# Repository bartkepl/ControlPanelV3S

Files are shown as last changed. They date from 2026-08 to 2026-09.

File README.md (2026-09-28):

# ControlPanelV3S — Hardware

KiCad project for the CAN-bus control panel board built around the Allwinner V3S (LicheePi Zero),
part of the [CANbusSensors](../) family of MPCC/MPSWP sensor-node projects. Two assembly variants
on one PCB: a handheld CAN-bus terminal and a VoIP endpoint. The next hardware iteration (Allwinner
T113-S3/4) will be a separate repo.

## Status: ready for prototype order

- Schematic and PCB layout done (4-layer, 120 × 75 mm), production files generated.
- Design review completed; DRC/ERC clean (remaining items reviewed and excluded as by-design).
- Hand assembly (2 fiducials on F.Cu for stencil alignment); crystal load caps C3/C4 are placeholders to be tuned at bring-up.

Production outputs: [schematic PDF](prod/sch/ControlPanel.pdf) · [PCB PDF](prod/pcb/ControlPanel.pdf) · [interactive BOM](prod/ibom/ControlPanel_ibom.html) · [gerbers](prod/ControlPanelV3S.zip)

## Renders

3D renders straight out of KiCad (`pcb/gen_media.kicad_jobset`), not photos — no boards have been
fabricated yet.

| Top | Bottom | Angle |
|---|---|---|
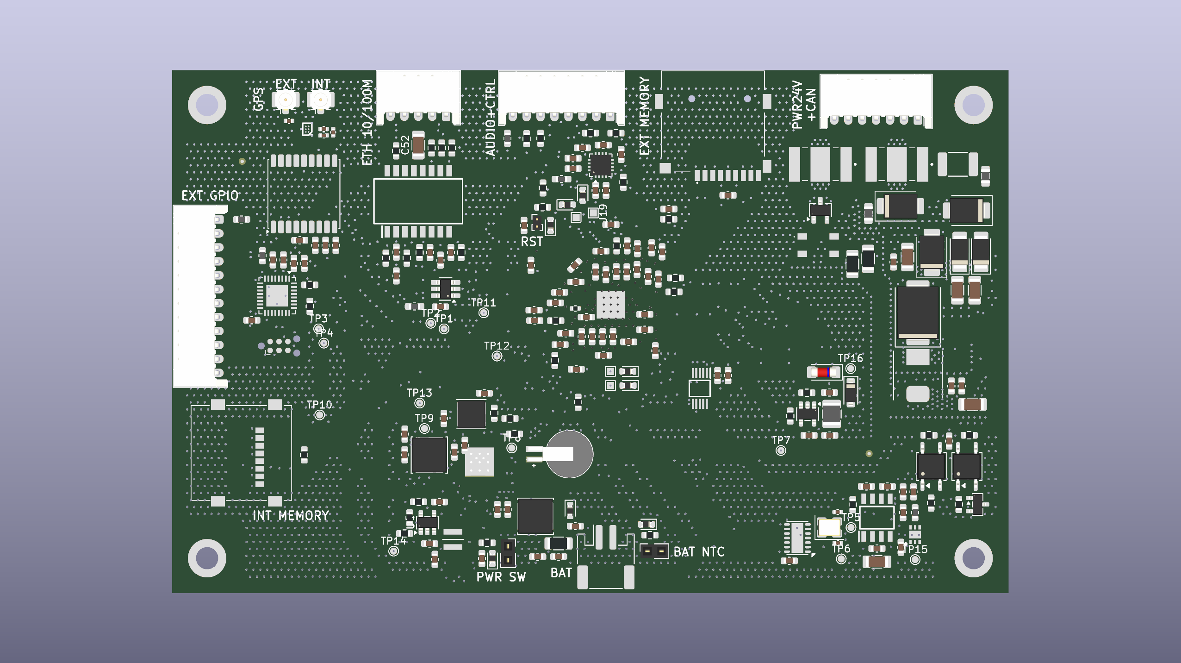
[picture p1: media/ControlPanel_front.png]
Top
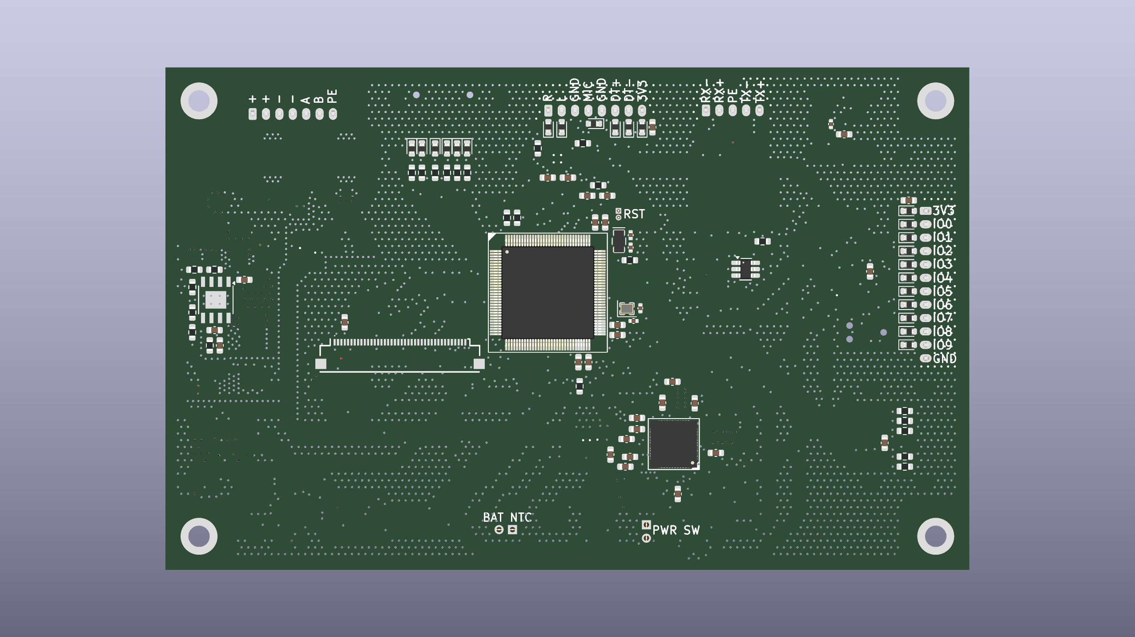
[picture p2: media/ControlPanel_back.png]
Bottom
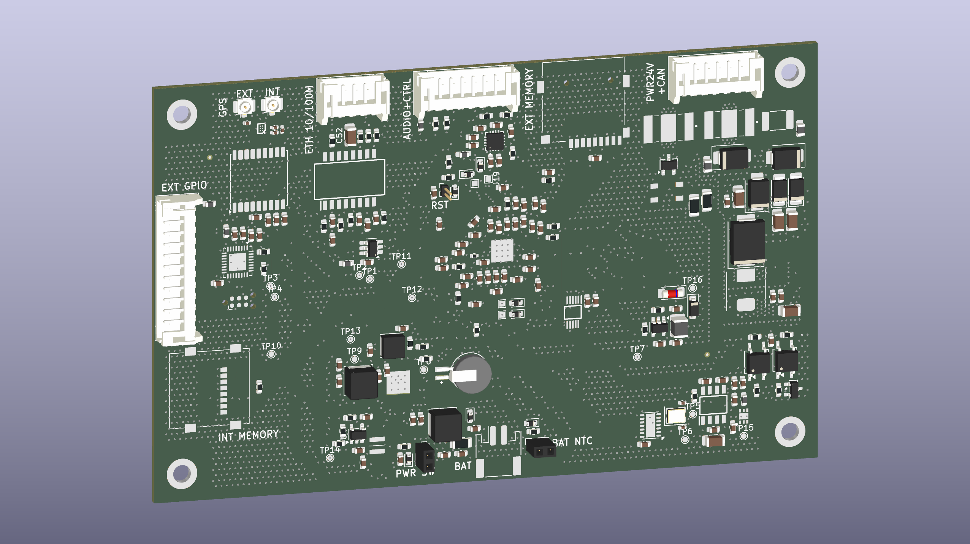
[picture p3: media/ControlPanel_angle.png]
Angle
|  |  |  |

## Layout

- **`pcb/`** - KiCad project: CPU, power, CAN transceiver front-end, display/touch, GPS, Ethernet,
  audio.
- **`doc/`** - hardware design decisions and reference material. Start with
  [doc/README.md](doc/README.md), which says which document is the source of truth for what.
- **`media/`** - 3D renders of the board, generated from the KiCad project.
- **`prod/`** - fabrication outputs (gerber + drill zip, BOM, interactive BOM, schematic/PCB PDFs).

## Firmware

The firmware that runs on this board (V3S-side kiosk app, CAN-bus device monitor, offline
navigation/map stack) lives in a separate, currently private companion repo.

## License

MIT for original work - see [LICENSE](LICENSE). All footprints live under `pcb/local_lib/` and
were either authored locally or sourced from SamacSys (`BAT_MS621FE-FL11E.kicad_mod`); 
FunKey S is referenced in `doc/` as a comparison point for the Allwinner V3S reference design 
(e.g. power-tree, boot ROM behavior).

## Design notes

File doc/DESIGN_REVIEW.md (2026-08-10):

# ControlPanel V3s — przegląd projektowy

**Projekt:** ControlPanel (KiCad 10.0.4, 11 arkuszy hierarchicznych, PCB 4-warstwowe 120 × 75 mm)
**Data:** 2026-08-01 (przebieg 3, 15:38)
**Analizatory:** `analyze_schematic.py`, `analyze_pcb.py --full`, `cross_analysis.py`,
`analyze_emc.py`, `analyze_thermal.py`, `simulate_subcircuits.py` (**ngspice**),
`diff_analysis.py` — oraz natywne **KiCad DRC/ERC** przez `kicad-cli 10.0.4`
**Wyniki surowe:** `analysis/2026-08-01_1538/`

---

## Werdykt

**Płytka jest elektrycznie i topologicznie gotowa.** Trzy niezależne mechanizmy kontroli są czyste:
KiCad ERC 0 naruszeń, KiCad DRC 0 elementów niepołączonych i 0 rozjazdów ze schematem,
ngspice 78/80 przebiegów pass bez ani jednego `fail`. Wszystkie blokery z poprzednich dwóch
przebiegów zostały naprawione i zweryfikowane w plikach.

**Do produkcji brakuje jednej rzeczy obowiązkowej: numerów MPN** (38 / 106 unikalnych części, 35,8 %).
Bez tego nie da się złożyć zamówienia ani zweryfikować pinoutów wobec kart katalogowych.

Poza tym otwarte pozostają wyłącznie pozycje jakościowe: jedna realna kolizja obrysów,
brak fiducialów, brak punktów testowych i brak oznaczeń na płytce.

---

## Przegląd

Terminal sterujący na SoC **Allwinner V3S** (U2, LQFP-128, DDR2 w obudowie) z PMIC **AXP209** (U7)
i koprocesorem **STM32L432KC** (U5). Peryferia: CAN FD (MCP2518FD + ATA6561 z przełączaną
programowo terminacją na przekaźnikach PhotoMOS), Ethernet 100BASE-TX przez wewnętrzny EPHY V3S
i magnetykę H1102NL, GPS MAX-M10S z LNA MAX2674, wzmacniacz słuchawkowy TPA6132A2, kontroler
dotyku NS2009, LCD RGB666 przez FPC 40-pin, dwa sloty microSD, zasilanie 9–60 V przez buck TPS54360.

309 komponentów (219 top / 90 bottom), 100 % SMD, 242 sieci, 5016 mm ścieżek, 3182 przelotki.

---

## Delta wobec poprzednich przeglądów

| Metryka | Przebieg 1 (00:28) | Przebieg 2 (15:03) | **Przebieg 3 (15:38)** |
|---|---|---|---|
| KiCad DRC — naruszenia | 16 | 26 | **12** |
| KiCad DRC — niepołączone | 0 | **2** | **0** |
| KiCad DRC — zwarcia | 0 | **8** | **0** |
| KiCad ERC | 0 | 0 | **0** |
| `cross_analysis` | 21 | 61 | **20** |
| `XV-002` (rozjazd wartości sch↔PCB) | — | 41 | **0** |
| PCB — zgłoszenia | 218 | 133 | **133** |
| SPICE | brak (LTspice = same skip) | 78/80 pass | **78/80 pass** |
| Przecinki dziesiętne w BOM | 23 | 3 | **0** |
| Pokrycie MPN | 35,2 % | 35,2 % | **35,8 %** |

### Naprawione i zweryfikowane w plikach

| Pozycja | Weryfikacja |
|---|---|
| **Y2 → kwarc 24 MHz** | `CX2016FB24000D0FZZ` (Kyocera, 24,000 MHz), footprint zmieniony na `Crystal_SMD_2016-4Pin_2.0x1.6mm`. Pozycja 36 mm od krawędzi — wymóg design guide V3S ≥ 25 mm zachowany. |
| **LDO24IN / LDO3IN AXP209** | Pady 13 i 40 `U7` → `IPSOUT`. Zapas napięcia dla LDO2/3/4 i PSRR dla GPS odzyskane. |
| **8 zwarć GND ↔ `/AUDIO/DATA-/GPIO1`** | `shorting_items` = 0. Przelotki zszywające przestały kolidować ze ścieżką In1.Cu. |
| **GPS `UART2_RX`/`UART2_TX`** | Pady 2 i 3 `U6` mają przypisane sieci, `unconnected_items` = 0, `track_dangling` = 0. |
| **Synchronizacja schemat → PCB** | `XV-002`: 41 → **0**. `C131` ma teraz `2.2u` po obu stronach. |
| **Przecinki dziesiętne** | 23 → 3 → **0**. Analizator poprawnie parsuje `32.768kHz`, ngspice potwierdził CL Y3 = 6,1 pF. Wykrywalność dzielników wzrosła z 4 do 7. |
| **Rozjazdy footprintów** | 7 → **3** (`R57`, `R68`, `R69`, `D43` naprawione; zostały `T1`, `U11`, `D42`). |

### ⚠ Sprostowanie do przeglądu nr 2

W poprzednim raporcie napisałem, że nakładki obrysów zostały naprawione („14 → 0, `PM-001`
zniknęło całkowicie"). **To było błędne.** Wyciągnąłem ten wniosek z porównania, które wypisywało
wyłącznie *zmienione* reguły — brak `PM-001` na liście oznaczał, że nic się nie zmieniło, a nie
że problem zniknął. Zestaw `PM-001` jest **identyczny we wszystkich trzech przebiegach**:
1 error + 13 warning + 3 info, ta sama lista par. Pozycja wraca jako otwarta.

Analogicznie `VP-001` (przelotki w padach): zestaw jest bit w bit taki sam jak w przebiegu 2 —
26 wystąpień, 21 unikalnych, żadne nie ubyło ani nie przybyło. W całym pliku `.kicad_pcb`
występuje jeden token `tenting`. Odnotowuję bez rozstrzygania, czy poprawka miała inny charakter
niż mierzy analizator.

---

## Wyniki krytyczne

| Waga | Problem | Sekcja |
|---|---|---|
| **BLOKER PRODUKCYJNY** | Pokrycie MPN 38 / 106 (35,8 %) — nie da się zamówić ani zweryfikować pinoutów | [Sourcing](#sourcing) |
| **WARNING** | Kolizja obrysów `C16` ↔ `J3` (2,321 mm²) — jedyna nakładka na poziomie error | [Rozmieszczenie](#rozmieszczenie) |
| **WARNING** | Brak fiducialów na obu stronach (219 + 90 elementów SMD, BGA 0,4 mm) | [DFM](#dfm-i-uwagi-produkcyjne) |
| **WARNING** | 0 punktów testowych na 232 sieci | [Testowalność](#testowalność) |
| **SUGESTIA** | Szyny `+3V3` (DCDC3) i `+3.3V` (LDO4) różnią się tylko kropką | [Drzewo zasilania](#drzewo-zasilania) |
| **SUGESTIA** | Brak nazwy płytki i oznaczenia rewizji (`board_text_count: 0`) | [Silkscreen](#silkscreen) |

Brak wyników na poziomie CRITICAL. Wszystkie trzy blokery z przeglądu nr 1 i cztery regresje
z przeglądu nr 2 są zamknięte.

---

## Weryfikacja natywna KiCad

Najmocniejszy dowód w przeglądzie — silnik łączności KiCada, nie heurystyka analizatora.

```
kicad-cli pcb drc --severity-all  →  12 naruszeń, 0 niepołączonych, 0 rozjazdów ze schematem
kicad-cli sch erc --severity-all  →  0 naruszeń
```

Wszystkie 12 naruszeń to kwestie kosmetyczne lub biblioteczne:

| Typ | Liczba | Szczegóły |
|-----|---|---|
| `silk_edge_clearance` | 7 | Opis `J13` przycięty krawędzią płytki |
| `lib_footprint_mismatch` | 3 | `T1`, `U11`, `D42` |
| `text_height` | 2 | `U2` i `U4` — 0,579 mm przy minimum 0,8 mm |

ERC ma wyłączone tylko 3 reguły (`footprint_filter`, `four_way_junction`, `simulation_model_issue`),
więc „0 naruszeń" ma realną wartość dowodową.

### Czego DRC nadal nie sprawdza

W `.kicad_pro` część ograniczeń jest ustawiona na zero — odpowiednie testy nie mają czego łamać:

| Reguła | Ustawienie | Konsekwencja |
|---|---|---|
| `min_copper_edge_clearance` | 0,0 mm | Miedź może dotykać krawędzi (świadoma decyzja — producent cofnie wylewkę) |
| `solder_mask_to_copper_clearance` | 0,0 mm | Brak kontroli maski względem miedzi |
| `min_connection` | 0,0 mm | Brak kontroli szerokości połączenia z polem |

Dodatkowo wyłączone: `silk_overlap`, `silk_over_copper`, `missing_courtyard`,
`footprint_type_mismatch`, `track_not_centered_on_via`, `footprint_filters_mismatch`.

---

## Podsumowanie komponentów

| Typ | Liczba |
|-----|---|
| Kondensatory | 137 |
| Rezystory | 69 |
| Diody (w tym TVS/GDT) | 40 |
| Układy scalone | 17 |
| Złącza | 14 |
| Cewki / koraliki ferrytowe | 7 / 7 |
| Kwarce | 3 |
| Pozostałe (transformator, bateria, bezpiecznik, tranzystor, filtr, TP, otwory montażowe) | 15 |

**309 komponentów, 105 unikalnych, 4 oznaczone DNP.**
Obudowy: 0603 × 222, 0402 × 12, 1206 × 9, SOT-23 × 6, QFN × 4, SOP/SOIC × 5, LQFP × 1,
**BGA × 1**, 1210/1812 × 2. Złożoność montażu **40/100**, 18 elementów trudnych, 62 unikalne footprinty.

---

## Drzewo zasilania

```
J12 (pin 1,2) ── F1 (PTC 2A) ── FB2 ── D8 ∥ D11 (PMEG6030EP, ochrona odwrotnej polaryzacji)
   │                                       │  D7/D10 (SMBJ36A TVS)
   │  GD1 (GDT 3R090-5S) → Earth           ▼
   │  D5 (SMBJ33CA)                     DC_IN  (9–60 V)
   │                                       │
   └── (pin 3,4) ── FB4 ── GND             ▼
                                  U3 TPS54360  buck, fsw ≈ 597 kHz (R34 = 162k)
                                    FB: R36 53.6k / R37 10.2k, Vref 0,8 V
                                    → Vout = 0,8 × (1 + 53,6/10,2) = 5,004 V  ✓
                                    EN: R38 523k / R39 84.5k → Von ≈ 9,3 V / Voff ≈ 7,5 V
                                       │
                                    ACIN 5,0 V
                                       │
                                 U7 AXP209 (PMIC, sterowany po I2C TWI1)
                                       │
                                    IPSOUT ──┬── U4 SY8088 buck → +1V8 (VCC-DRAM ×12)
                                             │      FB: R32 200k / R33 100k, Vref 0,6 V
                                             │      → 0,6 × 3 = 1,800 V  ✓ (ngspice: Vfb 0,600 V)
                                             │      EN: R31 100k pull-up z +3V0
                                             │
                                             ├── DCDC2 → +1V25   (VDD-CPU ×8, VDD-SYS ×6)
                                             ├── DCDC3 → +3V3    (VCC-IO ×4, VCC-PE ×2, VCC-USB,
                                             │                    VCC-MCSI, HPVCCIN, NS2009, U8)
                                             ├── LDO1  → +3V3_AO (VCC-RTC, GPS V_BCKP)
                                             ├── LDO2  → +3V0    (AVCC, VCC-PLL)          ✓ z IPSOUT
                                             ├── LDO3  → +3V3_GPS (MAX-M10S)              ✓ z IPSOUT
                                             └── LDO4  → +3.3V   (STM32, MCP2518FD,
                                                                  ATA6561 VIO, TPS61240)  ✓ z IPSOUT

    +3.3V ── IC2 TPS61240 boost → +5V (ATA6561 VCC, sterowanie PhotoMOS)
    +3V3  ── U8 TPS61041 boost  → VLED+ (podświetlenie LCD), FB przez R42 62 Ω
                                   ILED = 1,233 V / 62 Ω = 19,9 mA, D3 BZV55C24 jako klamra
```

**Wejścia LDO2/LDO3/LDO4 są teraz zasilane z `IPSOUT`** — zgodnie z `doc/AXP209_PINOUT_ROZPISKA.md`
(w. 145 i 169). W przeglądzie nr 1 były podpięte do wyjścia DCDC3, co dawało LDO3 i LDO4 zerowy
zapas napięcia (3,3 V → 3,3 V) i kasowało PSRR na szynie GPS. Naprawione.

### Uwaga do nazewnictwa

`+3V3` (DCDC3, 39 pinów zasilających) i `+3.3V` (LDO4, 14 pinów) to dwie różne szyny o nazwach
różniących się jedną kropką. Dokumentacja projektu sygnalizuje to sama
(`AXP209_PINOUT_ROZPISKA.md` w. 374). Przy każdej przyszłej zmianie to realne ryzyko podłączenia
czegoś do niewłaściwej szyny 3,3 V. Propozycja: `+3V3_IO` / `+3V3_CAN`.

---

## Weryfikacja symulacyjna (ngspice)

`D:\Spice64\bin\ngspice.EXE`, **80 symulacji w 7,7 s: 78 pass, 2 warn, 0 fail, 0 skip.**

| Kategoria | Liczba | Wynik |
|---|---|---|
| Filtry RC | 22 | wszystkie w granicach błędu **0,23–0,35 %** |
| Dzielniki napięcia | 4 | `R27/R28` → 0,900 V · `R32/R33` → 0,600 V · `R6/R7` → 0,0971 V (błąd 0,001 %) |
| Sprzężenie zwrotne regulatora | 1 | `R32/R33` (SY8088) → Vfb 0,600 V, błąd **0,0 %** → **Vout 1,800 V potwierdzone** |
| Kwarc | 1 | `Y3` 32 768 Hz, CL = 6,1 pF |
| Odsprzęganie | 11 szyn | impedancje niżej |
| Prąd rozruchowy | 5 szyn | wszystkie ustalają się na wartości docelowej, szczyty 28–107 mA |
| Tranzystor | 1 | `Q2` (BSS138): Vth 1,542 V, Ion 3,3 mA |
| Urządzenia ochronne | 33 | pass |
| Filtry LC | 2 | **2 × warn — fałszywe, patrz niżej** |

Impedancje odsprzęgania (minimum modułu):

| Szyna | Z_min | Szyna | Z_min |
|---|---|---|---|
| IPSOUT | 4,5 mΩ | +1V8 | 12,6 mΩ |
| ACIN | 5,9 mΩ | +3V0 / +3V3_GPS | 18,5 mΩ |
| +1V25 | 7,7 mΩ | +3.3V | 19,0 mΩ |
| +5V | 8,0 mΩ | +BATT | 31,6 mΩ |
| +3V3 | 9,1 mΩ | **+3V3_AO** | **67,2 mΩ** |

`+3V3_AO` jest najsłabsza, ale to szyna always-on zasilająca wyłącznie VCC-RTC V3S i V_BCKP
modułu GPS — pobór rzędu mikroamperów, impedancja bez znaczenia.

**Oba ostrzeżenia są fałszywe.** `L10/C12` i `L10/C21` wykryte jako filtr LC o Q = 115
i szczycie +40 dB przy 23,2 / 73,4 kHz. `L10` (4,7 µH) to dławik przetwornicy ładowarki AXP209
na węźle LX1, nie filtr — w rzeczywistości tłumią go pętla regulacji AXP209 i impedancja
akumulatora, których model ideal-passive nie uwzględnia.

---

## Analiza sygnałowa

### Ethernet 100BASE-TX

Standardowa topologia dla wewnętrznego EPHY V3S (jak Lichee Zero / FunKey S), prześledzona
sieć po sieci:

```
U2.89–92 (ETH_RX_N/P, ETH_TX_N/P)
   ├─ RX: → U10 (USBLC6) → RD+/RD− → C73/C83 (6.8n, sprzężenie AC) → T1.6/T1.8
   │       bias: T1.7 (RD CT) → R13/R15 (82 Ω) → RD+/RD−, C45 do masy
   └─ TX: → U9 (USBLC6) → TD+/TD− → T1.1/T1.3
           bias: +3V3 → FB1 → węzeł → R17 (10 Ω) → T1.2 (TD CT)
                 R14/R16 (49.9 Ω) → TD−/TD+
                 ten sam węzeł zasila piny VBUS U9 i U10 (odniesienie klamry) ✓

Strona liniowa: T1.9/11 (RX±), T1.14/16 (TX±) → J13
Bob Smith: R20/R26 (150 Ω) z RX± + R18/R19 (75 Ω) z T1.10/T1.15 → węzeł → C52 (1n/2kV) → Earth
```

Dopasowanie par:

| Para | Rozjazd | Ocena |
|---|---|---|
| `ETH_TX_P` / `ETH_TX_N` | asymetria przelotek 0 vs 2, przejść warstw 1 vs 2 | zamknięte decyzją — bez znaczenia dla 10/100M |
| `/ETH/RD+` / `RD−` | 2,1 mm (30 %) | w tolerancji 100BASE-TX |
| `/ETH/TD+` / `TD−` | 2,3 mm (27 %) | w tolerancji 100BASE-TX |

### CAN FD

```
U2 (SPI: PC0–PC3) → U1 MCP2518FD (Y1 20 MHz ✓, VDD +3.3V)
                  → IC3 ATA6561 (VCC +5V, VIO +3.3V — logika odniesiona do VIO ✓)
                  → R44/R45 (10 Ω pulse-proof) → FL1 (dławik wspólny) → GD2 → J12.5/J12.6
                     C40/C41 (4.7p) do masy, D9 CDSOT23-T24CAN przy złączu

Terminacja przełączana programowo:
   CAN_H → R22 (59 Ω) → U701 (PhotoMOS) → węzeł ── C39 (4.7n) → GND
   CAN_L → R21 (59 Ω) → U702 (PhotoMOS) → węzeł
   Razem 118 Ω — terminacja dzielona z bypassem AC
   Sterowanie: +5V → R23 (560 Ω) → LED U701 → LED U702 (szeregowo)
```

### Pozostałe interfejsy

| Interfejs | Realizacja | Stan |
|---|---|---|
| I2C (TWI1) | V3S PE21/PE22 + STM32 PB6/PB7 + NS2009 + AXP209, pull-upy `R10`/`R11` 2,2 kΩ do +3V3 | ✓ zgodne z kartą AXP209; multi-master świadomy (STM32 jako slave z przerwaniem) |
| USB | `U2.110/111` → `J19`/`J20` (pady testowe 1 × 1 mm), TVS `D24`/`D25` 2,2–2,9 mm | tylko do trybu FEL, świadome |
| LCD | RGB666 przez FPC 40-pin `J9`, masy rozłożone równomiernie | ✓ |
| microSD ×2 | `J1` (SDC1) i `J2` (SDC0) | ✓ |
| Audio | TPA6132A2 + `J14` (8-pin, masy na pinach 3 i 5, przeplecione) | ✓ |
| GPS | MAX-M10S + LNA MAX2674, UART2 do V3S | ✓ połączenie przywrócone |
| Debug | `J11` TC2030 (SWD do STM32), `J16`/`J17` (UART0 V3S) | ✓ |

### Kwarce

| Ref | Wartość | Podłączenie | Kondensatory | Ocena |
|-----|---|---|---|---|
| `Y2` | **CX2016FB24000D0FZZ (24 MHz)** | `U2.74` X24MOUT / `U2.75` X24MIN | `C3`, `C4` = 18 pF | ✓ naprawione |
| `Y1` | 3225-20M-SR (20 MHz) | `U1.5`/`U1.6` (MCP2518FD) | `C1`, `C2` = 18 pF | ✓ 20 MHz poprawne dla MCP2518FD |
| `Y3` | 32.768 kHz (WTL1X80739BEL) | `U2.95`/`U2.96` | `C48`, `C49` = 6,2 pF | ✓ ngspice: CL 6,1 pF |

`Y2` leży 36 mm od krawędzi przy wymogu ≥ 25 mm z design guide V3S. Wartości `C3`/`C4` (18 pF)
warto skonfrontować z CL nowego kwarcu przy okazji uzupełniania MPN.

---

## Analiza zasilania

### Odsprzęganie

| Szyna | Kondensatorów | Pinów `power_in` | Wartości |
|---|---|---|---|
| +1V8 (VCC-DRAM) | 8 | 17 | 4 × 100n, 2 × 1u, 2 × 10u |
| +1V25 (VDD-CPU/SYS) | 14 | 27 | 6 × 100n, 4 × 1u, 3 × 10u, 1n |
| +3V3 (VCC-IO) | 19 | 39 | 14 × 100n, 3 × 10u, 1u, 1n |
| +3.3V | 8 | 14 | 5 × 100n, 1u, 2.2u, 4.7u |
| +3V0 | 4 | 8 | 2 × 100n, 4.7u, 10u |
| +3V3_GPS | 4 | 4 | 2 × 100n, 4.7u, 10u |
| +3V3_AO | 3 | 6 | 2 × 100n, 1u |
| +5V | 3 | 3 | 100n, 4.7u, 10u |
| IPSOUT | 9 | 12 | 7 × 10u, 2 × 220n |
| ACIN | 4 | 4 | 100n, 3 × 10u |
| +BATT | 2 | 3 | 10u, 1u |

Szyna `+1V8` ma 4 × 100 nF na 12 pinów VCC-DRAM V3S — poniżej guideline'u Allwinnera
(~1 × 100 nF na pin) i zgodnie ze zgłoszeniem EMC `PD-001`. **Zamknięte decyzją projektanta**
(rozwiązanie zgodne z inną, działającą płytką) — odnotowane, nie otwieram ponownie.

### Odległości kondensatorów odsprzęgających

`C85` @ `U7` 0,21 mm · `C109` @ `U2` 0,21 mm · `C120` @ `U5` 0,24 mm · `C31` @ `U9` 0,28 mm —
bardzo dobrze. Kondensatory TPA6132A2 (`C129`/`C130`/`C131`) w promieniu 2,9–3,6 mm przy
wymaganych przez TI 5 mm ✓.

Nowe zgłoszenie **`DC-003`**: `C37` (100 nF na `+3V3_GPS`) leży daleko od przelotki masy.
Przy odsprzęganiu układu RF warto dołożyć przelotkę bezpośrednio przy padzie masy.

---

## Analiza PCB

### Stackup

| Warstwa | Typ | Grubość | Wykorzystanie |
|---|-----|---|---|
| F.Cu | signal | 0,035 mm | 1273 segmenty |
| prepreg 7628 | εr 4,4 | 0,2104 mm | |
| In1.Cu | signal | 0,0152 mm | 224 segmenty wewnątrz wylewki GND |
| core | εr 4,6 | 1,065 mm | |
| In2.Cu | power | 0,0152 mm | 1 segment — praktycznie lita płaszczyzna |
| prepreg 7628 | εr 4,4 | 0,2104 mm | |
| B.Cu | signal | 0,035 mm | 1067 segmentów |

Suma **1,586 mm** (standard 1,6 mm). Wykończenie **HAL lead-free** — świadoma decyzja
(montaż ręczny, koszt ENIG). Wylewka GND obejmuje wszystkie cztery warstwy; nie ma dedykowanej
płaszczyzny zasilania, wszystkie szyny prowadzone ścieżkami.

`In1.Cu` niesie 224 segmenty w 24 sieciach wewnątrz wylewki GND, co wycina szczeliny
w płaszczyźnie odniesienia dla sygnałów na F.Cu odległej o 0,21 mm. To źródło zgłoszeń
`GP-001` (52 error + 54 warning) i `SU-001`. **Zamknięte decyzją projektanta** — przeniesiono
na B.Cu co się dało, resztę obudowano przelotkami zszywającymi.

### Przelotki

| Rozmiar (średnica / otwór) | Liczba | Pierścień |
|---|---|---|
| 0,6 / 0,3 mm | 3125 | 0,15 mm |
| 0,4 / 0,3 mm | 57 | 0,05 mm |

Obie geometrie mieszczą się w bieżących możliwościach JLCPCB, który formułuje ograniczenie
jako **różnicę** średnicy i otworu, nie jako pierścień:

> Via diameter should be **0.1 mm** (0.15 mm preferred) larger than Via hole size.

0,4 − 0,3 = 0,1 mm → minimum spełnione. Opcja zamówienia `0.3mm/(0.4/0.45mm)` jest domyślna
i bez dopłaty. Nota o wyższej cenie dotyczy tylko otworów 0,15 mm oraz 0,2/0,25 mm ze średnicą
< 0,45 mm — tu otwór to 0,3 mm.

> ⚠ **Ograniczenie 0,1 mm jest specyficzne dla JLCPCB.** PCBWay wymaga pierścienia ≥ 0,1 mm
> (różnicy 0,2 mm) — tam te 57 przelotek nie przeszłoby. Przy zmianie producenta sprawdzić ponownie.

### Rozmieszczenie

219 elementów na F.Cu, 90 na B.Cu, gęstość 2,4 / 1,0 na cm². Na spodzie leżą najważniejsze
układy: `U2` (V3S), `U7` (AXP209), `U3` (TPS54360), `J9` (FPC LCD), `U9`.

**Nakładki obrysów — 17 par, niezmienione we wszystkich trzech przebiegach:**

| Para | Powierzchnia | Waga |
|---|---|---|
| **`C16` ↔ `J3`** | **2,321 mm²** | **error** |
| `U701` ↔ `C32` / `C39`, `U702` ↔ `C39` | 0,71–0,77 mm² | warning |
| `J4` ↔ `J3`, `C131` ↔ `U11`, `U5` ↔ `C117`, `D30` ↔ `J3`, `R40` ↔ `J3` | 0,18–0,41 mm² | warning |
| `FB2`/`GD1` ↔ `F1`, `IC2` ↔ `C47`, `C35` ↔ `IC3`, `R4` ↔ `BT1` | < 0,02 mm² | warning |
| `U6` ↔ `C36`/`C37`/`C38` | 0,007 mm² | info — obrys `U6` zawiera strefę zakazu RF, nie kolizja mechaniczna |

Realnego sprawdzenia wymaga wyłącznie **`C16` ↔ `J3` (2,321 mm²)** — reszta to zbyt hojne
obrysy bibliotek.

**Złącza przy krawędzi** (`PM-002`, 6 sztuk): `J1` −0,9 mm, `J13` −0,34, `J14` −0,3,
`J15` −0,25, `J12` 0,2, `J3` 0,05. Dla JST PH w wersji bocznej i U.FL zamierzone,
zamknięte decyzją („w marginesie błędu").

### Termika

| Układ | Obudowa | Przelotki | Minimum | Ocena |
|---|---|---|---|---|
| `U3` TPS54360 | SO PowerPAD-8 | 9 | 9 | ✓ |
| `U5` STM32L432 | QFN-32 EP | 5 | 5 | ✓ |
| `U11` TPA6132A2 | WQFN-16 EP | 4 | 5 | zamknięte decyzją (25 mW/kanał) |
| `U1` MCP2518FD | DFN-14 EP | 2 | 5 | pobór znikomy |

`analyze_thermal.py`: 0 zgłoszeń, wynik 100/100 — **ale bez danych o mocy strat**
(brak MPN i kart katalogowych). To brak informacji, nie potwierdzenie.

### Testowalność

**0 punktów testowych na 232 sieci** (`TE-001`). Są tylko 4 pady kontrolne:
`J16`/`J17` (UART0_TX/RX) i `J19`/`J20` (USB_D_P/D_N), plus `J11` (TC2030 SWD do STM32).
Brak dostępu do szyn zasilania utrudni bring-up i wyklucza ICT.

### Silkscreen

`board_text_count: 0` — na płytce nie ma żadnego tekstu poza oznaczeniami elementów.
Brak nazwy płytki i oznaczenia rewizji. Świadoma decyzja („płytka będzie bez oznaczeń"),
ale rewizja w rogu obrysu kosztuje zero i rozróżnia serie.

---

## EMC

`analyze_emc.py`: 202 zgłoszenia (59 error, 112 warning, 31 info), 13 kategorii.
Struktura praktycznie niezmieniona od przeglądu nr 1.

### Zgłoszenia potwierdzone geometrią, zamknięte decyzją projektanta

| Reguła | Treść | Decyzja |
|---|---|---|
| `SW-003` | Duża pętla mocy `U3` (`C123` 10,55 mm, `L7` 10,63 mm od układu) i `U8` | „lepiej nie będzie" |
| `ES-001` | `D9` (TVS CAN) 19,2 mm od `J12`, `GD2` 15,5 mm, `FL1` 23,1 mm | „ciężko poprawić w dobry sposób" |
| `BE-001` | Sygnały przy krawędzi: `ETH_RX_P`, `ETH_TX_P`, `SDC0.CLK` (error) + 5 warning | „nic to nie zmienia" |
| `GP-001` / `SU-001` | 224 segmenty na In1.Cu wycinające szczeliny w płaszczyźnie odniesienia | przeniesiono co się dało + przelotki zszywające |
| `PD-001` | Antyrezonans PDN na `+1V8` | odsprzęganie jak na działającej płytce |
| `CK-001` / `CK-003` | Zegary `U1.OSC1` na warstwie zewnętrznej, `J2.CLK` blisko złącza | — |

### `GP-005` — dwie domeny masy

`GND` (261 pinów) i `Earth` (9 pinów: `H1`–`H4`, `GD1`, `GD2`, `C52`, `J12.7`, `J13.3`).
Sprzężenie przez koralik ferrytowy oraz `C52` (1 nF / 2 kV). Poprawna topologia pływającej masy
szasy, potwierdzona przez projektanta.

---

## Fałszywe alarmy i decyzje recenzenta

| Zgłoszenie | Liczba | Uzasadnienie odrzucenia |
|---|---|---|
| **`VM-001`** „3.3V / 1.8V domain crossing" | 13 | Analizator widzi, że `U2` jest zasilany z +3V3, +1V8, +1V25 i +3V0, i zakłada, że GPIO może być 1,8 V. **Wszystkie banki I/O V3S (VCC-IO0–3, VCC-PE0/1) są na +3V3**, a +1V8 zasila wyłącznie VCC-DRAM (DDR2 w obudowie, brak sygnałów zewnętrznych). |
| **`VM-001`** „5.0V / 3.3V domain crossing" | 3 | Nety TXD/RXD/STBY między MCP2518FD a ATA6561. ATA6561 ma osobny pin **VIO na +3.3V**; VCC = +5V zasila tylko stopień liniowy. |
| **`PP-001`** `U11.12` (HPVDD), `U11.8` (HPVSS) | 2 | Potwierdzone kartą katalogową TI: *„Connect the HPVDD pin only to a 2.2 μF, X5R or better, capacitor. **Do not connect HPVDD to an external voltage supply.**"* To wyjścia wewnętrznej pompy ładunkowej. |
| **`PP-001`** `U3.2` (VIN na `DC_IN`) | 1 | `DC_IN` to surowa szyna wejściowa, nie symbol power. ERC KiCada z włączonym testem „power pin not driven" zgłasza 0 naruszeń. |
| **`PS-002`** „plane split" dla +3.3V, +3V3, +3V0, +3V3_GPS, +1V25 | 5 | Union-find analizatora daje fałszywe rozłączenia — udowodnione w przeglądzie nr 1 (ścieżka +3V3 kończy się 0,062 mm od pada `FB1.1`, a analizator twierdzi, że jest odcięta). Szyny są prowadzone ścieżkami, nie płaszczyznami; „12 wysp" oznacza topologię gwiazdy. |
| **`PS-002`/`GP-001`** dla GND | 55+ | Wszystkie 261 padów GND leży na jednej wyspie. |
| **`RP-002`** „crosses +3.3V plane gap" | 6 | `+3.3V` nie jest płaszczyzną odniesienia — jest nią GND na In1/In2. Sygnał nie „widzi" granic wysp szyny, do której się nie odnosi. |
| **`KO-001`** `H1`–`H4` w strefie zakazu | 4 | Cztery strefy 10 × 10 mm w narożnikach mają `copperpour: not_allowed` i są celowo narysowane **wokół** otworów montażowych. |
| **`DFM-001`/`DFM-002`** „annular ring 0,05 mm poniżej minimum" | 2 | Reguła analizatora (`standards-compliance.md`, „verified 2025-01") podaje 0,125 mm. Bieżąca specyfikacja JLCPCB wymaga **różnicy średnica − otwór ≥ 0,1 mm** — spełnione. Stąd też zawyżony poziom DFM `challenging`; realnie **`standard`**. |
| **`CG-AUD`** „J12/J13 has no ground pins" | 2 | Oba mają pin `Earth` (`J12.7`, `J13.3`) — analizator nie rozpoznaje `Earth` jako masy. |
| **`ES-001`** „U9/U10 far from J10/J11" | 2 | USBLC6 chronią pary EPHY po stronie SoC; `J10` to 2-pinowy header RESET, `J11` to Tag-Connect. Zestawienie bez sensu. |
| **`PU-001`** brak pull-upów | 8 | `U3.EN` ma dzielnik UVLO `R38`/`R39`, `U5.NRST` ma `C121`, `U6.SDA/SCL` są na magistrali z `R10`/`R11`. `U6.EXTINT`/`LNA_EN` — piny nieużywane. |
| **`DP-005`** `Y1+`/`Y1−`, `VLED+`/`VLED−` | 2 | To nie są pary różnicowe — kwarc RTC i zasilanie podświetlenia LCD. |
| **`PM-001`** `U6` ↔ `C36`/`C37`/`C38` | 3 | Obrys `U6` zawiera strefę zakazu RF — analizator sam to oznacza jako `info`. |
| **ngspice** `L10/C12`, `L10/C21` | 2 | `L10` to dławik przetwornicy ładowarki AXP209 (LX1), nie filtr LC. Model ideal-passive nie zna pętli regulacji ani impedancji akumulatora. |

---

## Sourcing

| Metryka | Wartość |
|---|---|
| Unikalnych części | 106 |
| Z numerem MPN | **38 (35,8 %)** |
| Z kartą katalogową | 20 (18,9 %) |

Zgłoszenie **`SS-001`** (error): pokrycie MPN poniżej 50 % — **bramka przedprodukcyjna**.
Brakuje m.in. dla `U2`, `U3`, `U4`, `U5`, `U6`, `U8`, `Y1`, `J7`, `J8`, `J10`, `L1`, `L3`
i większości elementów biernych.

Konsekwencje wykraczają poza samo zamówienie: bez MPN nie da się zsynchronizować kart
katalogowych, a wtedy **weryfikacja pinoutów pozostaje kontrolą spójności, nie poprawności**.

---

## DFM i uwagi produkcyjne

| Parametr | Wartość | Uwaga |
|---|---|---|
| Warstwy | 4 (F.Cu / In1.Cu / In2.Cu / B.Cu) | |
| Wymiary | 120 × 75 mm | powyżej progu 100 × 100 mm → dopłata |
| Grubość | 1,586 mm | standard 1,6 mm |
| Miedź | 35 µm zewnętrzne, 15,2 µm wewnętrzne | 1 oz / 0,5 oz |
| Wykończenie | HAL lead-free | świadoma decyzja (montaż ręczny) |
| Min. ścieżka | 0,15 mm | ✓ powyżej 0,127 mm |
| Min. wiert | 0,3 mm | ✓ powyżej 0,2 mm |
| Min. przelotka | 0,4 / 0,3 mm (57 szt.) | ✓ opcja `0.3mm/(0.4/0.45mm)`, bez dopłaty |
| Poziom DFM | **standard** | analizator zwraca `challenging` przez nieaktualną regułę pierścienia |
| Szablon | wymagany | 100 % SMD, 309 elementów; przy BGA 0,4 mm rozważyć ramkowy |
| Montaż | dwustronny (219 / 90) | **brak fiducialów** |

**Fiduciale** (`FD-001`, error na obu stronach): F.Cu 207 elementów SMD, B.Cu 90,
najdrobniejszy pad 0,20 mm, obecny BGA 0,4 mm (`IC4` MAX2674). Przy montażu maszynowym
to blokada precyzyjnego pick-and-place — 3 na stronę, w narożnikach, asymetrycznie.
Przy montażu ręcznym pozycja bez znaczenia.

**26 nietentowanych przelotek w padach** (`VP-001`), zestaw niezmieniony od przeglądu nr 2:
`L8` (7 ×, dławik DCDC2), `IC2:7` (pad termiczny TPS61240), `C12`, `C137`, `C18`, `C20`, `C24`,
`C26`, `C43`, `C44`, `C45`, `C48`, `C74`, `C85`, `D3:2`, `D8:1`, `J7:2`, `J16:1`, `J17:1`, `R2:2`.
Wszystkie mają tę samą sieć co pad. Przy dużych padach `L8`/`IC2` ryzyko zaciągnięcia spoiwa
jest małe.

**3 rozjazdy footprintów z bibliotekami** (`T1`, `U11`, `D42`):
- `U11` — instancja w PCB ma **22 pady**, biblioteka `WQFN-16-1EP_..._ThermalVias` ma **26**.
  Brakujące 4 to wbudowane przelotki termiczne w padzie 17 (`thru_hole`, Ø 0,5 mm, wiert 0,2 mm).
  Aktualizacja z biblioteki je przywróci i podniosłaby licznik przelotek termicznych z 4 do 8.
- `T1`, `D42` — różnica czysto kosmetyczna (nowszy format grafiki w bibliotece).
  Pady identyczne pod względem liczby, typu, kształtu i rozmiaru.

---

## Nie wykonano / ograniczenia przeglądu

- **Karty katalogowe: brak katalogu `datasheets/`**, brak kluczy API dystrybutorów
  (`DIGIKEY_CLIENT_ID` itd. nieustawione) — zgłoszenie `DS-002` zasadne.
  Weryfikacja wobec kart producenta objęła wyłącznie **TPA6132A2** (przez wyszukiwanie webowe).
  Dla **V3S** i **AXP209** podstawą była własna dokumentacja projektu (`doc/*_ROZPISKA.md`) —
  solidna, ale wtórna. **Pozostałe stwierdzenia o pinach to kontrola spójności, nie poprawności.**
- **H1102NL, piny 10 i 15** — nierozstrzygnięte przez brak czytelnej karty (PDF producenta
  jest skanem bez warstwy tekstowej). Zamknięte decyzją projektanta.
- **Analiza termiczna** — 0 zgłoszeń przy zerowych danych o mocy strat. Wynik 100/100
  nie jest potwierdzeniem. Powtórzyć po uzupełnieniu MPN.
- **Audyt cyklu życia komponentów: nie wykonano** — brak kluczy API dystrybutorów.
- **Analiza Gerberów: nie wykonano** — w projekcie nie ma jeszcze plików produkcyjnych.
- **Weryfikacja mechaniczna** złączy wystających poza obrys wymaga modelu obudowy —
  poza zakresem analizy plików KiCad.

---

## Mocne strony projektu

1. **Trzy niezależne mechanizmy kontroli są czyste jednocześnie** — ERC 0, DRC 0 niepołączonych
   i 0 rozjazdów parity, ngspice 0 fail. Przy 309 elementach i 242 sieciach to solidny wynik.
2. **Wszystkie blokery z dwóch poprzednich przeglądów naprawione**, łącznie z czterema regresjami,
   które sam wprowadziłeś przy poprzedniej rundzie poprawek.
3. **Ochrona wejścia z prawdziwego zdarzenia:** PTC 2 A + dwa GDT do Earth + TVS
   SMBJ33CA/SMBJ36A + dwie Schottky PMEG6030EP równolegle na odwrotną polaryzację + koraliki.
4. **Przełączana programowo terminacja CAN** na przekaźnikach PhotoMOS, dzielona 59 + 59 Ω
   z bypassem AC 4,7 nF.
5. **Rozdzielona masa szasy `Earth`** z pierścieniem obwodowym, otworami montażowymi
   i sprzężeniem przez koralik oraz 1 nF / 2 kV.
6. **Odsprzęganie bardzo blisko układów** — 0,21–0,28 mm dla `U7`, `U2`, `U5`, `U9`.
7. **Wszystkie napięcia wyjściowe potwierdzone symulacyjnie**, nie tylko rachunkowo:
   `U4` → Vfb 0,600 V przy błędzie 0,0 %, 22 filtry RC w granicach 0,35 %.
8. **`In2.Cu` praktycznie lita** (1 segment ścieżki) — dobra ciągła płaszczyzna odniesienia.
9. **Kondensatory TPA6132A2 w promieniu wymaganym przez TI**, wartość HPVDD podniesiona
   do 2,2 µF zgodnie z kartą katalogową.
10. **Własna dokumentacja projektowa** (`doc/*_ROZPISKA.md`, 3334 wiersze) była na tyle dokładna,
    że pozwoliła wykryć dwie najpoważniejsze rozbieżności pierwszego przeglądu — kwarc 24 MHz
    i źródło LDO24IN/LDO3IN. To realny atut projektu.

---

## Luki analizatorów

1. **`connectivity_graph` (union-find) daje fałszywe rozłączenia.** Nie ufać `PS-002`
   ani pochodnym `RP-002`/`GP-001`. Autorytatywne: `kicad-cli pcb drc` → `unconnected_items`.
   W przebiegu 2 analizator raportował `routing_complete: true` przy dwóch realnie urwanych
   sieciach GPS — czyli myli się w obie strony.
2. **`validate_voltage_levels` przypisuje układowi wszystkie domeny, z których jest zasilany**,
   zamiast śledzić rail I/O konkretnego pinu — stąd 16 fałszywych alarmów na V3S i ATA6561.
3. **`analyze_thermal.py` zwraca 100/100 przy zerowych danych wejściowych.**
4. **`power_budget` zwraca 10 mA na każdy układ** (wartość domyślna) i błędnie przypisuje
   regulatory. Bezużyteczne bez kart katalogowych.
5. **Tabela możliwości fabów w skillu jest nieaktualna** (`standards-compliance.md`,
   „verified 2025-01") — podaje pierścień 0,125 mm, JLCPCB wymaga różnicy średnica−otwór ≥ 0,1 mm.
   Sprawdzać bieżącą stronę producenta.
6. **Backend LTspice nie emituje `.meas` ani nie parsuje `.raw`** — zwraca same `skip`.
   **Używać ngspice** (`D:\Spice64\bin`): te same 80 symulacji w 7,7 s, zero skipów.
7. **`XV-002` z `cross_analysis.py` to jedyny mechanizm łapiący rozjazd wartości schemat ↔ PCB.**
   KiCad DRC („schematic parity") sprawdza wyłącznie łączność, więc poprawka wartości wprowadzona
   tylko w schemacie przechodzi bez śladu i trafia do BOM-u ze starą wartością.
   W przebiegu 2 wykryło 41 takich rozjazdów, w tym `C131` (2,2 µF vs 1 µF).
   **Uruchamiać po każdej sesji edycji schematu.**
8. **`diff_analysis.py` wypisuje wyłącznie zmienione reguły** — brak reguły na liście oznacza
   „bez zmian", nie „naprawione". Ta pułapka spowodowała błędne sprostowanie w przeglądzie nr 2.
9. **Skrypty wymagają `PYTHONUTF8=1`** — bez tego wywalają się na polskich znakach
   i symbolach `→`/`²` przy domyślnym kodowaniu cp1250.

---

## Pozostałe działania

Lista do odhaczania była w `TODO.md` w katalogu głównym — plik został usunięty przy porządkach
poprzedzających podział repozytorium (2026-08-09), więc odnośnik prowadził w pustkę. Punkty z tej
sekcji są kompletne same w sobie i wystarczają jako lista kontrolna.

---

*Raport wygenerowany przez skill `kicad-happy:kicad` v1.3.1.
Surowe wyniki: `analysis/2026-08-01_1538/{schematic,pcb,cross_analysis,emc,thermal,spice}.json`.*

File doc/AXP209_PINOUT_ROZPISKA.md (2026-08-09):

# AXP209 — pełna rozpiska pinów, drzewo zasilania i połączenia z V3S

Dokument uzupełniający do [`TERMINAL_RECZNY_DECYZJE_PROJEKTOWE.md`](TERMINAL_RECZNY_DECYZJE_PROJEKTOWE.md) i
[`V3S_PINOUT_ROZPISKA.md`](V3S_PINOUT_ROZPISKA.md) — pełna rozpiska AXP209 (49 pinów: 48 + pad),
przydział DC/DC1-3 i LDO1-4, realne, prześledzone po przewodach wartości dławików/kondensatorów
trzech zewnętrznych przetwornic (TPS54360, TPS61240, SY8088), oraz połączenia AXP209↔V3S
(I2C, IRQ, PWRON, Reset, ADC pomiaru napięcia wejściowego).

Od 2026-07-25 trzecie urządzenie na tej samej magistrali TWI1 to STM32 (kontroler audio/
przycisków headsetu) — zob. sekcja 11 dok. nadrzędnego i
[`STM32_AUDIO_BUTTONS_ROZPISKA.md`](STM32_AUDIO_BUTTONS_ROZPISKA.md). Nie zmienia niczego w
drzewie zasilania AXP209 poniżej (STM32 zasilany z VCC-IO/DCDC3, nie z LDO AXP209).

Stan na 2026-07-24 (bez zmian od dodania STM32 2026-07-25, patrz akapit wyżej).

## Źródła i metoda

- **Numery pinów AXP209, nazwy, typ** — wyciągnięte z dwóch niezależnych symboli KiCad w tym
  repo: `pcb/local_lib/V3S_AXP209.kicad_sym` (symbol `AXP20`) i symbol biblioteczny
  `SamacSys_Parts:AXP209` osadzony w `pcb/cpu_pwr.kicad_sch`. **Obie transkrypcje pinów zgadzają
  się co do jednego** (49/49 pinów, te same numery/nazwy) — potraktowane jako mocne
  potwierdzenie poprawności numeracji. **Zgodnie z instrukcją, nie użyto realnego stanu
  narysowanego schematu ani z `cpu_pwr.kicad_sch`, ani z `cpu_pwr_wip.kicad_sch`** — oba są
  pracą w toku przy tym samym symbolu i nie zawierają jeszcze żadnych realnych połączeń (sam
  plik `cpu_pwr.kicad_sch` to w tej chwili tylko postawiony symbol IC1 + kilka wiszących flag
  zasilania, bez jednego wire'a) — użyto z niego wyłącznie definicji pinów symbolu, nie topologii.
- **Napięcia/prądy DC/DC1-3, LDO1-4, aplikacyjne wartości L/C, PWRON, IRQ, GPIO ADC, PWROK** —
  z oficjalnego **AXP209 Datasheet v1.0 (X-Powers)**, w tym bezpośredni odczyt schematu
  aplikacyjnego (§3, str. 5) i tabeli opisu pinów (§7, str. 12-13), skrzyżowany z jądrem Linux
  (`drivers/input/misc/axp20x-pek.c`) i realnym produktem **FunKey S** (AXP209 + V3s, ten sam
  chip, ten sam SoC), którego schemat i dyskusja projektowa („PMIC default voltages”) potwierdzają
  docelowe napięcia z tego dokumentu.
- **Realne wartości dławików/kondensatorów/dzielników trzech zewnętrznych przetwornic** — z
  **`pcb/dcdc.kicad_sch`** (jedyny plik z realnym schematem tych przetwornic, zgodnie z
  instrukcją), **prześledzone po współrzędnych pinów i realnych segmentach `(wire ...)`**, nie na
  oko po samej bliskości elementów na arkuszu — tam gdzie topologia była nieoczywista (dużo
  podobnie ułożonych rezystorów), zweryfikowano dokładnym dopasowaniem współrzędnych pinów IC do
  końców przewodów.
- Jak w poprzednich dokumentach: pozycje niepewne oznaczone **(do potwierdzenia)**.

---

## 1. Obudowa

**AXP209 — QFN-48, 6×6 mm, rozstaw 0.4 mm, z eksponowanym paddem (EP)**. Footprint w tym repo:
`QFN40P600X600X80-49N-D` (0.4mm pitch / 6.00×6.00mm / 0.8mm wysokości / 49 pól lutowniczych = 48
wyprowadzeń + 1 EP). EP (pin 49) — masa, lutować do płaszczyzny GND.

---

## 2. Drzewo zasilania AXP209 (zdecydowane w tej rozmowie)

| Regulator | Napięcie/prąd | Zasila | Sposób ustawienia napięcia |
|---|---|---|---|
| **DC/DC1** | — (nie jest to regulator wyjściowy) | **Wewnętrzna ładowarka PWM Li-ion** (fixed function) | brak — to nie jest konfigurowalna szyna, tylko dedykowany stopień ładowania baterii. Potwierdzone wprost w datasheet: *"DC-DC1: The PWM charger"*, w odróżnieniu od DC-DC2/DC-DC3 opisanych tam jako "adjustable". To dokładnie odpowiada założeniu z brifu: "DC/DC1 bateria to jest by design" |
| **DC/DC2** | **1.25 V / 1.6 A** | V3S **VDD-CPU + VDD-SYS** (rdzeń + logika systemowa — w każdym sprawdzonym projekcie referencyjnym to jedna fizyczna szyna, zob. `V3S_PINOUT_ROZPISKA.md`) | I2C, **REG23H[5:0]**, `Vout = 0.7 + kod×0.025V`, krok 25mV, brak zewnętrznego dzielnika FB |
| **DC/DC3** | **3.3 V / 1.2 A** | V3S **VCC-IO** (Port B/C/F/G); prawdopodobnie też VCC-USB, VCC-MCSI, VCC-PE (te same 3.3V co VCC-IO w tym projekcie, bez kamery CSI) — wzorem FunKey S, gdzie DC3 opisane jako `Vcc_io/Vcc_ephy/Vcc_mcsi/Vusb` | I2C, **REG27H[6:0]**, `Vout = 0.7 + kod×0.025V`, krok 25mV, brak zewnętrznego dzielnika FB |
| **LDO1** | **3.3 V, Always-On** | V3S **VCC-RTC** + **GPS MAX-M10C V_BCKP** (backup, sekcja 1.2/7 dok. nadrzędnego — jedna bateria/LDO obsługuje RTC hosta i GPS jednocześnie) | strap **LDO1SET → VINT** (patrz tabela pinów, pin 27) |
| **LDO2** | **3.0 V / 200 mA** | V3S **AVCC + VCC-PLL** (wg `V3S_PINOUT_ROZPISKA.md`); dodatkowo, jak ustalono przy śledzeniu `dcdc.kicad_sch`, sieć **`+3V0`** zasila też pull-up EN przetwornicy SY8088 (R31=100k) — czyli LDO2 pośrednio bramkuje włączenie regulatora DRAM | rejestr I2C (REG28H, do potwierdzenia dokładnego adresu) |
| **LDO3** | 3.3 V (typowo) | **propozycja: GPS (MAX-M10C)** — osobna, "cicha" domena liniowa z dala od przełączanych zakłóceń CAN/Ethernet, korzystne dla czułego frontendu RF GPS | — |
| **LDO4** | 3.3 V (typowo) | **propozycja: logika CAN** (MCP2518FD VDD + ATA6561 VIO, obie 3.3V, niski pobór) | — |

LDO3/LDO4 to **propozycja, nie ostateczna decyzja** — zgodnie z brifem ("do użycia według
uznania, nie mam planu"). Podział wynika z chęci elektrycznego odseparowania czułego GPS od
przełączanego cyfrowego CAN, każde na osobnej LDO. Do przemyślenia przy layoucie.

**Rezerwa prądowa LDO2 (200mA)**: obsługuje AVCC+VCC-PLL (pobór rzędu pojedynczych/kilkunastu mA)
oraz pull-up SY8088 EN (R31=100kΩ z `+3V0` — prąd rzędu ~30µA przy pełnym naładowaniu, pomijalny)
— zapas prądowy komfortowy.

---

## 3. Zewnętrzne przetwornice DC/DC (poza AXP209, schemat: `pcb/dcdc.kicad_sch`)

### 3.1 TPS54360DDA — 8.5-60V EXTERNAL → 5V/3.5A ACIN

Zasila **bezpośrednio pin ACIN AXP209** (potwierdzone: szyna VOUT tej przetwornicy łączy się wprost,
bez żadnych elementów pośrednich, z symbolem zasilania nazwanym „ACIN").

| Element | Wartość/ref | Rola |
|---|---|---|
| Wejście `DC_IN` | — | 8.5-60V zewnętrzne (M12, sekcja 2 dok. nadrzędnego) |
| C5, C6 | 2×2.2µF/100V | kondensatory wejściowe (równolegle, ~4.4µF, rating 100V pod transienty) |
| D1 | STPS5L60S (Schottky 5A/60V) | dioda catch/freewheel na węźle SW — **TPS54360 to układ asynchroniczny** (bez wewnętrznego synchronicznego FET-a dolnego), wymaga zewnętrznej diody |
| L7 | 8.2 µH | dławik wyjściowy (SW→VOUT) |
| C58 | 100n | kondensator bootstrap (BOOT) |
| C62, C66, C61 | 10µF + 10µF + 100n | kondensatory wyjściowe na szynie VOUT/ACIN |
| **R36 (top, 53.6k) / R37 (bottom, 10.2k)** | dzielnik FB | `Vout = 0.8V × (1 + 53.6k/10.2k) = 5.00 V` — **zgodne z etykietą "5V/3.5A"** |
| R35 (13k) + C71 (6.8nF), równolegle C68 (39pF) | sieć COMP | standardowa 3-elementowa kompensacja typu II na pinie COMP |
| R38 (523k, VIN→EN) / R39 (84.5k, EN→GND) | dzielnik EN/UVLO | próg załączenia ≈ 1.2V × (523+84.5)/84.5 ≈ **8.63 V** — **zgodne z etykietą "8.5-60V EXTERNAL"**; przetwornica załącza się sama napięciem wejściowym, bez sterowania software'owego |
| R34 (162k, RT/CLK→GND) | rezystor częstotliwości | pojedynczy rezystor ustawiający częstotliwość przełączania (nie dzielnik) |

Napięcie i próg UVLO **potwierdzone obliczeniowo i zgodne z opisami na schemacie** — brak
znalezionych niezgodności w tej gałęzi.

### 3.2 TPS61240DRVT — 3.3V → 5V/350mA CAN

Zasila VCC transceivera CAN (ATA6561, sekcja 5.4 dok. nadrzędnego).

| Element | Wartość/ref | Rola |
|---|---|---|
| Wejście | `+3.3V` | z DCDC3 AXP209 (pośrednio) |
| C46 | 2.2µF | kondensator wejściowy |
| L1 | 1 µH | dławik boost |
| C47 | 4.7µF | kondensator wyjściowy na `+5V`/CAN |
| **EN** | zwarte wprost do VIN (`+3.3V`) | **brak sterowania software'owego** — boost włącza się zawsze, gdy jest 3.3V |
| **FB** | zwarte wprost do VOUT | **stały wariant 5.0V** (nie regulowany zewnętrznym dzielnikiem) — potwierdzone, że to nie wersja adjustable |

Brak rezystorów w tej gałęzi w ogóle — żaden z R31-R39 do niej nie należy (sprawdzone
wprost po przewodach).

### 3.3 SY8088AAC — IPSOUT → 1.8V/1.0A Vdram

| Element | Wartość/ref | Rola |
|---|---|---|
| Wejście | `IPSOUT` | z AXP209 (bateria/ACIN, wybrane przez IPS) |
| C51 | 10µF | kondensator wejściowy |
| L2 | LQH3NPN2R2MMEL, 2.2µH (Murata, 1212/3030) | dławik wyjściowy |
| C54, C57 | 100n + 10µF | kondensatory wyjściowe na szynie `+1V8` |
| R31 (100k) | pull-up EN z `+3V0` (LDO2 AXP209) | włącza SY8088, gdy LDO2 jest aktywne — brak dzielnika, sam pull-up |
| **R32 (top, 200k) / R33 (bottom, 100k)** | dzielnik FB | `Vout = 0.6V × (1 + 200k/100k) = 1.80 V` — **zgodne z etykietą "1.8V/1.0A Vdram"** |

Przy pierwszym śledzeniu (2026-07-24) R32 miało wartość 100k (dawałoby policzone 1.20V zamiast
wymaganych 1.8V dla VCC-DRAM V3S) — poprawione tego samego dnia na 200k, zweryfikowane wprost w
`pcb/dcdc.kicad_sch`. Obecny stan liczy się poprawnie na 1.8V.

---

## 4. Pełna tabela pinów AXP209 (49 = 48 + EP)

| Pin | Nazwa | Gałąź / funkcja | Przydział w tym projekcie |
|---|---|---|---|
| 1 | SDA | I2C dane | → **TWI1** V3S (PE22), pull-up **2.2kΩ do 3.3V** (potwierdzone wprost w datasheet) |
| 2 | SCK | I2C zegar | → **TWI1** V3S (PE21), pull-up **2.2kΩ do 3.3V** |
| 3 | GPIO3 | GPIO ogólne (open-drain) | wolne — rezerwa |
| 4 | N_OE | Power on/off switch: GND=on, IPSOUT=off | **zewrzeć do GND** (zawsze zezwolone na włączenie; PWRON/PEK obsługuje miękki przycisk) |
| 5 | GPIO2 | GPIO ogólne | wolne — rezerwa |
| 6 | N_VBUSEN | VBUS→IPSOUT select: GND=wybierz VBUS, High=nie wybieraj | **podciągnąć do stanu wysokiego** (VINT/3.3V) — VBUS całkowicie nieużywane (sekcja 1.3 dok. nadrzędnego) |
| 7 | VIN2 | wejście DC/DC2 | z IPSOUT |
| 8 | LX2 | węzeł przełączający DC/DC2 | dławik **4.7µH** (cel <2.5V → większa indukcyjność wg zalecenia datasheet) |
| 9 | PGND2 | masa mocy DC/DC2 | GND |
| 10 | DCDC2 | wyjście/FB DC/DC2, ustawiane **I2C REG23H** | **1.25V/1.6A → V3S VDD-CPU+VDD-SYS**; kondensator ≥10µF X7R |
| 11 | LDO4 | wyjście LDO4 | propozycja: **CAN logika 3.3V**; kondensator 4.7µF |
| 12 | LDO2 | wyjście LDO2 | **3.0V/200mA → V3S AVCC+VCC-PLL** + pull-up EN SY8088; kondensator 4.7µF |
| 13 | LDO24IN | wspólne wejście LDO2+LDO4 | z IPSOUT |
| 14 | VIN3 | wejście DC/DC3 | z IPSOUT |
| 15 | LX3 | węzeł przełączający DC/DC3 | dławik **2.2µH** (cel >2.5V) |
| 16 | PGND3 | masa mocy DC/DC3 | GND |
| 17 | DCDC3 | wyjście/FB DC/DC3, ustawiane **I2C REG27H** | **3.3V/1.2A → V3S VCC-IO** (+VCC-USB/VCC-MCSI/VCC-PE); kondensator ≥10µF X7R |
| 18 | GPIO1 | GPIO/ADC (zakres rozszerzony 0.7-2.7475V w trybie ADC) | wolne — zakres rozszerzony słabo pasuje do szerokiego dzielnika 8.5-60V (zob. sekcja 6), zostawić jako zwykłe GPIO |
| 19 | GPIO0 | GPIO/ADC (zakres domyślny 0-2.0475V) | **ADC pomiaru napięcia wejściowego 8.5-60V** — zob. sekcja 6 |
| 20 | EXTEN | wyjście, zał. zewn. zasilania pomocniczego (REG12H bit0) | **NC** (nieużywane) |
| 21 | APS | węzeł sensu zasilania systemowego | **zewrzeć z IPSOUT** (0Ω) |
| 22 | AGND | masa analogowa | masa analogowa/cicha |
| 23 | BIAS | referencja prądowa | **rezystor precyzyjny 200kΩ 1% do AGND** (wprost z datasheet) |
| 24 | VREF | wewnętrzna referencja napięcia | **kondensator 1µF do AGND** |
| 25 | PWROK | wyjście power-good | zob. sekcja 7 (reset V3S) |
| 26 | VINT | wewnętrzne zasilanie logiki 2.5V (wyjście) | **kondensator bypass 1µF do AGND** |
| 27 | LDO1SET | strap wyboru domyślnego LDO1 | **→ VINT** (daje LDO1=3.3V; GND dałoby 1.3V) |
| 28 | LDO1 | wyjście LDO1 | **3.3V Always-On → V3S VCC-RTC + GPS V_BCKP**; kondensator 1µF |
| 29 | DC3SET | strap wyboru domyślnego DC/DC3 | **→ APS** (docelowo 3.3V wg tabeli stanów, ale **niepewne** — sekcja "Default configuration instructions" brakuje w datasheet; i tak nadpisać wcześnie w SPL/U-Boot przez I2C REG27H) |
| 30 | BACKUP | bateria podtrzymania RTC | **LIR2032** (już zdecydowane, sekcja 1.2 dok. nadrzędnego) |
| 31 | VBUS | USB VBUS do PMIC | **NC** (nieużywane, sekcja 1.3) |
| 32/33 | ACIN_1/ACIN_2 | wejście ACIN (2 fizyczne piny) | z wyjścia **TPS54360 (5V)** — zob. sekcja 3.1 |
| 34/35 | IPSOUT_1/IPSOUT_2 | główna szyna systemowa (2 fizyczne piny) | zasila: SY8088 VIN, VIN2, VIN3, LDO24IN, LDO3IN, VIN1 (ładowarka), APS |
| 36 | CHGLED | LED statusu ładowania (open-drain) | opcjonalny wskaźnik LED + rezystor do 3.3V |
| 37 | TS | sens temperatury baterii (NTC) | **zewrzeć do GND** — pakiet LiPo z wbudowanym PCM, brak NTC; AXP209 **automatycznie wyłącza** monitorowanie temperatury przy TS=GND (potwierdzone wprost w datasheet); dodatkowo można wyłączyć czujnik programowo REG84H[1:0]=00 |
| 38/39 | BAT_1/BAT_2 | ogniwo LiPo (2 fizyczne piny) | złącze **SM02B-SRSS-TB** (sekcja 1.1) |
| 40 | LDO3IN | wejście LDO3 | z IPSOUT |
| 41 | LDO3 | wyjście LDO3 | propozycja: **GPS 3.3V**; kondensator 4.7µF |
| 42 | BATSENSE | Kelvin-sense prądu ładowania (strona BAT) | przy złączu BAT, przez rezystor sense **0.03Ω**; kondensator 10µF do GND |
| 43 | CHSENSE | Kelvin-sense prądu ładowania (strona ładowarki/LX1) | druga strona rezystora 0.03Ω; kondensator 10µF do GND |
| 44 | VIN1 | wejście ładowarki (DC/DC1) | z **IPSOUT** (nie z BAT); kondensator 10µF |
| 45 | LX1 | węzeł przełączający ładowarki (DC/DC1) | dławik **4.7µH** do węzła CHSENSE→BAT |
| 46 | PGND1 | masa mocy ładowarki | GND |
| 47 | PWRON | przycisk zasilania (PEK) | **wewnętrzny pull-up 100kΩ do APS — nie trzeba zewnętrznego pull-upa**; zalecany zewn. obwód: przycisk chwilowy do GND + rezystor szeregowy **1kΩ** + kondensator filtrujący **100pF** do GND; domyślne czasy: start 3s, long-press 1.5s, shutdown 6s, opóźnienie PWROK 64ms (REG36H=5DH) |
| 48 | IRQ_/WAKEUP | przerwanie (open-drain) | pull-up **51kΩ do 3.3V** (wprost z datasheet — nie 10k, jak wstępnie szacowano); → **V3S EINT: PB5** (zgodnie z `V3S_PINOUT_ROZPISKA.md`) |
| 49 | EP | pad eksponowany | masa (GND) |

---

## 5. Połączenia AXP209 ↔ V3S — podsumowanie

| Sygnał | AXP209 | V3S | Uwaga |
|---|---|---|---|
| I2C SDA | pin 1 | PE22 (TWI1_SDA) | wspólna magistrala z TSC2007, pull-up 2.2kΩ |
| I2C SCK | pin 2 | PE21 (TWI1_SCK) | jw. |
| IRQ (PEK/zdarzenia) | pin 48 | PB5 (PB_EINT5) | pull-up 51kΩ; multipleksuje PEK short/long press, insert/remove ACIN itd. |
| Przycisk zasilania | pin 47 (PWRON) | — (obsłużone sprzętowo w AXP209) | `axp20x-pek` w mainline, generuje `KEY_POWER` |
| Reset | pin 25 (PWROK) | pin 99 (RESET) | **rozważane, nie zdecydowane — zob. sekcja 7** |
| ADC napięcia wejściowego | pin 19 (GPIO0) | — (odczyt przez I2C, nie bezpośrednie podłączenie do V3S) | dzielnik 8.5-60V→ADC, zob. sekcja 6 |

---

## 6. Pomiar napięcia wejściowego 8.5-60V przez GPIO0 ADC

Z datasheetu (potwierdzone): GPIO ADC to **12-bit, 0.5mV/LSB**; zakres wybierany rejestrem
**REG85H** — bit=0 (domyślnie): **0-2.0475V**; bit=1: **0.7-2.7475V**. Włączenie ADC: **REG83H**
(bity GPIO0/GPIO1 ADC enable — **nie REG82H**, jak wstępnie zakładano w dok. nadrzędnym), oraz
funkcja pinu musi być ustawiona na ADC osobno (**REG90H[2:0]=100** dla GPIO0).

**Rekomendacja (propozycja, do weryfikacji przy layoucie)**: użyć **GPIO0 w zakresie domyślnym
(0-2.0475V)** — zakres rozszerzony (0.7-2.7475V) źle pasuje do tak szerokiego zakresu wejściowego,
bo przy niskim końcu (8.5V) po przeskalowaniu spadalibyśmy poniżej progu 0.7V tego trybu.

Proponowany dzielnik: **R_top = 330kΩ** (od węzła pomiarowego 8.5-60V), **R_bottom = 10kΩ** (do
GND, równolegle z wejściem GPIO0) → współczynnik ≈ 1:34 (10/340):

| V_in | V_ADC (obliczone) | Margines do 2.0475V |
|---|---|---|
| 8.5 V (min) | 0.25 V | — (496 kodów z 4096, dobra rozdzielczość) |
| 24 V (nominalne, sekcja 2 dok. nadrzędnego) | 0.71 V | — |
| 60 V (max wg specyfikacji) | 1.77 V | ~13% zapasu |

To **propozycja projektowa**, nie wartość z datasheetu — do potwierdzenia: (a) rzeczywisty
absolutny limit napięcia na pinie GPIO (nie tylko "zakres ADC") przy transientach powyżej 60V, (b)
czy warto dodać TVS/ogranicznik na węźle dzielnika pod kątem tych samych transientów, o których
mowa w sekcji 2 dok. nadrzędnego (load-dump, do 40V+ marginesu).

---

## 7. Reset V3S z sygnału PWROK AXP209 — do rozważenia

Z datasheetu (potwierdzone, §9.1): *"PWROK w AXP209 może być użyty jako sygnał resetu systemu.
Podczas startu AXP209, PWROK wyprowadza stan niski, który następnie jest podciągany wysoko i
resetuje system po osiągnięciu regulacji przez wszystkie napięcia wyjściowe. W normalnej pracy
AXP209 stale monitoruje napięcie i obciążenie — przy przeciążeniu lub podnapięciu PWROK natychmiast
wraca do stanu niskiego, resetując system i zapobiegając utracie danych."* Opóźnienie po
ustabilizowaniu napięć: **64ms domyślnie** (REG36H bit2, potwierdzone).

**Realny precedens**: Pine64 Clusterboard (AXP803 + Allwinner A64, ta sama rodzina PMIC i ten sam
producent SoC) dokumentuje dokładnie tę technikę: *"PWROK jest podpięty do AP-RESET# na SoC A64."*
To potwierdza, że pomysł jest sensowny i praktykowany — **ale ten sam dokument opisuje też realny
problem**: sprzężenie zwrotne (back-EMF) z sieci resetu zakłócało własne sekwencjonowanie PMIC,
wymagając diody Schottky do izolacji.

**Kluczowe zastrzeżenie specyficzne dla tego projektu**: PWROK monitoruje wyłącznie **własne**
wyjścia AXP209 (DC/DC2, DC/DC3, LDO1-4) — **nie** monitoruje szyny DRAM (1.8V), która w tym
projekcie pochodzi z **zewnętrznej** przetwornicy SY8088 (sekcja 3.3), całkowicie poza kontrolą
AXP209. Podpięcie PWROK wprost do RESET V3S **nie gwarantuje**, że pamięć DDR2 jest już stabilna,
gdy reset się zwalnia.

Łagodząca okoliczność znaleziona przy śledzeniu `dcdc.kicad_sch`: SY8088 EN jest podciągnięty
(R31=100k) z sieci `+3V0`, czyli **z LDO2 AXP209** — więc regulator DRAM zaczyna się załączać
mniej więcej w tym samym oknie czasowym co własne szyny AXP209, nie zupełnie niezależnie. To
zmniejsza, ale nie eliminuje ryzyko (DDR2 ma swój własny czas narastania po załączeniu EN, a
64ms to niewiele czasu na pewność stabilizacji dodatkowego, zewnętrznego stopnia).

**Dwie opcje do rozważenia:**

1. **(Rekomendacja, bezpieczniejsza)** PWROK → wolny pin EINT/GPIO V3S (np. jedno z pinów
   `PB6/PB7`, rezerwa EINT z `V3S_PINOUT_ROZPISKA.md`) jako **przerwanie "power fault"**, nie
   twardy reset. Firmware reaguje programowo (bezpieczne wyłączenie/zapis stanu) zamiast
   nieskontrolowanego resetu sprzętowego w trakcie np. zapisu do eMMC. RESET V3S zostaje na
   niezależnym obwodzie RC (10nF + pull-up, już ustalone w `V3S_PINOUT_ROZPISKA.md`, pkt. 99).
2. **(Alternatywa, jeśli zależy na sprzętowym auto-reset przy zaniku zasilania)** PWROK → RESET
   V3S bezpośrednio (przez prosty bufor/diodę), *pod warunkiem* zweryfikowania empirycznie na
   prototypie, że 64ms + czas narastania SY8088 wystarcza, zanim V3S zacznie inicjalizować DDR2;
   rozważyć diodę izolującą (wzorem Pine64 Clusterboard) między siecią resetu a PWROK, jeśli
   sprzężenie zwrotne okaże się problemem w bring-up.

Nie podjęto tu ostatecznej decyzji — zgodnie z prośbą, to "rozważenie", z rekomendacją opcji 1
jako bezpieczniejszej domyślnej.

---

## 8. Otwarte pytania / do potwierdzenia

- **Dokładna wartość rezystora DC3SET** dającego pewne 3.3V na starcie (przed przejęciem kontroli
  przez I2C) — sekcja datasheet "Default configuration instructions" jest przywoływana, ale
  nieobecna w dostępnym PDF. Nie blokuje projektu (firmware i tak ustawi REG27H wcześnie w
  SPL/U-Boot), ale warto zweryfikować bezpośrednio z X-Powers/FAE przy BOM.
- **Adres rejestru LDO2 (REG28H?)** — użyty tu z pamięci wzorem sąsiednich rejestrów DCDC2/DCDC3,
  do potwierdzenia bezpośrednio w datasheet przy pisaniu kodu inicjalizacji.
- **Absolutny limit napięcia na pinie GPIO0** przy transientach powyżej 60V (nie tylko zakres ADC)
  — do sprawdzenia przed finalizacją dzielnika z sekcji 6.
- **PWROK: push-pull czy open-drain** — datasheet nie precyzuje wprost (wywnioskowane jako
  push-pull z braku adnotacji "open drain", jaką ma np. CHGLED/GPIO3) — istotne przy projektowaniu
  ewentualnego łączenia z siecią RESET (opcja 2 z sekcji 7).

---

## 9. Przegląd szkicu PMIC z 2026-07-25 — lista do domknięcia

Przegląd zrzutu ekranu roboczego szkicu arkusza "PMIC" (U2/AXP209) — **ten szkic w chwili
przeglądu nie odpowiada jeszcze zawartości `pcb/cpu_pwr_wip.kicad_sch`** (plik nie zawiera tego
okablowania), więc poniższe traktować jako listę do przeniesienia/domknięcia przy realnym
rysowaniu w KiCad, nie jako opis stanu repo.

**Kompletność**: wszystkie 48 pinów sygnałowych + EP (pad, 9× narysowane) obecne — nic nie
brakuje.

**Zgodne z resztą tego dokumentu** (potwierdzone na szkicu):
- Kondensatory LDO1-4: 1µF/4.7µF/4.7µF/4.7µF — dokładnie jak w sekcji 2/4.
- VREF: 1µF — zgodne z sekcją 4 (pin 24).
- BIAS: rezystor 200kΩ 1% (R2) — dokładnie zgodne z sekcją 4 (pin 23).
- BATSENSE/CHSENSE: rezystor sense 0.03Ω (R13) między węzłem BAT a LX1/ładowarką — poprawna
  topologia Kelvin-sense z sekcji 4 (piny 42/43).
- PWROK poprowadzone w stronę sygnału "reset" (przez R12=47k) — realizacja w duchu opcji 2 z
  sekcji 7 (PWROK→RESET bezpośrednio); pamiętać o zastrzeżeniu stamtąd (PWROK nie monitoruje
  szyny DRAM z SY8088).

**Do poprawy / potwierdzenia przed przeniesieniem do KiCad (wg ważności):**

1. **GPIO0/GPIO1 oznaczone jako NC** — funkcja ADC pomiaru napięcia wejściowego 8.5-60V (sekcja 6)
   jeszcze niepodpięta; zdjąć NC z GPIO0 i dociągnąć proponowany dzielnik 330k/10k.
2. **N_VBUSEN wygląda na współdzielenie sieci z AGND/PGND/EP** (czyli GND) — sprzeczne z
   zaleceniem z sekcji 4 (pin 6): musi być **HIGH** (do VINT/3.3V), bo GND = "wybierz VBUS", a
   VBUS ma być całkowicie nieużywane (sekcja 1.3 dok. nadrzędnego). Priorytet: sprawdzić najpierw.
3. **DC3SET (pin 29) wygląda na niepodłączony** — podciągnąć do APS (dla domyślnego 3.3V) albo
   GND, nie zostawiać w powietrzu nawet jeśli firmware nadpisze przez I2C.
4. **Brak widocznych pull-upów I2C (2.2kΩ SDA/SCK) i pull-upu IRQ (51kΩ)** na tym arkuszu —
   potwierdzić, że istnieją gdzieś w projekcie (np. przy V3S/TSC2007), albo dodać.
5. **VBUS (pin 31) ma etykietę sieci + kondensator 4.7µF zamiast NC** — potwierdzić, czy celowe
   (np. złącze testowe), czy zostawić całkiem odłączone zgodnie z sekcją 1.3 dok. nadrzędnego.
6. **BACKUP (pin 30): widoczny tylko C6=100µF** — potwierdzić, że złącze LIR2032 (sekcja 1.2 dok.
   nadrzędnego) jest podłączone do tej samej sieci gdzieś na arkuszu.
7. **LDO1SET wygląda na zwarte z VINT** (zgodnie z zaleceniem z sekcji 4, pin 27) — potwierdzić
   elektrycznie, nie tylko z układu graficznego.
8. **Wartości L1/L2/L3** (DCDC3/DCDC2/ładowarka) nieczytelne na zrzucie — potwierdzić
   odpowiednio 2.2µH / 4.7µH / 4.7µH (sekcja 4, piny 15/8/45).

Żadna z powyższych pozycji nie wymaga zmiany architektury — to lista konkretnych połączeń do
domknięcia, nie przeprojektowania.

---

## 10. Realny stan `pcb/cpu_pwr.kicad_sch` (2026-07-25) — po dokładnym śledzeniu przewodów

W odróżnieniu od sekcji 9 (przegląd zrzutu ekranu), to jest wynik **dokładnego prześledzenia
realnych `(wire ...)`/`(junction ...)` w faktycznym pliku** `pcb/cpu_pwr.kicad_sch` (symbol
`Allwinner:AXP209`), nie odczytu wizualnego. Zastępuje ustalenia sekcji 9 tam, gdzie się różnią.

**Potwierdzone jako poprawne (wire-trace):**
- DC3SET(29) → APS(21) — zgodnie z zaleceniem.
- LDO1SET(27) → VINT(26), wspólny węzeł z kondensatorem bypass C82=1µF — zgodnie z zaleceniem.
- VBUS(31) → jawne NC — zgodnie z decyzją (sekcja 1.3 dok. nadrzędnego).
- PWROK(25) → węzeł również eksportowany jako `global_label "reset"`, przez R12=47k → sieć "VDD"
  — realizacja opcji 2 z sekcji 7 (PWROK jako źródło resetu); pamiętać o zastrzeżeniu stamtąd.
- Masa: AGND(22)/PGND1-3(46,9,16)/EP(GND$1-9) wszystkie w jednej wspólnej sieci GND (51 członków
  razem z kondensatorami) — nie gwiazda, jedna płaszczyzna.
- Dławiki: L8 (DCDC2/LX2) = 4.7µH ✓, L10 (ładowarka/LX1) = 4.7µH ✓.
- N_VBUSEN(6) → sieć **IPSOUT** (nie GND) — technicznie spełnia wymóg "nie GND/nie wybieraj VBUS",
  choć inaczej niż sugerowane w sekcji 4 (VINT/3.3V); to częsty, akceptowalny wzorzec w
  referencyjnych projektach AXP209 — do świadomego zaakceptowania, nie do zmiany na siłę.

**⚠️ Realne braki — piny fizycznie niepodłączone (część nawet bez flagi no-connect):**

1. **SDA(1) i SCK(2) — zero przewodów.** Magistrala I2C w ogóle nie wychodzi z tego arkusza: brak
   pull-upów 2.2kΩ i brak jakiegokolwiek połączenia dalej (np. do TWI1 V3S). To odcina cały PMIC od
   hosta programowo.
2. **IRQ/WAKEUP(48) — zero przewodów.** Brak pull-upu 51kΩ.
3. **GPIO0(19) — zero przewodów, nawet bez NC** (gorzej niż zwykłe "nieużywane"). Dzielnik ADC do
   pomiaru napięcia wejściowego 8.5-60V (sekcja 6) nie istnieje w tym pliku.
4. **BACKUP(30) — zero przewodów.** Brak złącza LIR2032 i brak kondensatora — obwód podtrzymania
   RTC (sekcja 1.2 dok. nadrzędnego) nieobecny.
5. **PWRON(47) i N_OE(4) — zero przewodów, bez NC.** PWRON jest krytyczne: bez podłączenia do
   przycisku (choćby przez wewnętrzny pull-up 100k do APS + zewnętrzny przycisk do GND) nie da się
   włączyć układu. CHGLED(36) też pływające, ale to tylko opcjonalny wskaźnik LED, niższy priorytet.

**Do potwierdzenia (nie błąd, wymaga decyzji):**

- **L9 (DCDC3/LX3) = 4.7µH**, a sekcja 4 zalecała ~2.2µH (próg >2.5V wg datasheet) — do
  zweryfikowania, czy 4.7µH tu też działa poprawnie, czy warto zmienić na 2.2µH.
- **R41=10kΩ między TS(37) a GND** zamiast bezpośredniego zwarcia — sekcja 4/8 zalecały **dosłowne
  zwarcie TS do GND** (0Ω) dla wyłączenia detekcji NTC (pack ma wbudowane PCM). Rezystor 10k może
  zostawić niezerowe napięcie z wewnętrznego źródła prądowego TS i nie wyłączyć wykrywania tak, jak
  zakładano — sprawdzić w datasheet, czy próg tolerancji na to pozwala, albo zamienić na zwarcie.
- **D6 (1N5819WS)** w układzie bocznikującym do masy (K→BATT, A→GND), nie szeregowym — potwierdzić,
  że to celowa ochrona przeciwprzepięciowa/odwrotnej polaryzacji na złączu baterii, nie pomyłka.
- **ACIN@1/ACIN@2 mają tylko C17=10µF**, bez widocznego dalszego połączenia — upewnić się, że
  łączy się to międzyarkuszowo z wyjściem TPS54360 (sekcja 3.1), a nie że ścieżka ACIN jest
  faktycznie martwa.
- **Nazewnictwo sieci "+3V3" vs "+3.3V"** — dwa różne symbole/nazwy dla DCDC3 (+3V3) i LDO4
  (+3.3V); prawdopodobnie zamierzone jako dwie osobne szyny 3.3V, ale warto ujednolicić nazwy dla
  czytelności i uniknięcia pomyłki przy podłączaniu czegoś do "złej" szyny 3.3V w przyszłości.
- Kondensatory 1nF (C9 na "+3V3", C10 na "+1V25") obok kondensatorów 10µF na tych samych szynach —
  prawdopodobnie kondensatory HF, ale warto sprawdzić, czy to nie miały być 1µF (literówka).

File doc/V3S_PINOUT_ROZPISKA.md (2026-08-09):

# V3S — pełna rozpiska 128 pinów (LQFP128) i gałęzie zasilania

Dokument uzupełniający do [`TERMINAL_RECZNY_DECYZJE_PROJEKTOWE.md`](TERMINAL_RECZNY_DECYZJE_PROJEKTOWE.md) —
tam są decyzje koncepcyjne per-blok (AXP209, CAN, LCD, itd.), tu jest **pełna, płaska rozpiska
wszystkich 128 ponumerowanych pinów** chipu Allwinner V3S w obudowie LQFP128, pin po pinie, z
gałęzią zasilania i przydziałem funkcji w tym konkretnym projekcie.

Zob. też [`AXP209_PINOUT_ROZPISKA.md`](AXP209_PINOUT_ROZPISKA.md) — analogiczna rozpiska PMIC
AXP209 (drzewo DC/DC1-3 + LDO1-4, realne wartości L/C trzech zewnętrznych przetwornic z
`pcb/dcdc.kicad_sch`, połączenia AXP209↔V3S). Sekcja 2 poniżej (gałęzie zasilania) jest od
2026-07-24 zaktualizowana o **potwierdzone** tam mapowanie AXP209→V3S (wcześniej "do
potwierdzenia"). Od 2026-07-25 zob. też
[`STM32_AUDIO_BUTTONS_ROZPISKA.md`](STM32_AUDIO_BUTTONS_ROZPISKA.md) — kontroler audio/
przycisków headsetu dodany na TWI1 + PB6 (sekcja 11 dok. nadrzędnego), zmienił przydział pinów
45/46 (Port B) oraz status pinów audio (113-125) niżej.

Stan na 2026-07-25 (piny 45/46/113-125 zaktualizowane o dodanie audio+STM32; reszta z
2026-07-24).

## Źródła i metoda

- **Numery pinów, pełne nazwy (z wszystkimi funkcjami alternatywnymi) i typ elektryczny** —
  wyciągnięte programowo z `pcb/local_lib/V3S_AXP209.kicad_sym` (symbol `V3S_1_0`). To ta sama
  transkrypcja pinów krzemu, którą `TERMINAL_RECZNY_DECYZJE_PROJEKTOWE.md` już traktuje jako
  źródło referencyjne. Zweryfikowano: dokładnie **128 ponumerowanych pinów (1-128)**, bez dziur,
  plus 9 dodatkowych punktów `EGND` (pad termiczny/masowy pod spodem obudowy — zob. niżej).
  Etykieta na samym symbolu: **`V3S-eLQFP128`**.
- **Napięcia gałęzi zasilania, mapowanie port→domena I/O, liczba kanałów LRADC, pakiet, kwarce** —
  research w oparciu o oficjalny **Allwinner V3s Datasheet V1.0** (rozdz. 3 Pin Characteristics /
  GPIO Multiplex Functions, rozdz. 9 Electrical Characteristics — Tabele 9-1 do 9-5), skrzyżowany
  z trzema niezależnymi, publicznie dostępnymi projektami referencyjnymi wykorzystującymi ten sam
  chip: oficjalny **Allwinner V3S_STD_CDR** (ten sam plik co
  `doc/V3S_CDR_STD_V1_0_20150514.pdf` w tym repo), **LicheePi Zero** (obecna płyta deweloperska
  tego projektu) i **FunKey S** (już przywoływany w `TERMINAL_RECZNY_DECYZJE_PROJEKTOWE.md` jako
  punkt odniesienia dla SY8088). Numery pinów z tego researchu **zgadzają się co do jednego** z
  numeracją wyciągniętą lokalnie z `V3S_AXP209.kicad_sym` (sprawdzone krzyżowo dla VCC-IO0-3,
  VCC-PE0/1, RESET, LRADC0) — traktuję to jako silne potwierdzenie spójności obu źródeł.
- **Przydział funkcji w tym projekcie** — z decyzji już podjętych w
  `TERMINAL_RECZNY_DECYZJE_PROJEKTOWE.md` (sekcje 1-10 + tabela alokacji zasobów + sekcja
  EINT/I2C).
- Jak w dokumencie nadrzędnym: pozycje niepewne oznaczone **(do potwierdzenia)** — nie zgaduję
  liczb, których nie mogłem zweryfikować z pierwotnego źródła.

---

## 1. Obudowa

**V3S-eLQFP128** — LQFP 128-pin, 14×14 mm, rozstaw 0.4 mm, z **eksponowanym paddem
termicznym/masowym** pod spodem (stąd przedrostek "e" w eLQFP). W datasheecie pad ten nazywa się
**EPAD**; w lokalnym symbolu KiCad rozbity jest na 9 osobnych punktów `GND$1`…`GND$9`, wszystkie
nazwane `EGND`, prawdopodobnie żeby ułatwić rysowanie siatki przelotek (via stitching) pod
paddem — dokładnie ta sama konwencja co w symbolu AXP209 w tym samym pliku (`EP`, też 9 punktów,
tam faktyczny exposed pad QFN-48). **Pad nie ma osobnego numeru w numeracji 1-128** — to dodatkowy,
129. punkt lutowniczy, elektrycznie = GND. Brak w datasheecie/design guide sztywno zalecanej
liczby przelotek pod paddem — standardowa praktyka dla exposed-pad QFP (siatka drobnych via,
np. 0.2-0.3 mm, połączona z wewnętrzną płaszczyzną masy).

---

## 2. Gałęzie zasilania — tabela zbiorcza

| Gałąź | Napięcie (typ.) | Zakres wg datasheet | Co zasila | AXP209 / źródło w tym projekcie | Pewność |
|---|---|---|---|---|---|
| **VDD-CPU** (VDD-CPU0-7, 8 pinów) | 1.2 V (realne płyty: 1.2-1.25 V) | Typ 1.2V, min/max niepodane wprost w datasheet (Min/Max = "TBD") | rdzeń CPU (Cortex-A7) | **AXP209 DCDC2, 1.25V/1.6A — potwierdzone**, zob. [`AXP209_PINOUT_ROZPISKA.md`](AXP209_PINOUT_ROZPISKA.md) §2 | Potwierdzone (3 niezależne referencje: Allwinner CDR, LicheePi Zero, FunKey S) |
| **VDD-SYS** (VDD-SYS0-5, 6 pinów) | 1.2 V | jw. | logika systemowa/peryferia | **ta sama fizyczna szyna co VDD-CPU** — **AXP209 DCDC2** wspólnie z VDD-CPU — **potwierdzone** | Potwierdzone |
| **VCC-IO** (VCC-IO0-3, 4 piny) | 3.3 V | 1.7 V min, 1.8-3.3 V typ (zakres aplikacyjny), 3.6 V max | Port B, C, F, G (**jedna wspólna domena**, nie 4 niezależne) | **AXP209 DCDC3, 3.3V/1.2A — potwierdzone**; wymagane 3.3V dla bootowania z SD/eMMC na etapie BROM | Potwierdzone |
| **VCC-DRAM** (VCC-DRAM0-11, 12 pinów) | **1.8 V** | 1.7/1.8/1.9 V, abs. max 1.98V | zintegrowana pamięć DDR2 512Mbit (SiP wewnątrz V3S) | **już zdecydowane**: SY8088AAC, sekcja 3 dok. nadrzędnego | Potwierdzone — DDR2 1.8V to jedyny wspierany typ pamięci (zintegrowana w pakiecie, nie do wyboru) |
| **VCC-PLL** | 3.0 V | 2.7/3.0/3.3 V | analogowe zasilanie PLL | dzielone z AVCC (jedna LDO) — **AXP209 LDO2, 3.0V/200mA — potwierdzone** | Potwierdzone |
| **VCC-PE0/VCC-PE1** (2 piny) | 3.3 V (aplikacyjnie) | 1.7-3.6V abs., 1.8-3.3V typ — **identyczny zakres jak VCC-IO, ale osobna domena krzemowa** | Port E (LCD RGB / CSI kamera, multipleksowane) | w tym projekcie **bez kamery CSI** → można spiąć z VCC-IO na wspólne 3.3V (tak jak LicheePi Zero) — **(do potwierdzenia przy layoucie)** | VCC-PE jako osobna, niezależnie zasilalna domena: potwierdzone; konkretna wartość 3.3V dla tego projektu: rekomendacja, nie z datasheetu |
| **VCC-MCSI** | 3.3 V | 3.0/3.3/3.6 V | zasilanie różnicowych pinów MIPI-CSI (kamera) | **nieużywane w tym projekcie** (brak kamery, sekcja 4 dok. nadrzędnego) — pin można zostawić NC lub podłączyć do 3.3V wg dobrej praktyki referencyjnej | Potwierdzone (wartość); nieużywane (zastosowanie) |
| **VCC-USB** | 3.3 V | 3.0/3.3/3.45 V | zasilanie PHY USB OTG | wymagane nawet przy USB "device-only" (sekcja 9) — PHY potrzebuje zasilania niezależnie od tego, czy port dostarcza VBUS na zewnątrz | Potwierdzone |
| **VCC-RTC** | 3.3 V | 3.0/3.3/3.6 V | zewnętrzny pin zasilania domeny RTC | **AXP209 LDO1, 3.3V Always-On — potwierdzone** (backup z LIR2032, sekcja 1.2 dok. nadrzędnego; LDO1SET strap → VINT daje LDO1=3.3V) | Potwierdzone |
| **AVCC / AGND** | 3.0 V / 0V (masa analog.) | 2.8/3.0/3.3 V | zasilanie analogowe ADC/kodeka audio | kodek audio **używany od 2026-07-25** (sekcja 11 dok. nadrzędnego — audio na innym urządzeniu z tej samej płyty), AVCC zasilane wspólnie z VCC-PLL z **AXP209 LDO2 — potwierdzone** | Potwierdzone (wartość) |
| **HPVCCIN / HPVCCBP** | ~3.3 V | brak wprost w Tabeli 9-2 | zasilanie wzmacniacza słuchawkowego / jego bypass | **używane** — słuchawki przez gniazdo TRRS 3.5mm (sekcja 11 dok. nadrzędnego) | Niepewne/"likely" — tylko jedna płyta referencyjna (LicheePi Zero) daje konkretną wartość |
| **VRA1 / VRA2** | **nieznane** | brak w dostępnych źródłach | wewnętrzne referencje LDO kodeka audio (piny wyjściowe, tylko bypass-cap na zewnątrz) | **używane** — zostawić z samym kondensatorem bypass wg referencyjnego layoutu, nie doprowadzać zasilania z zewnątrz | **Nieznane** — świadomie nie zgaduję liczby, żadne sprawdzone źródło jej nie podaje |
| **SVREF0 / SVREF1** | **niepotwierdzone** (przypuszczalnie ~VCC-DRAM/2 ≈ 0.9V, konwencja DDR2) | brak w Tabeli 9-2 | referencja napięcia dla kontrolera/PHY DDR | tylko kondensatory dekupling w projektach referencyjnych, brak widocznego dzielnika z VCC-DRAM — sugeruje, że może być generowane wewnętrznie | **Niepewne** — nie traktować ~0.9V jako potwierdzonej wartości |
| **SZQ** | n/d (to nie szyna zasilania) | — | pin kalibracji ZQ dla DDR — rezystor precyzyjny do masy | **240 Ω 1%** do GND (potwierdzone w oficjalnym reference design Allwinner) | Potwierdzone |
| **EPAD / EGND** (pad termiczny, 9 punktów w symbolu) | 0 V (masa) | — | pad termiczny/masowy pod spodem obudowy | lutować do płaszczyzny GND, siatka przelotek wg dobrej praktyki QFP e-pad | Potwierdzone (obecność padu); liczba przelotek — do ustalenia przy layoucie |

**Uwaga o VDD-CPU/VDD-SYS**: we wszystkich trzech sprawdzonych projektach referencyjnych
(Allwinner CDR, LicheePi Zero, FunKey S) te dwie domeny są **fizycznie tą samą szyną** (jedno
wyjście DCDC ~1.2-1.25V). To ważne dla sekwencjonowania zasilania w Fazie 4 (bring-up) — nie ma
tu dwóch niezależnych rail-i do sekwencjonowania osobno.

**Mapowanie AXP209→V3S — potwierdzone (2026-07-24)**: DCDC2 (1.25V/1.6A) → VDD-CPU/VDD-SYS,
DCDC3 (3.3V/1.2A) → VCC-IO (+VCC-USB/VCC-MCSI/VCC-PE), LDO2 (3.0V/200mA) → AVCC/VCC-PLL, LDO1
(3.3V Always-On) → VCC-RTC. Pełne uzasadnienie, realne wartości dławików/kondensatorów i
połączenia AXP209↔V3S (I2C, IRQ, PWRON, ADC pomiaru napięcia wejściowego) — zob.
[`AXP209_PINOUT_ROZPISKA.md`](AXP209_PINOUT_ROZPISKA.md). DCDC2/DCDC3 max prądy (1.6A/1.2A)
potwierdzone jako wystarczające dla rdzenia V3S przy 1GHz i domeny IO.

---

## 3. Mapowanie portów GPIO → domena zasilania I/O

| Port | Piny | Zasilany z | Uwaga |
|---|---|---|---|
| **Port B** (PB0-PB9) | 39,40,41,42,43,44,45,46,48,49 | VCC-IO (wspólna domena z C/F/G) | UART2 (GPS), EINT×3, PWM0, TWI0 (rezerwa), UART0 |
| **Port C** (PC0-PC3) | 52-55 | VCC-IO (jw.) | SPI0 (alt. SDC2) → MCP2518FD (CAN) |
| **Port E** (PE0-PE24) | 6-11,13-18,22-24,27-28,30-37 | **VCC-PE0/VCC-PE1** (domena osobna od VCC-IO!) | LCD RGB (panel 5"), PE21/PE22 wyjątkowo na TWI1 (patrz niżej) |
| **Port F** (PF0-PF6) | 100-103,105-107 (+100 bez alt-funkcji) | VCC-IO (jw.) | SDC0 (eMMC), JTAG nieużywany, alt. lokalizacja UART0 nieużywana |
| **Port G** (PG0-PG5) | 1-5,128 | VCC-IO (jw.) | SDC1 (microSD) |

Port E ma **własną, elektrycznie osobną domenę zasilania** (VCC-PE0/1, piny 12 i 29) — nie jest to
ta sama szyna co VCC-IO, mimo identycznego dozwolonego zakresu napięć (1.8-3.3V). To zamierzone
przez Allwinner: pozwala zasilić Port E inaczej niż Porty B/C/F/G (np. 1.8V dla kamery CSI przy
3.3V na reszcie do bootowania z SD). **W tym projekcie, bez kamery CSI**, nie ma powodu
różnicować napięć — VCC-PE0/1 można spiąć z tą samą 3.3V co VCC-IO (tak robi LicheePi Zero).

**Uwaga o Ethernet (EPHY)**: badanie zewnętrzne miało wątpliwość, czy V3S (z małym "s") w ogóle ma
zintegrowany PHY Ethernet, bo to zwykle cecha odróżniająca od zwykłego "V3" — **ale to nie dotyczy
tego projektu**: `TERMINAL_RECZNY_DECYZJE_PROJEKTOWE.md` (sekcja 8) opisuje to jako **już
zweryfikowane na rzeczywistym sprzęcie** (DHCP + ping, `firmware/CanSensorHub-v3s/README.md`), a
lokalny symbol `V3S_AXP209.kicad_sym` ma 9 dedykowanych pinów `EPHY-*` (patrz tabela pełna niżej).
Rozstrzygnięte jednoznacznie na korzyść "V3S w tym projekcie ma zintegrowany EPHY" — nie trzeba tego
dalej weryfikować.

---

## 4. Pełna tabela — wszystkie 128 pinów

Legenda typu elektrycznego: **we/wy** = bidirectional, **zas.we** = power_in, **zas.wy** =
power_out, **pas.** = passive/analogowy, **we** = input, **wy** = output, **we↓** = input
inverted (aktywne nisko).

| Pin | Nazwa (funkcje alternatywne) | Typ | Grupa | Gałąź zasilania / domena | Przydział w tym projekcie |
|---|---|---|---|---|---|
| 1 | PG4/SDC1_D2/PG_EINT4 | we/wy | Port G | VCC-IO | SD/microSD — SDC1_D2 (sekcja 6) |
| 2 | PG3/SDC1_D1/PG_EINT3 | we/wy | Port G | VCC-IO | SD/microSD — SDC1_D1 |
| 3 | PG2/SDC1_D0/PG_EINT2 | we/wy | Port G | VCC-IO | SD/microSD — SDC1_D0 |
| 4 | PG1/SDC1_CMD/PG_EINT1 | we/wy | Port G | VCC-IO | SD/microSD — SDC1_CMD |
| 5 | PG0/SDC1_CLK/PG_EINT0 | we/wy | Port G | VCC-IO | SD/microSD — SDC1_CLK |
| 6 | PE24/LCD_D23 | we/wy | Port E / LCD | VCC-PE | LCD RGB — bit D23 (mapowanie na R/G/B do potwierdzenia z datasheetem panelu BL050S061-17) |
| 7 | PE23/LCD_D22 | we/wy | Port E / LCD | VCC-PE | LCD RGB — bit D22 |
| 8 | PE22/CSI_SDA/TWI1_SDA/UART1_RX | we/wy | Port E / I2C | VCC-PE | **TWI1_SDA** → magistrala I2C AXP209+TSC2007+STM32 (decyzja EINT/I2C w dok. nadrzędnym, STM32 dodane sekcja 11); brak alt-funkcji LCD na tym pinie, więc nie koliduje z 24-bit LCD |
| 9 | PE21/CSI_SCK/TWI1_SCK/UART1_TX | we/wy | Port E / I2C | VCC-PE | **TWI1_SCK** → jw. |
| 10 | PE20/CSI_FIELD/CSI_MIPI_MCLK | we/wy | Port E / CSI | VCC-PE | nieużywane (brak kamery CSI) |
| 11 | PE19/CSI_D15/LCD_D21 | we/wy | Port E / LCD | VCC-PE | LCD RGB — bit D21 |
| 12 | VCC-PE0 | zas.we | Zasilanie Port E | **VCC-PE** (3.3V zalecane, patrz sekcja 3) | zasilanie Portu E — spiąć z VCC-IO (brak kamery) |
| 13 | PE18/CSI_D14/LCD_D20 | we/wy | Port E / LCD | VCC-PE | LCD RGB — bit D20 |
| 14 | PE17/CSI_D13/LCD_D19 | we/wy | Port E / LCD | VCC-PE | LCD RGB — bit D19 |
| 15 | PE16/CSI_D12/LCD_D18 | we/wy | Port E / LCD | VCC-PE | LCD RGB — bit D18 |
| 16 | PE15/CSI_D11/LCD_D15 | we/wy | Port E / LCD | VCC-PE | LCD RGB — bit D15 |
| 17 | PE14/CSI_D10/LCD_D14 | we/wy | Port E / LCD | VCC-PE | LCD RGB — bit D14 |
| 18 | PE13/CSI_D9/LCD_D13 | we/wy | Port E / LCD | VCC-PE | LCD RGB — bit D13 |
| 19 | VDD-SYS3 | zas.we | Zasilanie rdzenia | **VDD-SYS** (~1.2V) | logika systemowa |
| 20 | VDD-CPU3 | zas.we | Zasilanie rdzenia | **VDD-CPU** (~1.2V) | rdzeń CPU |
| 21 | VDD-CPU2 | zas.we | Zasilanie rdzenia | **VDD-CPU** | rdzeń CPU |
| 22 | PE12/CSI_D8/LCD_D12 | we/wy | Port E / LCD | VCC-PE | LCD RGB — bit D12 |
| 23 | PE11/CSI_D7/LCD_D11 | we/wy | Port E / LCD | VCC-PE | LCD RGB — bit D11 |
| 24 | PE10/CSI_D6/LCD_D10 | we/wy | Port E / LCD | VCC-PE | LCD RGB — bit D10 |
| 25 | VDD-CPU1 | zas.we | Zasilanie rdzenia | **VDD-CPU** | rdzeń CPU |
| 26 | VDD-CPU0 | zas.we | Zasilanie rdzenia | **VDD-CPU** | rdzeń CPU |
| 27 | PE9/CSI_D5/LCD_D7 | we/wy | Port E / LCD | VCC-PE | LCD RGB — bit D7 |
| 28 | PE8/CSI_D4/LCD_D6 | we/wy | Port E / LCD | VCC-PE | LCD RGB — bit D6 |
| 29 | VCC-PE1 | zas.we | Zasilanie Port E | **VCC-PE** | zasilanie Portu E — jw. (pin 12) |
| 30 | PE7/CSI_D3/LCD_D5 | we/wy | Port E / LCD | VCC-PE | LCD RGB — bit D5 |
| 31 | PE6/CSI_D2/LCD_D4 | we/wy | Port E / LCD | VCC-PE | LCD RGB — bit D4 |
| 32 | PE5/CSI_D1/LCD_D3 | we/wy | Port E / LCD | VCC-PE | LCD RGB — bit D3 |
| 33 | PE4/CSI_D0/LCD_D2 | pas. | Port E / LCD | VCC-PE | LCD RGB — bit D2 (najmłodszy wyprowadzony bit; D0/D1 nie istnieją w tym pakiecie) |
| 34 | PE3/CSI_VSYNC/LCD_VSYNC | we/wy | Port E / LCD | VCC-PE | LCD — VSYNC |
| 35 | PE2/CSI_HSYNC/LCD_HSYNC | we/wy | Port E / LCD | VCC-PE | LCD — HSYNC |
| 36 | PE1/CSI_MCLK/LCD_DE | we/wy | Port E / LCD | VCC-PE | LCD — DE (data enable) |
| 37 | PE0/CSI_PCLK-/LCD_CLK | we/wy | Port E / LCD | VCC-PE | LCD — CLK (pixel clock) |
| 38 | VDD-CPU4 | zas.we | Zasilanie rdzenia | **VDD-CPU** | rdzeń CPU |
| 39 | PB0/UART2_TX/PB_EINT0 | we/wy | Port B / UART2 | VCC-IO | GPS — **UART2_TX** (sekcja 7) |
| 40 | PB1/UART2_RX/PB_EINT1 | we/wy | Port B / UART2 | VCC-IO | GPS — **UART2_RX** |
| 41 | PB2/UART2_RTS/PB_EINT2 | we/wy | Port B / EINT | VCC-IO | **EINT: MCP2518FD INT** (CAN, RTS niepotrzebny dla GPS) |
| 42 | PB3/UART2_CTS/PB_EINT3 | we/wy | Port B / EINT | VCC-IO | **EINT: TSC2007 nPENIRQ** (dotyk, CTS niepotrzebny) |
| 43 | PB4/PWM0/PB_EINT4 | we/wy | Port B / PWM | VCC-IO | **PWM0 → PT4101 EN** (podświetlenie LCD) |
| 44 | PB5/PWM1/PB_EINT5 | we/wy | Port B / EINT | VCC-IO | **EINT: AXP209 IRQ/WAKEUP** (PWM1 nieużywany) |
| 45 | PB6/TWI0_SCK/PB_EINT6 | we/wy | Port B / EINT | VCC-IO | **EINT: STM32 IRQ** (kontroler audio/przycisków headsetu, sekcja 11 dok. nadrzędnego — dodane 2026-07-25); TWI0 nadal nieużywany jako magistrala, pin tylko jako EINT |
| 46 | PB7/TWI0_SDA/PB_EINT7 | we/wy | Port B / rezerwa | VCC-IO | wolny — **ostatnia rezerwa EINT** |
| 47 | VDD-CPU5 | zas.we | Zasilanie rdzenia | **VDD-CPU** | rdzeń CPU |
| 48 | PB8/TWI1_SCK/UART0_TX/PB_EINT8 | we/wy | Port B / UART0 | VCC-IO | **UART0_TX** (debug console, sekcja 10) — mimo nazwy "TWI1_SCK" tutaj, TWI1 fizycznie na PE21/22, nie tu |
| 49 | PB9/TWI1_SDA/UART0_RX/PB_EINT9 | we/wy | Port B / UART0 | VCC-IO | **UART0_RX** — jw. |
| 50 | VCC-IO3 | zas.we | Zasilanie I/O | **VCC-IO** (3.3V) | zasilanie Port B/C/F/G |
| 51 | VDD-CPU6 | zas.we | Zasilanie rdzenia | **VDD-CPU** | rdzeń CPU |
| 52 | PC0/SDC2_CLK/SPI_MISO | we/wy | Port C / SPI | VCC-IO | **SPI_MISO → MCP2518FD** (CAN, sekcja 5) |
| 53 | PC1/SDC2_CMD/SPI_CLK | we/wy | Port C / SPI | VCC-IO | **SPI_CLK → MCP2518FD** |
| 54 | PC2/SDC2_RST/SPI_CS | we/wy | Port C / SPI | VCC-IO | **SPI_CS → MCP2518FD** |
| 55 | PC3/SDC2_D0/SPI_MOSI | we/wy | Port C / SPI | VCC-IO | **SPI_MOSI → MCP2518FD** |
| 56 | VDD-CPU7 | zas.we | Zasilanie rdzenia | **VDD-CPU** | rdzeń CPU |
| 57 | VCC-IO2 | zas.we | Zasilanie I/O | **VCC-IO** | zasilanie Port B/C/F/G |
| 58 | VDD-SYS4 | zas.we | Zasilanie rdzenia | **VDD-SYS** | logika systemowa |
| 59 | VCC-DRAM8 | zas.we | Zasilanie DDR2 | **VCC-DRAM** (1.8V) | pamięć DDR2 zintegrowana (SiP) |
| 60 | VCC-DRAM9 | zas.we | Zasilanie DDR2 | **VCC-DRAM** | jw. |
| 61 | VCC-DRAM10 | zas.we | Zasilanie DDR2 | **VCC-DRAM** | jw. |
| 62 | VCC-DRAM11 | zas.we | Zasilanie DDR2 | **VCC-DRAM** | jw. |
| 63 | SVREF1 | pas. | Referencja DDR | **SVREF** (niepotwierdzone, ~VCC-DRAM/2?) | referencja napięcia DDR |
| 64 | VDD-SYS5 | zas.we | Zasilanie rdzenia | **VDD-SYS** | logika systemowa |
| 65 | VCC-DRAM0 | zas.we | Zasilanie DDR2 | **VCC-DRAM** | pamięć DDR2 |
| 66 | VCC-DRAM1 | zas.we | Zasilanie DDR2 | **VCC-DRAM** | jw. |
| 67 | VCC-DRAM2 | zas.we | Zasilanie DDR2 | **VCC-DRAM** | jw. |
| 68 | VCC-DRAM3 | zas.we | Zasilanie DDR2 | **VCC-DRAM** | jw. |
| 69 | VCC-DRAM4 | zas.we | Zasilanie DDR2 | **VCC-DRAM** | jw. |
| 70 | VCC-DRAM5 | zas.we | Zasilanie DDR2 | **VCC-DRAM** | jw. |
| 71 | SVREF0 | pas. | Referencja DDR | **SVREF** | referencja napięcia DDR |
| 72 | VCC-DRAM6 | zas.we | Zasilanie DDR2 | **VCC-DRAM** | pamięć DDR2 |
| 73 | SZQ | pas. | Kalibracja DDR | n/d (rezystor 240Ω 1% do GND) | kalibracja ZQ DDR — rezystor precyzyjny |
| 74 | X24MOUT | pas. | Oscylator główny | — | kwarc 24.000 MHz (wyjście) |
| 75 | X24MIN | pas. | Oscylator główny | — | kwarc 24.000 MHz (wejście); ±40/50ppm; trzymać ≥25mm od krawędzi płytki wg design guide |
| 76 | VCC-PLL | zas.we | Zasilanie PLL | **VCC-PLL** (3.0V) | zasilanie analogowe PLL |
| 77 | EPHY-LINK-LED | pas. | Ethernet | VCC-EPHY | LED linku Ethernet (sekcja 8) |
| 78 | EPHY-SPD-LED | pas. | Ethernet | VCC-EPHY | LED prędkości Ethernet |
| 79 | VCC-DRAM7 | zas.we | Zasilanie DDR2 | **VCC-DRAM** | pamięć DDR2 |
| 80 | VDD-SYS0 | zas.we | Zasilanie rdzenia | **VDD-SYS** | logika systemowa |
| 81 | MCSI-D0P | we | MIPI CSI | VCC-MCSI | nieużywane (brak kamery) |
| 82 | MCSI-D0N | we | MIPI CSI | VCC-MCSI | nieużywane |
| 83 | MCSI-D1P | we | MIPI CSI | VCC-MCSI | nieużywane |
| 84 | MCSI-D1N | we | MIPI CSI | VCC-MCSI | nieużywane |
| 85 | VCC-MCSI | we *(sic, wg symbolu)* | Zasilanie MIPI | **VCC-MCSI** (3.3V) | nieużywane funkcjonalnie — można NC lub podpiąć do 3.3V wg dobrej praktyki |
| 86 | MCSI-CKP | wy | MIPI CSI | VCC-MCSI | nieużywane |
| 87 | MCSI-CKN | wy | MIPI CSI | VCC-MCSI | nieużywane |
| 88 | EPHY-VDD | pas. | Ethernet | VCC-EPHY (cyfrowe) | zasilanie rdzenia PHY Ethernet |
| 89 | EPHY-RXN | pas. | Ethernet | — | para różnicowa RX− |
| 90 | EPHY-RXP | pas. | Ethernet | — | para różnicowa RX+ |
| 91 | EPHY-TXN | pas. | Ethernet | — | para różnicowa TX− |
| 92 | EPHY-TXP | pas. | Ethernet | — | para różnicowa TX+ |
| 93 | EPHY-VCC | pas. | Ethernet | VCC-EPHY (analogowe) | zasilanie analogowe PHY Ethernet |
| 94 | EPHY-RTX | pas. | Ethernet | — | rezystor bias precyzyjny (kalibracja linii) |
| 95 | X32KOUT | pas. | Oscylator RTC | — | kwarc 32.768 kHz (wyjście) — domena RTC/wake-up |
| 96 | X32KIN | pas. | Oscylator RTC | — | kwarc 32.768 kHz (wejście) |
| 97 | RTC-VIO | pas. | RTC | wewn. bypass RTC_VIO (reg. 0.7-1.4V, domyślnie 1.1V) | pin bypass/filtr wewnętrznej domeny RTC, nie zewnętrzne zasilanie |
| 98 | VCC-RTC | zas.we | Zasilanie RTC | **VCC-RTC** (3.3V) | zasilanie zewn. domeny RTC — **AXP209 LDO1, potwierdzone** (backup, sekcja 1.2) |
| 99 | RESET | we↓ | Reset | VCC-IO (poziom logiczny) | wejście resetu, **aktywne nisko** (potwierdzone typem pinu w symbolu); brak wewn. pull — wymaga zewn. kondensatora 10nF do GND blisko chipu + obwodu resetu/przycisku. **Rozważane (nie zdecydowane) źródło: AXP209 PWROK** — zob. [`AXP209_PINOUT_ROZPISKA.md`](AXP209_PINOUT_ROZPISKA.md) §7 dla analizy za/przeciw (zastrzeżenie: PWROK nie monitoruje zewnętrznej przetwornicy DRAM SY8088) |
| 100 | PF6 | we/wy | Port F | VCC-IO | brak alt-funkcji w tym symbolu (GPIO ogólnego przeznaczenia?) — **(do potwierdzenia w pełnym datasheet)**; nieużywane w tym projekcie |
| 101 | PF5/SDC0_D2/JTAG_CK1 | we/wy | Port F / eMMC | VCC-IO | eMMC — **SDC0_D2** (JTAG nieużywany, sekcja 6) |
| 102 | PF4/SDC0_D3/UART0_RX | we/wy | Port F / eMMC | VCC-IO | eMMC — **SDC0_D3** (alt. lokalizacja UART0 nieużywana — UART0 jest na PB8/9) |
| 103 | PF3/SDC0_CMD/JTAG_DO1 | we/wy | Port F / eMMC | VCC-IO | eMMC — **SDC0_CMD** |
| 104 | VCC-IO0 | zas.we | Zasilanie I/O | **VCC-IO** | zasilanie Port B/C/F/G |
| 105 | PF2/SDC0_CLK/UART0_TX | we/wy | Port F / eMMC | VCC-IO | eMMC — **SDC0_CLK** (alt. UART0 nieużywana) |
| 106 | PF1/SDC0_D0/JTAG_DI1 | we/wy | Port F / eMMC | VCC-IO | eMMC — **SDC0_D0** |
| 107 | PF0/SDC0_D1/JTAG_MS1 | we/wy | Port F / eMMC | VCC-IO | eMMC — **SDC0_D1** |
| 108 | VDD-SYS1 | zas.we | Zasilanie rdzenia | **VDD-SYS** | logika systemowa |
| 109 | VCC-USB | zas.we | Zasilanie USB | **VCC-USB** (3.3V) | zasilanie PHY USB — wymagane nawet w trybie device-only (sekcja 9) |
| 110 | USB-DM | pas. | USB | — | USB OTG D− (FEL/debug gadget) |
| 111 | USB-DP | pas. | USB | — | USB OTG D+ |
| 112 | LRADC0 | pas. | LRADC | — | **klawisze funkcyjne** (sekcja 4.3) — **jedyny kanał LRADC w tym pakiecie (potwierdzone: brak LRADC1 na V3S)**, rozstrzyga otwartą kwestię z dok. nadrzędnego |
| 113 | MICIN1P | pas. | Audio | — | **mikrofon (wejście różnicowe +)** — aktywowane 2026-07-25 (sekcja 11 dok. nadrzędnego: audio na innym urządzeniu z tej samej płyty), przez złącze TRRS 3.5mm |
| 114 | MICIN1N | pas. | Audio | — | **mikrofon (wejście różnicowe −)** |
| 115 | AVCC | zas.we | Zasilanie analog. | **AVCC** (3.0V) | analogowe ADC/kodeka audio — **używane** (LDO2 AXP209, wspólnie z VCC-PLL) |
| 116 | AGND | zas.we *(sic)* | Masa analog. | AGND (0V) | masa analogowa |
| 117 | VRA1 | zas.wy | Audio | wewn. LDO audio (nieznane V) | **używane** — zostawić z kondensatorem bypass wg referencyjnego layoutu, nie doprowadzać zasilania z zewnątrz (pin wewnętrznej referencji, nie zewnętrznego zasilania) |
| 118 | VRA2 | zas.wy | Audio | wewn. LDO audio (nieznane V) | **używane** — jw. |
| 119 | HBIAS | pas. | Audio | — | bias wzmacniacza słuchawkowego — **używane** |
| 120 | HPOUTR | pas. | Audio | — | **wyjście słuchawkowe R** — do gniazda TRRS 3.5mm |
| 121 | HPOUTL | pas. | Audio | — | **wyjście słuchawkowe L** (lub mono) — do gniazda TRRS 3.5mm |
| 122 | HPVCCIN | zas.we | Zasilanie audio | **HPVCCIN** (~3.3V, niepewne) | **używane** — zasilanie wzmacniacza słuchawkowego |
| 123 | HPVCCBP | zas.wy | Audio (bypass) | — | **używane** — pin bypass wzmacniacza słuchawkowego |
| 124 | HPCOMFB | pas. | Audio | — | common-mode feedback wzmacniacza słuchawkowego — **używane** |
| 125 | HPCOM | pas. | Audio | — | common-mode wzmacniacza słuchawkowego — **używane** |
| 126 | VDD-SYS2 | zas.we | Zasilanie rdzenia | **VDD-SYS** | logika systemowa |
| 127 | VCC-IO1 | zas.we | Zasilanie I/O | **VCC-IO** | zasilanie Port B/C/F/G |
| 128 | PG5/SDC1_D3/PG_EINT5 | we/wy | Port G | VCC-IO | SD/microSD — SDC1_D3 |
| GND$1…GND$9 | EGND ×9 (= EPAD w datasheet) | zas.we | Pad termiczny | GND (masa) | pad termiczny/masowy pod obudową — lutować do płaszczyzny GND (siatka przelotek, poza numeracją 1-128) |

---

## 5. Rzeczy jednoznacznie rozstrzygnięte tym researchem (wcześniej otwarte w dok. nadrzędnym)

- **Liczba kanałów LRADC** (otwarte pytanie w sekcji 4.3 dok. nadrzędnego: "ile kanałów LRADC V3S
  faktycznie wyprowadza w tym pakiecie") → **rozstrzygnięte: tylko jeden, LRADC0 (pin 112)**. V3S
  nie ma LRADC1 (w przeciwieństwie do części innych chipów sunxi, np. A10/A20/A31). Budżet
  klawiszy funkcyjnych z sekcji 4.3 nie podwaja się — jedna drabinka rezystorowa, jeden kanał.
- **Polaryzacja pinu RESET** — potwierdzona jako aktywna nisko wprost z typu elektrycznego pinu
  w lokalnym symbolu KiCad (`input inverted`), co jest spójne z ogólną konwencją rodziny sunxi.
- **Obecność zintegrowanego PHY Ethernet na V3S** — potwierdzona (patrz sekcja 3 wyżej) mimo
  ogólnej wątpliwości, że "V3s" (małe "s") czasem bywa mylone z wariantem bez PHY — w tym
  projekcie jest to i tak już zweryfikowane na sprzęcie.

## 6. Rzeczy nadal otwarte (przenieść do Fazy 1/2 dok. nadrzędnego)

- ~~Dokładne mapowanie AXP209 DCDC2/DCDC3/LDO1-4 → gałęzie V3S~~ — **rozstrzygnięte 2026-07-24**,
  zob. sekcja 2 wyżej i [`AXP209_PINOUT_ROZPISKA.md`](AXP209_PINOUT_ROZPISKA.md).
- Napięcie VRA1/VRA2 i SVREF0/1 — nieznalezione w żadnym sprawdzonym źródle; nie blokuje
  schematu (to piny wewnętrznego bypass/referencji, nie zewnętrznego zasilania), ale warto
  zweryfikować bezpośrednio w `doc/V3S_CDR_STD_V1_0_20150514.pdf`, jeśli będzie potrzebna
  dokładna wartość kondensatorów dekuplingowych. **Teraz istotniejsze niż wcześniej** — piny
  audio (113-125, w tym VRA1/VRA2) są od 2026-07-25 rzeczywiście używane (sekcja 11 dok.
  nadrzędnego), nie tylko teoretyczne.
- **Dokładne wartości komponentów aplikacyjnych kodeka audio V3S** (sprzęganie DC na MICIN1P/N,
  dopasowanie HPVCCIN/HPVCCBP) — otwarte, zob. `STM32_AUDIO_BUTTONS_ROZPISKA.md` i sekcja 11.1
  dok. nadrzędnego.
- Funkcja pinu 100 (`PF6`, brak alt-funkcji w lokalnym symbolu) — do sprawdzenia w pełnym
  datasheet, czy ma dodatkowe przeznaczenie w tym pakiecie.
- Dokładna liczba/rozmiar przelotek pod paddem EPAD/EGND — do ustalenia przy layoucie (brak
  twardego wymogu z datasheet).
- Dokładne mapowanie LCD_D2-D23 na kanały R/G/B dla panelu BL050S061-17/T050SWV012T — do
  potwierdzenia z datasheetem konkretnego panelu (czy to RGB666 z pominiętymi D8/D9/D16/D17, czy
  pełne RGB888).
- **Decyzja o RESET z PWROK (pkt. 99)** — rozważone, nie rozstrzygnięte; zob.
  `AXP209_PINOUT_ROZPISKA.md` §7 (rekomendacja: PWROK→EINT rezerwowy zamiast wprost na RESET, ze
  względu na brak monitorowania szyny DRAM SY8088 przez PWROK).

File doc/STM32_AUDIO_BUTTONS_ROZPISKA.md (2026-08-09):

# STM32L432KCU6 — kontroler audio/przycisków headsetu, pełna rozpiska pinów

Dokument uzupełniający do [`TERMINAL_RECZNY_DECYZJE_PROJEKTOWE.md`](TERMINAL_RECZNY_DECYZJE_PROJEKTOWE.md)
(sekcja 11) i [`V3S_PINOUT_ROZPISKA.md`](V3S_PINOUT_ROZPISKA.md) (piny 45/113-125) — pełna
rozpiska 32 pinów **STM32L432KCU6** (UFQFPN32/QFN-32), dodanego 2026-07-25 jako koprocesor I2C
obsługujący interfejs headsetu (przyciski/audio) i dodatkowe GPIO poza zakresem LRADC, w związku
z tym, że ta sama płyta ma posłużyć też do budowy innego urządzenia wymagającego obsługi dźwięku
(słuchawki + mikrofon).

Stan na 2026-07-25, **zaktualizowano 2026-07-29 wg faktycznego schematu** (`stm.kicad_sch` +
`audio.kicad_sch` + `ext_conn.kicad_sch`, zweryfikowane `kicad-happy:kicad`). Koncepcja
przesunęła się od czasu pierwszej wersji tego dokumentu — sekcje 3-4 poniżej opisują teraz **to,
co jest faktycznie narysowane**, nie pierwotny plan. Kluczowe różnice względem wersji z
2026-07-25:

- **Nie ma osobnych linii `BTN_PTT`/`BTN_VOL_UP`/`BTN_VOL_DOWN`.** Zamiast trzech dyskretnych
  przycisków, headset dostaje **dwie linie `DATA+`/`DATA-` w trybie dwufunkcyjnym**: albo GPIO
  (kodowanie 2-bitowe: spoczynek `00`, przyciski `01`/`10`/`11`, część zwiera do masy, część do
  plusa), albo pełny UART, jeśli podłączony akcesorium jest "mądrzejsze" (ma własny mikrokontroler
  po drugiej stronie). Wybór trybu jest w całości po stronie firmware STM32 (konfiguracja
  kierunku/pull na GPIO vs peryferium USART2) — płytka nie narzuca żadnego z góry.
- **Nie ma `JACK_DETECT`.** Ta koncepcja (mechaniczny styk wykrycia wtyku) została porzucona.
  Zamiast tego złącze `J14` ma dodatkowy pin zasilający (`+3.3V` filtrowane przez ferryt+TVS) —
  do zasilenia własnej elektroniki "mądrego" headsetu (spójne z opcją UART wyżej).
- **10 pinów (`PA0`, `PA4-PA9`, `PB0/PB1/PB4`) to teraz ogólny breakout GPIO** wyprowadzony na
  złącze `J15` (JST 12-pin) — do obsługi np. zewnętrznej klawiatury panelowej, ale też
  wykorzystywalny jako UART lub SPI, w zależności od potrzeb finalnego urządzenia. To nie jest
  już "rezerwa" w sensie niewykorzystanych pinów — są aktywnie wyprowadzone na złącze, tylko ich
  funkcja nie jest zdefiniowana na poziomie schematu.
- **Magistrala I2C1 wylądowała na `PB6`/`PB7`** (współdzielona z AXP209+TSC2007), nie na
  `PA9`/`PA10` jak pierwotnie zdecydowano — `PA9`/`PA10` są teraz częścią breakoutu GPIO /
  sterowania wzmacniaczem.
- **Dodano wzmacniacz słuchawkowy `U11` (TI TPA6132A2RTE)** między V3S `HPOUTR`/`HPOUTL` a
  złączem `J14` — sterowany z STM32 (`PA10`=`EN`, `PA11`=`G0`, `PA12`=`G1`, wybór wzmocnienia w
  runtime). To nie było przewidziane w pierwotnej wersji tego dokumentu.
- **`STM32_IRQ` jest na `PB5`, nie `PA8`**, i idzie do V3S **`PB7`**, nie `PB6` (`PB6` jest już
  zajęte przez `PWROK`, patrz `TODO.md`) — `PA8` należy teraz do breakoutu GPIO (`STM.IO8`).

## Źródła i metoda

- **Pełny pinout, typ pinów, funkcje alternatywne, kanały ADC, wymagania zasilania/decoupling,
  zachowanie NRST/BOOT0** — z oficjalnego datasheetu ST **DS11451 Rev 4** ("STM32L432KB/KC —
  Ultra-low-power Arm Cortex-M4 32-bit MCU+FPU"), Figura 5 (pinout UFQFPN32), Tabela 14 (pin
  definitions), Tabela 15 (alternate functions), Figura 9 (power supply scheme), §6.3.15
  (NRST), §3.7 (boot modes) — zweryfikowane bezpośrednio w PDF, nie z pamięci.
- **Przydział konkretnych pinów w tym projekcie** (który GPIO robi co) — decyzja podjęta tu, na
  bazie wolnych/zalecanych pinów z datasheetu (np. I2C1 na PA9/PA10 jako "primary", nie PB6/PB7
  jako "alt.").
- Jak w poprzednich dokumentach: pozycje niepewne oznaczone **(do potwierdzenia)**.

---

## 1. Obudowa i zasilanie

**UFQFPN32** (QFN-32-podobny, 5×5mm, rozstaw 0.5mm). **Tylko 1 domena I/O** (VDDIO1=VDD, brak
VDDIO2 — ten pakiet jest za mały na drugą domenę) — upraszcza zasilanie, wszystkie GPIO na tym
samym poziomie logicznym 3.3V co reszta płyty.

**Zasilanie**: VDD 1.71-3.6V — zasilić z **VCC-IO** (domena 3.3V V3S/AXP209 DCDC3, sekcja 11.2
dok. nadrzędnego), bez dodatkowej LDO. VDDA/VREF+ (pin 5, połączone w jeden pin w tym pakiecie)
— zewrzeć z VDD przez mały ferryt/RC, bo jedyna funkcja analogowa użyta tu to ADC1 (żadnego
DAC/OPAMP), co zgodnie z datasheet kwalifikuje się do prostego zasilenia z VDD.

**Dekupling (wprost z Figury 9 datasheetu)**:
- VDD/VSS (piny 1,17 / 16,32): **2× 100nF** (po jednym przy każdym pinie VDD) + **1× 4.7µF**
  bulk (jeden na cały chip).
- VDDA/VREF+ (pin 5): **10nF + 100nF + 1µF** (role VDDA-decoupling i VREF-filtering łączą się
  na tym samym fizycznym pinie w tym pakiecie).
- Razem: **~6 kondensatorów**, umieszczone jak najbliżej odpowiednich pinów (zalecenie
  datasheetu: najlepiej od spodu płytki, bezpośrednio pod pinem).

**Zegar: brak zewnętrznego kwarca** — ten pakiet **nie ma w ogóle dedykowanych pinów HSE
OSC_IN/OSC_OUT** (HSE możliwe tylko przez zewnętrzny sygnał na PA0/CK_IN, bypass, nie kwarc).
Wewnętrzny **HSI16** (16MHz RC) w pełni wystarcza dla I2C slave + ADC + debounce (żadna z tych
funkcji nie wymaga precyzji krystalicznej) — **zero-crystal design**, mniejszy BOM. PC14/PC15
(OSC32_IN/OUT, do opcjonalnego kwarca RTC 32.768kHz) **nie są potrzebne** — V3S ma już własny
RTC (`TERMINAL_RECZNY_DECYZJE_PROJEKTOWE.md`, pkt. 1.2) — zostają jako zwykłe GPIO w rezerwie
(z zastrzeżeniem: zasilane przez ograniczony prądowo przełącznik wewnętrzny, max 3mA, zalecana
prędkość wyjścia ≤2MHz/30pF — nie używać do sterowania czymś prądożernym).

---

## 2. NRST i BOOT0

- **NRST (pin 4)**: STM32 ma **wewnętrzny stały pull-up** (typ. 40kΩ) — w odróżnieniu od pinu
  RESET V3S (brak pull-up, wymaga zewnętrznego, patrz `V3S_PINOUT_ROZPISKA.md` pkt. 99),
  **STM32 nie wymaga zewnętrznego rezystora**. Zalecany (opcjonalny, dla odporności na zakłócenia)
  kondensator **100nF do GND** blisko pinu — warto dodać, biorąc pod uwagę sąsiedztwo z
  przełączanymi obwodami (CAN, DC/DC) na tej samej płycie.
- **BOOT0 (pin 31, współdzielony z PH3)**: zalecenie — **pull-down 10kΩ do GND** (gwarantuje
  boot z Flash przy domyślnych option bytes, `nSWBOOT0=1` fabrycznie) + **opcjonalna zworka/
  punkt testowy do VDD** równolegle, żeby serwisant mógł wymusić wejście w bootloader systemowy
  (UART/I2C/SPI/USB DFU) do odzyskiwania firmware w polu, bez utraty tej ścieżki na stałe.

---

## 3. Pełna tabela pinów (32) — wg faktycznego schematu (2026-07-29)

Legenda: **I2C1** = magistrala do V3S (TWI1, współdzielona z AXP209+TSC2007+STM32), **STM.IOn**
= ogólny GPIO wyprowadzony na złącze `J15` (JST 12-pin, `ext_conn.kicad_sch`), **audio** = pin
związany z interfejsem headsetu na `J14` (JST 8-pin, `audio.kicad_sch`) lub sterowaniem
wzmacniacza `U11` (TPA6132A2).

| Pin | Nazwa | Funkcje alt. (wybrane) | Sieć w schemacie | Przydział w tym projekcie |
|---|---|---|---|---|
| 1 | VDD | — | `+3.3V` | zasilanie 3.3V |
| 2 | PC14-OSC32_IN | EVENTOUT | *(no-connect)* | jawnie oznaczone no-connect — wolne (brak kwarca LSE — V3S ma własny RTC) |
| 3 | PC15-OSC32_OUT | EVENTOUT | *(no-connect)* | jawnie oznaczone no-connect — wolne |
| 4 | NRST | reset | `nRESET` | reset (wewn. pull-up; `C121` 100nF do GND obecny; też wyprowadzony na `J11` TC2030 SWD) |
| 5 | VDDA/VREF+ | analog supply | dedykowana sieć | zasilanie analogowe z `+3.3V` przez ferryt `FB3` (100R@100MHz) + `C119`(100n)/`C120`(1µF) |
| 6 | PA0/CK_IN | TIM2_CH1, USART2_CTS | `STM.IO3` | **breakout GPIO → J15** (klawiatura zewn. / UART / SPI, do ustalenia w firmware) |
| 7 | PA1 | TIM2_CH2, I2C1_SMBA | `AUDIO_ADC` | analogowy odczyt węzła mic-bias/drabinki na `J14.pin4` (przez `R48` 47k) |
| 8 | PA2 | TIM2_CH3, USART2_TX | `DATA+` | **headset, tryb dwufunkcyjny** — GPIO (bit kodowania przycisków) lub USART2_TX; przez `R49` (100Ω) do `J14.pin6` |
| 9 | PA3 | TIM2_CH4, USART2_RX | `DATA-/GPIO1` | **headset, tryb dwufunkcyjny** — GPIO (bit kodowania przycisków) lub USART2_RX; przez `R50` (100Ω) do `J14.pin7` |
| 10 | PA4 | SPI1_NSS, USART2_CK | `STM.IO4` | **breakout GPIO → J15** |
| 11 | PA5 | TIM2_CH1/ETR, SPI1_SCK | `STM.IO5` | **breakout GPIO → J15** |
| 12 | PA6 | TIM1_BKIN, SPI1_MISO | `STM.IO6` | **breakout GPIO → J15** (JACK_DETECT porzucone — patrz uwaga wyżej) |
| 13 | PA7 | I2C3_SCL, SPI1_MOSI | `STM.IO7` | **breakout GPIO → J15** |
| 14 | PB0 | SPI1_NSS, QUADSPI_BK1_IO1 | `STM.IO0` | **breakout GPIO → J15** |
| 15 | PB1 | USART3_RTS_DE | `STM.IO1` | **breakout GPIO → J15** |
| 16 | VSS | — | `GND` | masa |
| 17 | VDD | — | `+3.3V` | zasilanie 3.3V |
| 18 | PA8 | MCO, TIM1_CH1 | `STM.IO8` | **breakout GPIO → J15** (IRQ do V3S przeniesiony na PB5, patrz niżej) |
| 19 | PA9 | TIM1_CH2, I2C1_SCL (alt.) | `STM.IO9` | **breakout GPIO → J15** (I2C1 wylądowało na PB6/PB7, nie tutaj) |
| 20 | PA10 | TIM1_CH3, I2C1_SDA (alt.) | `EN` | **wzmacniacz `U11` TPA6132A2, pin 13 (EN)** — włącz/wyłącz |
| 21 | PA11 | CAN1_RX, USB_DM | `GPIO_CTRL1` | **wzmacniacz `U11`, pin 6 (G0)** — wybór wzmocnienia, bit 0 |
| 22 | PA12 | CAN1_TX, USB_DP | `G1` | **wzmacniacz `U11`, pin 7 (G1)** — wybór wzmocnienia, bit 1 |
| 23 | PA13 (SWDIO) | SWDIO | `SWDIO` | header programowania/debug (`J11` TC2030) |
| 24 | PA14 (SWCLK) | SWCLK | `SWCLK` | header programowania/debug (`J11` TC2030) |
| 25 | PA15 (JTDI) | JTDI, TIM2_CH1/ETR | *(single-pin, wolny)* | rezerwa GPIO — jedyny pin faktycznie jeszcze niewykorzystany |
| 26 | PB3 (JTDO) | JTDO-TRACESWO, TIM2_CH2 | `SWO` | **trace/SWO** — wyprowadzone na `J11`, nie jest już rezerwą |
| 27 | PB4 (NJTRST) | NJTRST, I2C3_SDA | `STM.IO2` | **breakout GPIO → J15** |
| 28 | PB5 | LPTIM1_IN1, I2C1_SMBA | `IRQ_V3S` | **STM32→V3S IRQ**, idzie do V3S **`U2.pin46` / PB7** (nie PA8/PB6 jak w pierwotnym planie — PB6 zajęte przez `PWROK`) |
| 29 | PB6 | LPTIM1_ETR, I2C1_SCL (alt.) | `APX_SCL` | **I2C1_SCL** → magistrala TWI1 współdzielona z AXP209+TSC2007 (pull-up `R11` 2.2kΩ do `+3V3`, już istniejący) |
| 30 | PB7 | LPTIM1_IN2, I2C1_SDA (alt.) | `APX_SDA` | **I2C1_SDA** → jw. (pull-up `R10` 2.2kΩ) |
| 31 | PH3/BOOT0 | BOOT0 | dedykowana sieć | **pull-down `R43` 10kΩ do GND obecny** — zgodnie z zaleceniem; brak opcjonalnej zworki/testpointu do VDD (nice-to-have, nieobecne) |
| 32 | VSS | — | `GND` | masa |
| 33 | EP/VSS | — | `GND` | pad termiczny/masa (numerowany jako osobny pin w symbolu KiCad) |

**Budżet rezerwy faktyczny**: tylko **`PA15`** jest naprawdę wolny. `PC14`/`PC15` są jawnie
no-connect (celowo, nie "do wykorzystania" bez przeróbki). Wszystkie pozostałe piny opisane
wcześniej jako "rezerwa" (`PA0`, `PA4-PA9`, `PB0/PB1/PB4`) są teraz aktywnie wyprowadzone jako
`STM.IO0`-`STM.IO9` na złącze `J15` — nie są to już piny "na przyszłość" w schemacie, tylko
realny, uzbrojony breakout czekający na decyzję firmware/akcesorium.

---

## 4. Obsługa headsetu — stan wg schematu (2026-07-29)

Fizyczny interfejs headsetu na `J14` (JST PH 8-pin) ma dziś **6 linii sygnałowych + 2×GND**:
`OUTR`/`OUTL` (wyjście wzmacniacza `U11`), mic/ADC (pin 4, przez `R48` 47k do `PA1`), `DATA+`/
`DATA-` (piny 6/7, przez `R49`/`R50` 100Ω do `PA2`/`PA3`), i pin zasilający (pin 8, `+3.3V`
filtrowane `FB6`+TVS `D18` — zasila ewentualną własną elektronikę "mądrego" headsetu, nie jest
to wejście detekcji). Wszystkie 6 linii + zasilanie mają TVS (`STN061050BL40`) na złączu.

### 4.1 Kanał analogowy — `PA1`/`AUDIO_ADC`

Czyta napięcie DC na węźle mic-bias (`J14.pin4`), zasilanym z V3S `HBIAS` (pin119) przez `R53`
(2k) — klasyczny obwód bias dla wkładki elektretowej, z `C136` (470n) jako bypass i `R48` (47k)
jako rezystor szeregowy/antyaliasingowy do wejścia ADC STM32. Może posłużyć do drabinki
rezystorowej (rozróżnianie poziomów napięcia) albo po prostu do monitorowania obecności/poziomu
sygnału na linii MIC — dokładna rola zależy od konkretnego akcesorium i jest do ustalenia w
firmware (progi nieznane z góry, brak jednego standardu CTIA/OMTP).

### 4.2 Kanał cyfrowy dwufunkcyjny — `PA2`/`PA3` (`DATA+`/`DATA-`)

Te dwie linie (przez `R49`/`R50` 100Ω + TVS do `J14.pin6`/`pin7`) obsługują **dwa niezależne
tryby pracy, wybierane w firmware**, nie na sztywno w sprzęcie:

- **Tryb GPIO (headset z przyciskami)**: `PA2`/`PA3` jako cyfrowe wejścia z **wewnętrznym
  pull-STM32** (kierunek pull do ustalenia w firmware — patrz uwaga o pull-up/down niżej).
  Kodowanie 2-bitowe: stan spoczynkowy `00`, przyciski dają `01`/`10`/`11` — część przycisków w
  headsecie zwiera linię do masy, część do plusa (`+3.3V`), w zależności od konkretnego
  akcesorium/konwencji producenta.
- **Tryb UART (headset "mądry")**: `PA2`=`USART2_TX`, `PA3`=`USART2_RX` — dla akcesorium z
  własnym mikrokontrolerem po drugiej stronie kabla. Pin zasilający na `J14.pin8` (patrz wyżej)
  istnieje właśnie po to, żeby zasilić taką elektronikę.
- Płytka **nie rozstrzyga, który tryb jest aktywny** — `R49`/`R50` (100Ω) to tylko
  zabezpieczenie prądowe/ESD-koordynacja z TVS, kompatybilne z obydwoma trybami. Wybór trybu i
  ewentualna autodetekcja to w całości zadanie firmware STM32.

**Uwaga o pull-up/pull-down (do zamknięcia w firmware, nie w sprzęcie):** na płytce **nie ma
rezystorów podciągających** na `DATA+`/`DATA-` — świadomie, bo stały pull-up/pull-down
przeszkadzałby w trybie UART. To oznacza, że **firmware musi jawnie skonfigurować wewnętrzny
pull STM32** (GPIO pull-up lub pull-down, zależnie od konwencji wybranego headsetu) zanim
zacznie odczytywać stan przycisków w trybie GPIO — inaczej piny są elektrycznie pływające
(floating) między resetem a inicjalizacją firmware, co przy dłuższym, nieekranowanym kablu do
headsetu może dawać losowe odczyty/fałszywe zdarzenia w tym krótkim oknie. Do rozważenia:
krótkie opóźnienie/maskowanie zdarzeń przycisków tuż po starcie, dopóki pull nie zostanie
skonfigurowany.

### 4.3 Sterowanie wzmacniaczem — `PA10`/`PA11`/`PA12`

`U11` (TPA6132A2) ma trzy cyfrowe wejścia sterujące z STM32: `EN` (`PA10`, pin13 — włącz/wyłącz
wzmacniacz), `G0`/`G1` (`PA11`/`PA12`, piny 6/7 — wybór wzmocnienia). Są to zwykłe wyjścia
push-pull STM32 — nie ma na nich rezystora podciągającego na płytce, co jest poprawne dla
aktywnie sterowanego wyjścia w normalnej pracy. **Jedyne ryzyko**: domyślny stan GPIO STM32 po
resecie to wejście bez pull (floating) — do czasu inicjalizacji firmware `EN` może być w stanie
nieokreślonym, co teoretycznie mogłoby dać krótki trzask/pop na starcie. Nieobowiązkowe, ale
tanie zabezpieczenie: zewnętrzny pull-down ~100kΩ na `EN` gwarantujący wzmacniacz wyłączony
(wyciszony) do czasu, aż firmware go świadomie włączy — do rozważenia przy kolejnej rewizji
płytki, nie blokuje obecnego etapu.

### 4.4 Breakout GPIO — `J15` / `STM.IO0`-`STM.IO9`

10 pinów (`PA0`, `PA4-PA9`, `PB0/PB1/PB4`) jest wyprowadzonych na złącze `J15` (JST 12-pin, w
`ext_conn.kicad_sch`, razem z filtrowanym zasilaniem `+3.3V` na pinie 1 i wspólną masą na pinie
12). Przeznaczenie: **ogólny interfejs do zewnętrznego modułu** — może to być klawiatura
panelowa (matryca), ale piny nadają się też pod UART lub SPI, w zależności od finalnej
architektury urządzenia. Żadna konkretna funkcja nie jest tu jeszcze przypisana na poziomie
schematu — to świadomie otwarty punkt, nie brak. Ewentualne rezystory podciągające (np. do
skanowania matrycy klawiszy) są sprawą modułu zewnętrznego, nie tej płytki.
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

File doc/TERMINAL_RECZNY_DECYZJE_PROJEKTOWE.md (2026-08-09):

# Terminal ręczny V3S — decyzje projektowe (hardware + firmware)

Dokument referencyjny dla oddzielnej płyty "terminala polowego" (battery-powered field
terminal) opartej o Allwinner V3S + AXP209, odróżnionej od obecnej płyty deweloperskiej
LicheePi Zero (bez PMIC), na której działa `firmware/CanSensorHub-v3s`. Kod aplikacji już
odwołuje się do tego pliku (`core/include/csh/config.h`, `core/include/csh/power_info.h`) —
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

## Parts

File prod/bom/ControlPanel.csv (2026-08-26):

Oznaczenie | Wartość | Footprint | Opis | Liczba
BT1 | MS621FE-FL11E | local_lib:BAT_MS621FE-FL11E | MS621FE-FL11E | 1
C1,C2,C3,C4 | 18p | Capacitor_SMD:C_0402_1005Metric | Unpolarized capacitor | 4
C5,C6 | 2.2u/100V | Capacitor_SMD:C_1206_3216Metric | KGM31HR72A225KU | 2
C7,C12,C16,C17,C20,C25,C26,C27,C34,C36,C51,C57,C62,C64,C65,C66,C81,C84,C85,C86,C88,C95,C96,C108,C109,C112 | 10u | Capacitor_SMD:C_0603_1608Metric,Capacitor_SMD:C_1206_3216Metric | Unpolarized capacitor | 26
C8,C47,C79,C80 | 4.7u | Capacitor_SMD:C_0603_1608Metric | 0603X475K100CT | 4
C9,C10,C50 | 1n | Capacitor_SMD:C_0603_1608Metric | Unpolarized capacitor | 3
C11,C14,C15,C122 | 100p | Capacitor_SMD:C_0402_1005Metric | 0402N101J500CG | 4
C13 | 10p | Capacitor_SMD:C_0402_1005Metric | GRM1555C1H100GA01D | 1
C18,C24,C30,C31,C32,C33,C35,C37,C38,C42,C43,C53,C54,C55,C58,C60,C61,C63,C70,C72,C74,C75,C76,C77,C78,C91,C92,C93,C94,C98,C99,C100,C101,C102,C103,C104,C105,C106,C107,C110,C113,C114,C117,C118,C119,C121,C134,C135 | 100n | Capacitor_SMD:C_0603_1608Metric | Unpolarized capacitor | 48
C19,C21,C22,C23,C29,C56,C59,C67,C69,C82,C89,C90,C97,C111,C115,C116,C120,C125,C126,C127,C128,C129,C130,C132,C133,C137 | 1u | Capacitor_SMD:C_0603_1608Metric | Unpolarized capacitor | 26
C28,C87 | 220n | Capacitor_SMD:C_0603_1608Metric |  | 2
C39 | 4.7n | Capacitor_SMD:C_0603_1608Metric | Unpolarized capacitor | 1
C40,C41 | 4.7p | Capacitor_SMD:C_0603_1608Metric | Unpolarized capacitor | 2
C44,C45 | 10n | Capacitor_SMD:C_0603_1608Metric | Unpolarized capacitor | 2
C46,C131 | 2.2u | Capacitor_SMD:C_0603_1608Metric | GRM188R60J225KE19D,Unpolarized capacitor | 2
C48,C49 | 6.2p | Capacitor_SMD:C_0402_1005Metric | Unpolarized capacitor | 2
C52 | 1nF/2kV | Capacitor_SMD:C_1206_3216Metric | 1206B102K202 | 1
C68 | 39p | Capacitor_SMD:C_0603_1608Metric | Unpolarized capacitor | 1
C71,C73,C83 | 6.8n | Capacitor_SMD:C_0603_1608Metric | Unpolarized capacitor | 3
C123 | 10u / 50V | Capacitor_SMD:C_1206_3216Metric | Unpolarized capacitor | 1
C124 | 1n / 50V | Capacitor_SMD:C_0603_1608Metric | Unpolarized capacitor | 1
C136 | 470n | Capacitor_SMD:C_0603_1608Metric | Unpolarized capacitor | 1
D1 | STPS5L60S | Diode_SMD:D_SMC | STPS5L60S | 1
D2 | MBR0530 | Diode_SMD:D_SOD-123 | 30V 0.5A Schottky Power Rectifier Diode, SOD-123 | 1
D3 | BZV55C24-DC | Diode_SMD:D_MiniMELF | BZV55C24-DC | 1
D5 | SMBJ33CA | Diode_SMD:D_SMB | SMBJ33CA | 1
D7,D10 | SMBJ36A-13-F | Diode_SMD:D_SMB | SMBJ36A-13-F | 2
D8,D11 | PMEG6030EP | Diode_SMD:D_SOD-128 | 60V, 3A low Vf MEGA Schottky barrier rectifier, SOD-128 | 2
D9 | CDSOT23-T24CAN | Package_TO_SOT_SMD:TSOT-23 | CDSOT23-T24CAN | 1
D12,D13,D14,D15,D16,D17,D18,D19,D20,D21,D22,D23,D24,D25,D26,D27,D28,D29,D30,D32,D33,D34,D35,D36,D37,D38,D39,D40,D41,D42,D43 | STN061050BL40 | Diode_SMD:D_0603_1608Metric | STN061050BL40 | 31
F1 | PTC 2A | Fuse:Fuse_1812_4532Metric_Pad1.30x3.40mm_HandSolder | SD200-08 | 1
FB1,FB7 | 100 @ 100MHz | Inductor_SMD:L_0603_1608Metric_Pad1.05x0.95mm_HandSolder | WLBD1608HCU101TL | 2
FB2,FB4 | MFBM1V2012-601-R | Inductor_SMD:L_0805_2012Metric | MFBM1V2012-601-R | 2
FB3,FB5,FB6 | 100R @ 100MHz | Inductor_SMD:L_0603_1608Metric | WLBD1608HCU101TL | 3
FL1 | ACT45B-510-2P-TL003 | SamacSys_Parts:ACT45B1012PTL003 | Common Mode Filters / Chokes, |Z|=2800 at 10MHz, L x W x T : | 1
GD1,GD2 | 3R090-5S | SamacSys_Parts:3R090A5S | Leiditech 3R090-5S | 2
IC1 | NS2009 | SamacSys_Parts:SOP50P490X112-10N | 4-Wire Touch Screen Controller | 1
IC2 | TPS61240DRVT | SamacSys_Parts:SON65P200X200X80-7N | Switching Voltage Regulators 5V 400mA 4MHz Step- Up DC/DC Cnvrtr | 1
IC3 | ATA6561-GAQW-N | SamacSys_Parts:SOIC127P600X175-8N | MICROCHIP - ATA6561-GAQW-N - CAN TRANSCEIVER, 5MBPS, -40 TO 150DEG C | 1
IC4 | MAX2674EWT+T | SamacSys_Parts:BGA6C40P2X3_83X123X69 | RF Amplifier GPS/GNSS LNAs with Antenna Switch and Bias | 1
J1 | MCSP-Q-08-A-SG-T_R | SamacSys_Parts:MCSPQ08ASGTR | Connector: for cards | SD Micro | push-push | SMT | gold flash | 1
J2 | MEM2067-02-180-00-A | SamacSys_Parts:MEM20670218000A | GCT (GLOBAL CONNECTOR TECHNOLOGY) - MEM2067-02-180-00-A - Memory Socket, MEM2067 Series, Memory Card, 8 Contacts, Copper Alloy, Gold Plated Contacts | 1
J3 | BATT | Connector_JST:JST_PH_S2B-PH-SM4-TB_1x02-1MP_P2.00mm_Horizontal |  | 1
J4,J5,J10 | Conn_01x02 | Connector_PinHeader_1.00mm:PinHeader_1x02_P1.00mm_Vertical,Connector_PinSocket_2.00mm:PinSocket_1x02_P2.00mm_Vertical | Generic connector, single row, 01x02, script generated (kicad-library-utils/schlib/autogen/connector/),PWR_ON,TS | 3
J7,J8 | Conn_Coaxial_Small | Connector_Coaxial:U.FL_Hirose_U.FL-R-SMT-1_Vertical | small coaxial connector (BNC, SMA, SMB, SMC, Cinch/RCA, LEMO, ...) | 2
J9 | TF07V-40S-0.5SH_800_ | SamacSys_Parts:TF07V40S05SH800 | FFC & FPC Connectors Receptacle, 0.5mm pitch, 40pos | 1
J12 | Conn_01x07_Socket | Connector_JST:JST_PH_S7B-PH-K_1x07_P2.00mm_Horizontal | Generic connector, single row, 01x07, script generated | 1
J13 | Conn_01x05_Socket | Connector_JST:JST_PH_S5B-PH-K_1x05_P2.00mm_Horizontal | Generic connector, single row, 01x05, script generated | 1
J14 | Conn_01x08_Socket | Connector_JST:JST_PH_S8B-PH-K_1x08_P2.00mm_Horizontal | Generic connector, single row, 01x08, script generated | 1
J15 | Conn_01x12_Socket | Connector_JST:JST_PH_S12B-PH-K_1x12_P2.00mm_Horizontal | Generic connector, single row, 01x12, script generated | 1
L1 | 1uH | Inductor_SMD:L_0603_1608Metric | LQM18PN1R0MFHD | 1
L2 | LQH3NPN2R2MMEL | SamacSys_Parts:LQH3NPN100MMEL | LQH3NPN_ME Series Inductor 2.2uH +/-20% 1212 (3030) | 1
L3 | 10uH | Inductor_SMD:L_1210_3225Metric | LQH32PN100MN0L | 1
L7 | 8.2uH | Local_L:HCM0703 | HCM0703-8R2-R | 1
L8,L10 | 4.7uH | Inductor_SMD:L_APV_ANR5040 | NRS5040T4R7NMGK | 2
L9 | 2.2uH | Inductor_SMD:L_APV_ANR4018 | NRS4018T2R2MDGJ | 1
Q2 | BSS138 | Package_TO_SOT_SMD:SOT-23 | 50V Vds, 0.22A Id, N-Channel MOSFET, SOT-23 | 1
R1 | 240R 1% | Resistor_SMD:R_0402_1005Metric | SMD0402-240R-1% | 1
R2 | 6k 1% | Resistor_SMD:R_0603_1608Metric |  | 1
R3,R4,R29,R32 | 200k | Resistor_SMD:R_0603_1608Metric | Resistor | 4
R5 | 10k NTC | Resistor_SMD:R_0603_1608Metric | Thermistor NTC for battery | 1
R6 | 330k | Resistor_SMD:R_0603_1608Metric |  | 1
R7,R41,R43,R54 | 10k | Resistor_SMD:R_0603_1608Metric | Resistor | 4
R8,R9 | 1k | Resistor_SMD:R_0603_1608Metric |  | 2
R10,R11 | 2.2k | Resistor_SMD:R_0603_1608Metric |  | 2
R12,R30,R48,R58,R59,R60,R61,R62,R63,R64,R65,R66,R67 | 47k | Resistor_SMD:R_0603_1608Metric | Resistor | 13
R13,R15 | 82 | Resistor_SMD:R_0603_1608Metric | Resistor | 2
R14,R16 | 49.9 | Resistor_SMD:R_0603_1608Metric | Resistor | 2
R17 | 10 | Resistor_SMD:R_0603_1608Metric | Resistor | 1
R18,R19 | 75 | Resistor_SMD:R_0603_1608Metric | Resistor | 2
R20,R26 | 150 | Resistor_SMD:R_0603_1608Metric | Resistor | 2
R21,R22 | 59 | Resistor_SMD:R_0603_1608Metric | Resistor | 2
R23 | 560 | Resistor_SMD:R_0603_1608Metric | Resistor | 1
R24,R25,R31,R33,R57,R68,R69 | 100k | Resistor_SMD:R_0603_1608Metric | Resistor | 7
R27,R28 | 2k 1% | Resistor_SMD:R_0603_1608Metric |  | 2
R34 | 162k | Resistor_SMD:R_0603_1608Metric | ERJ3EKF1623V | 1
R35 | 13k | Resistor_SMD:R_0603_1608Metric |  | 1
R36 | 53.6k | Resistor_SMD:R_0603_1608Metric |  | 1
R37 | 10.2k | Resistor_SMD:R_0603_1608Metric |  | 1
R38 | 523k | Resistor_SMD:R_0603_1608Metric |  | 1
R39 | 84.5k | Resistor_SMD:R_0603_1608Metric |  | 1
R40 | 0.03 | Resistor_SMD:R_1206_3216Metric |  | 1
R42 | 62 | Resistor_SMD:R_0603_1608Metric |  | 1
R44,R45 | 10R Pulse-proof | Resistor_SMD:R_1206_3216Metric | Resistor | 2
R46,R47,R52,R55,R56 | 33 | Resistor_SMD:R_0603_1608Metric | ERJ3EKF1623V,Resistor | 5
R49,R50 | 100 | Resistor_SMD:R_0603_1608Metric | Resistor | 2
R51 | 0 | Resistor_SMD:R_0603_1608Metric | Resistor | 1
R53 | 2k | Resistor_SMD:R_0603_1608Metric | Resistor | 1
T1 | H1102NL | SamacSys_Parts:SOIC127P940X597-16N | PULSE ELECTRONICS - H1102NL - TRANSFORMER, 1:1, 1PORT, 100BASE-TX, SMT | 1
TP1,TP2,TP3,TP4,TP5,TP6,TP7,TP8,TP9,TP10,TP11,TP12,TP13,TP14,TP15,TP16 | TestPoint | TestPoint:TestPoint_Pad_D1.0mm | test point | 16
U1 | MCP2518FD-xQBB | Package_DFN_QFN:DFN-14-1EP_3x4.5mm_P0.65mm_EP1.65x4.25mm | CAN FD Controller with SPI Interface, up to 8 Mbps, Vdd 2.7..5.5V, functional safety ready, VDFN-14 | 1
U2 | V3S | Local_L:ELQFP-128 |  | 1
U3 | TPS54360DDA | Package_SO:TI_SO-PowerPAD-8_ThermalVias | 3.5A, Step Down DC-DC Converter with Eco-mode, 4.5-60V Input Voltage, PowerSO-8 | 1
U4 | SY8088AAC | Package_TO_SOT_SMD:SOT-23-5 |  | 1
U5 | STM32L432KCUx | Package_DFN_QFN:QFN-32-1EP_5x5mm_P0.5mm_EP3.1x3.1mm | STMicroelectronics Arm Cortex-M4 MCU, 256KB flash, 64KB RAM, 80 MHz, 1.71-3.6V, 26 GPIO, UFQFPN32 | 1
U6 | MAX-M10S | RF_GPS:ublox_MAX | GNSS Module MAX M10, VCC 1.65V to 3.6V | 1
U7 | AXP209 | Local_L:AXP209-QFN48 |  | 1
U8 | TPS61041DBV | Package_TO_SOT_SMD:SOT-23-5 | Synchronous Boost Regulator, Adjustable Output up to 28V, 250 mA Switch Current Limit, SOT-23-5 | 1
U9,U10 | USBLC6-2SC6 | Package_TO_SOT_SMD:SOT-23-6_Handsoldering | Very low capacitance ESD protection diode, 2 data-line, SOT-23-6 | 2
U11 | TPA6132A2RTE | Package_DFN_QFN:WQFN-16-1EP_3x3mm_P0.5mm_EP1.6x1.6mm_ThermalVias | 25mW, Stereo, DirectPath Audio Amplifier, WQFN-16 | 1
U701,U702 | GAQY212GS | Package_SO:SOP-4_3.8x4.1mm_P2.54mm | Form A, Solid State Relay (Photo MOSFET) 60V, 0.075A, 10Ohm, AC/DC, SO-4 | 2
Y1 | 3225-20M-SR | Crystal:Crystal_SMD_3225-4Pin_3.2x2.5mm | Four pin crystal, GND on pins 2 and 4 | 1
Y2 | CX2016FB24000D0FZZ | Crystal:Crystal_SMD_2016-4Pin_2.0x1.6mm | Four pin crystal, GND on pins 2 and 4 | 1
Y3 | 32.768kHz | Crystal:Crystal_SMD_MicroCrystal_CC7V-T1A-2Pin_3.2x1.5mm | WTL1X80739BEL | 1

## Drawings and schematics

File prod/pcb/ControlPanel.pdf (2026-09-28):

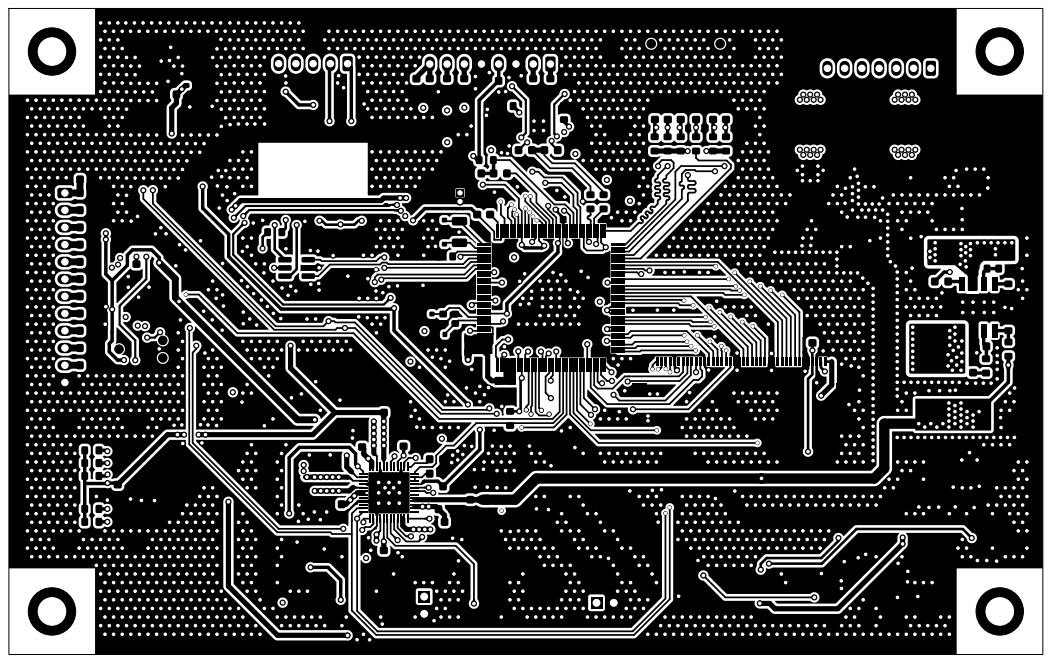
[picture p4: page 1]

Size: A4 | Rev:
KiCad E.D.A. 10.0.4 | Id: 1/6

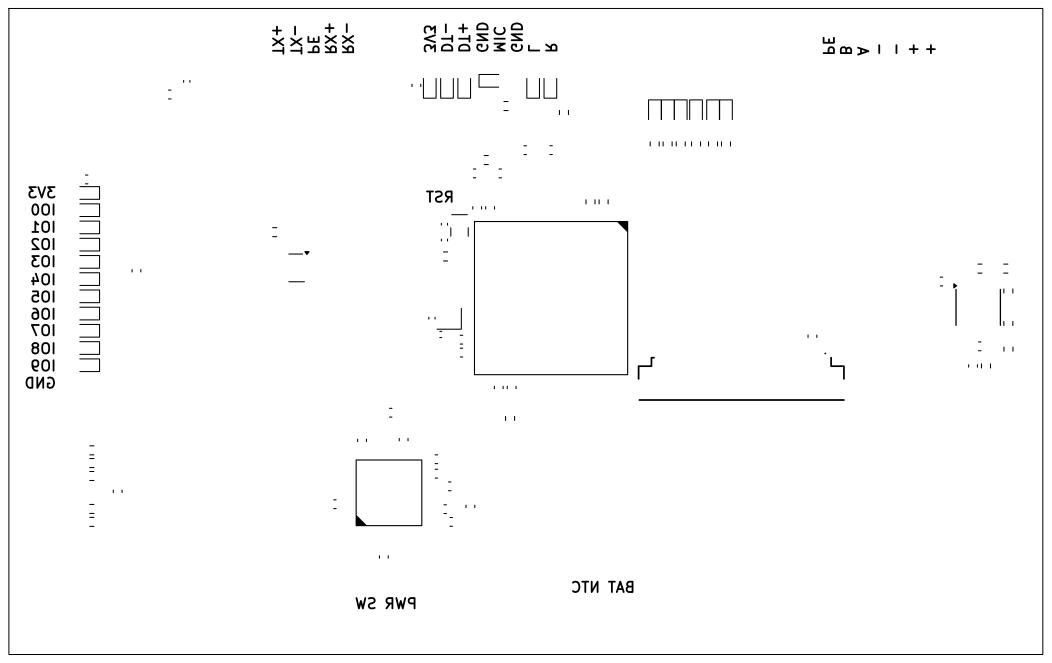
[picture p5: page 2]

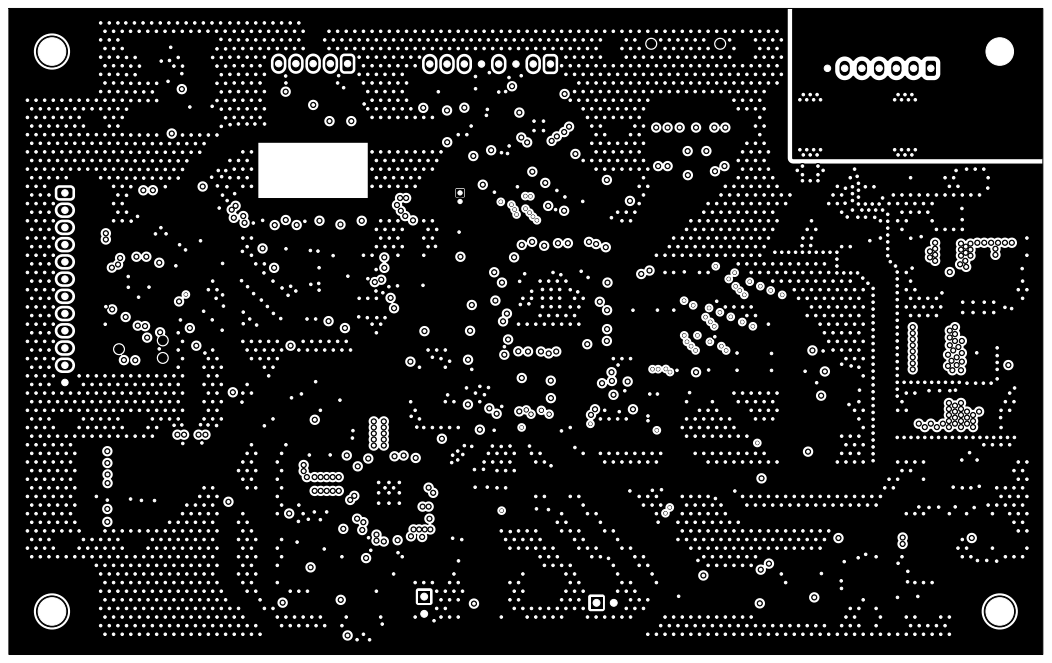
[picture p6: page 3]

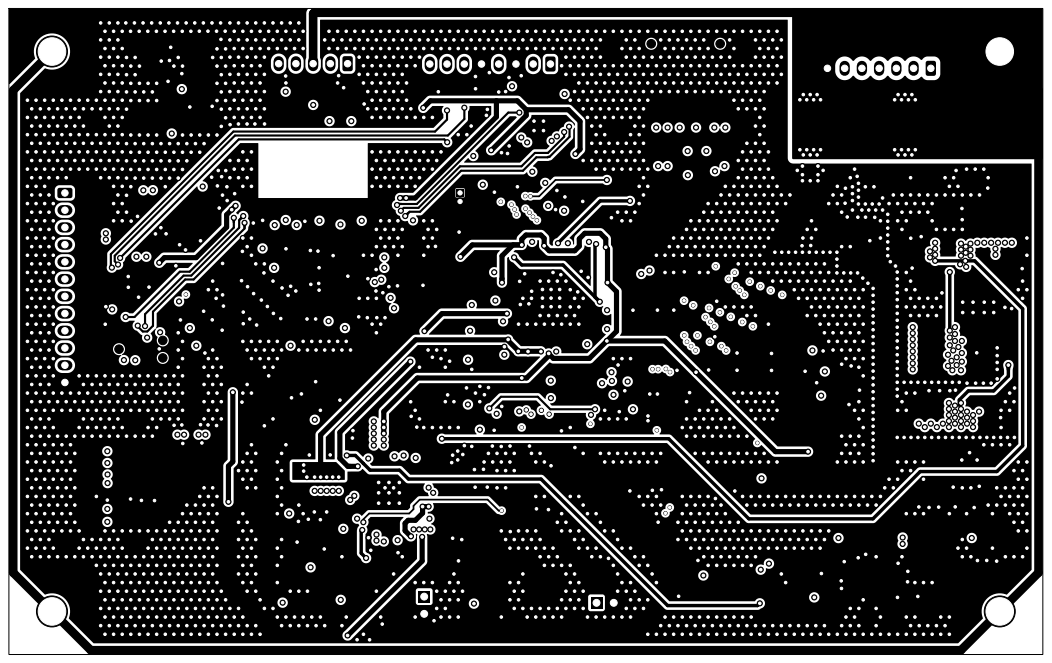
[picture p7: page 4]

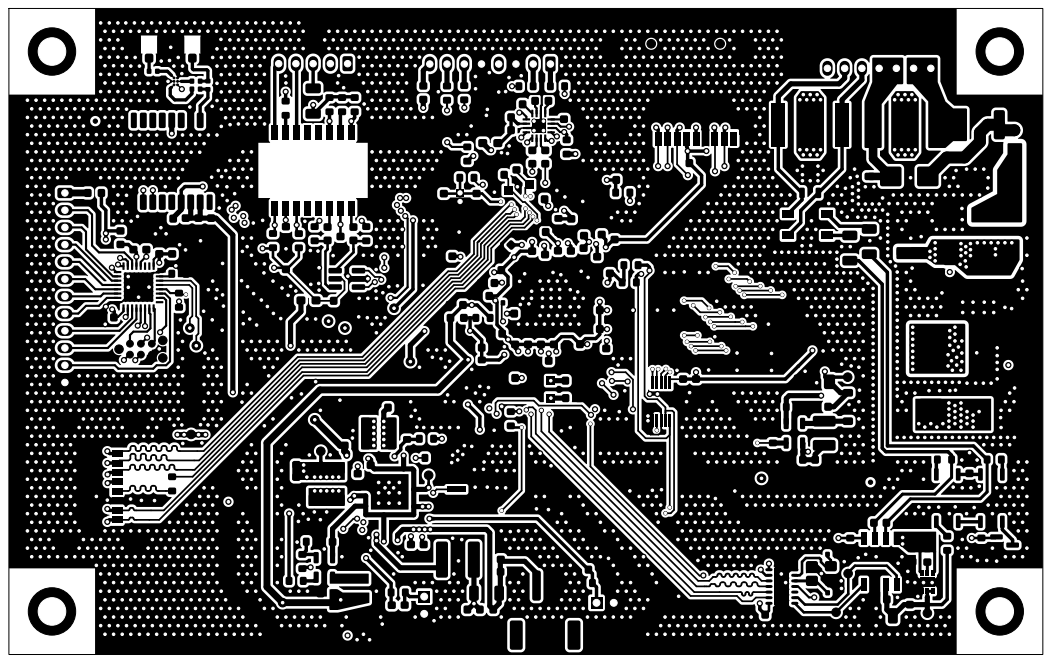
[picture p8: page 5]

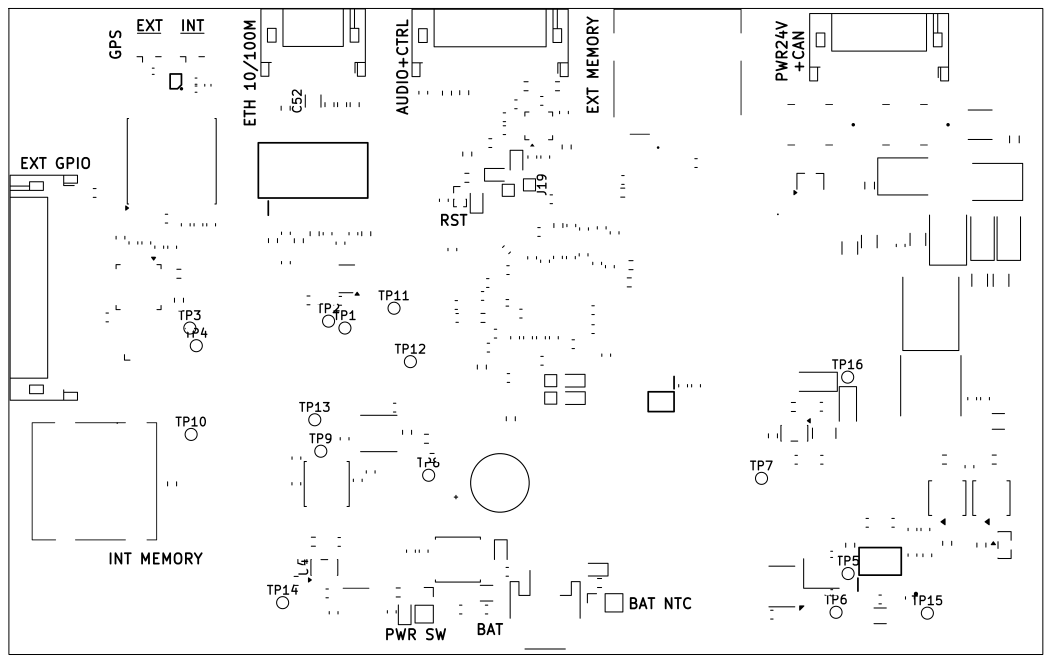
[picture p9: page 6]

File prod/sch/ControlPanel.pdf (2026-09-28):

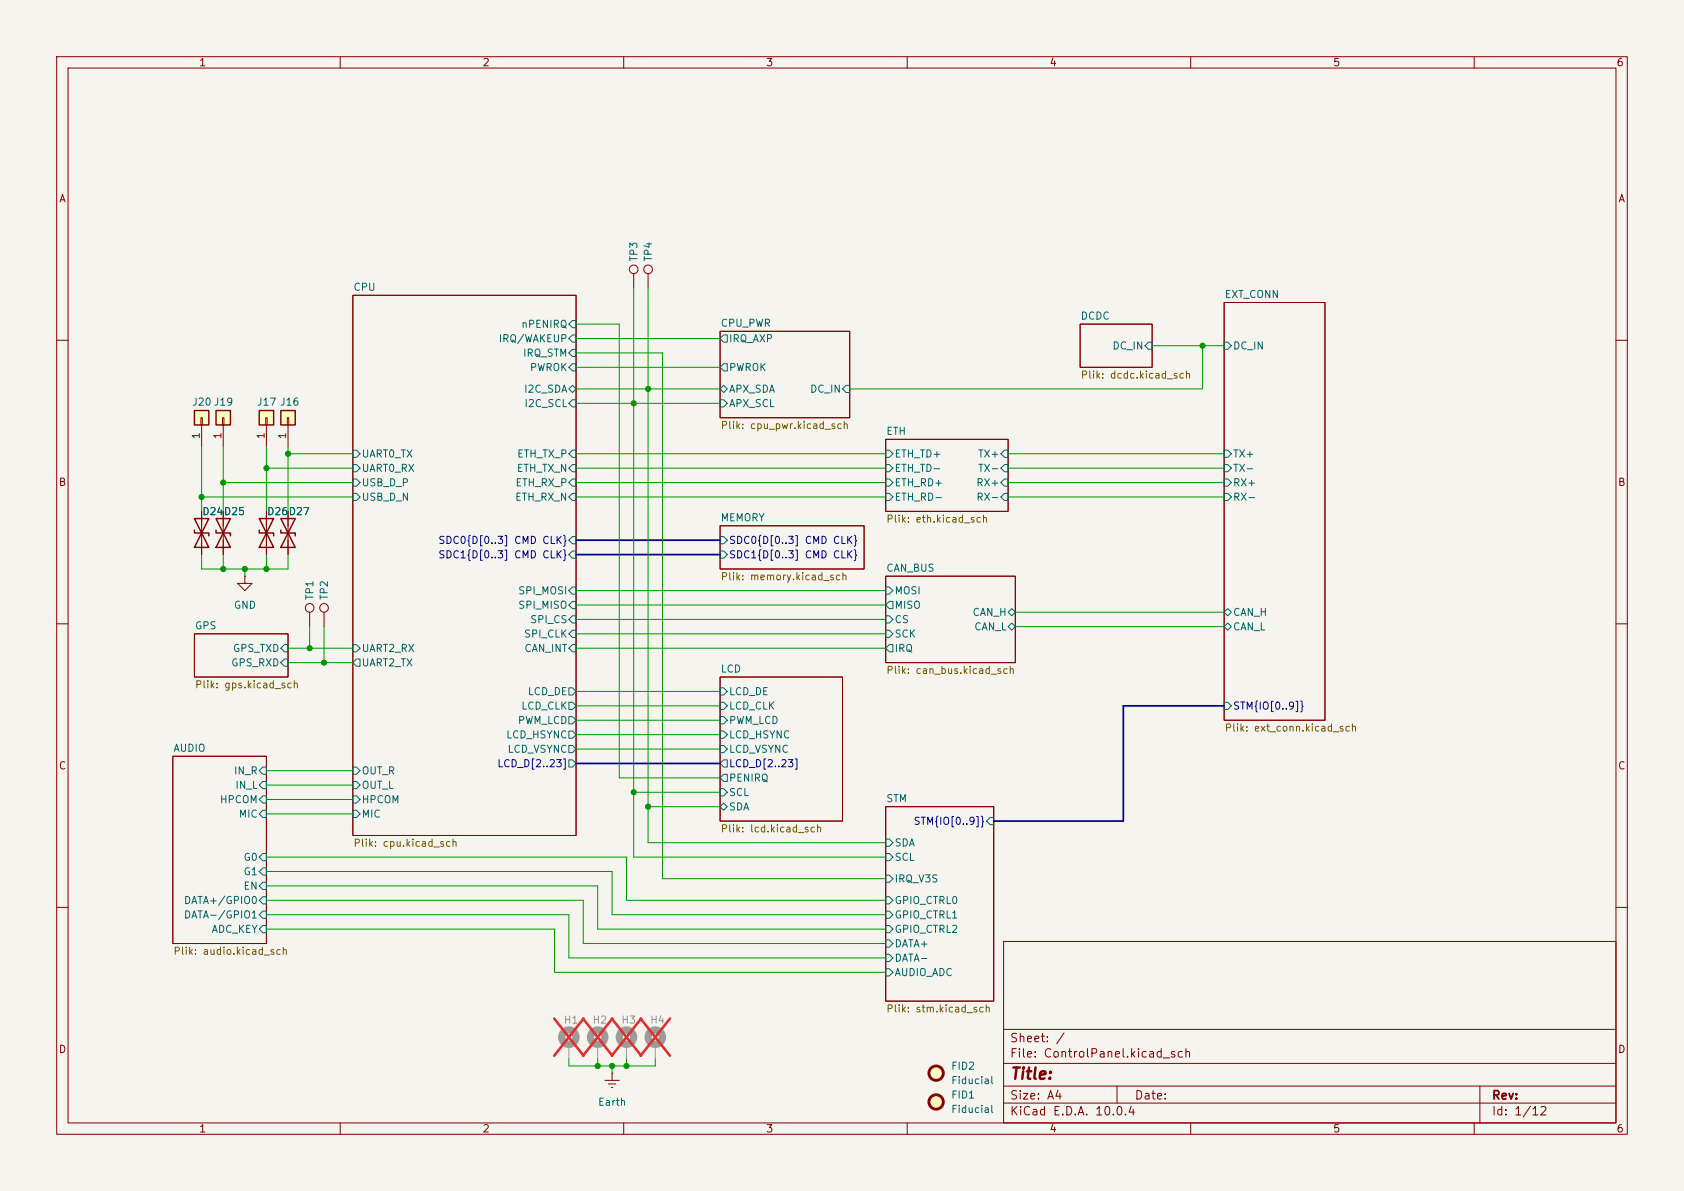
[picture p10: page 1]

SDC1{D[0..3] CMD CLK} MEMORY Plik: memory.kicad_sch 1

IRQ MISO MOSI CS

Size: A4 | Rev:
KiCad E.D.A. 10.0.4 | Id: 1/12

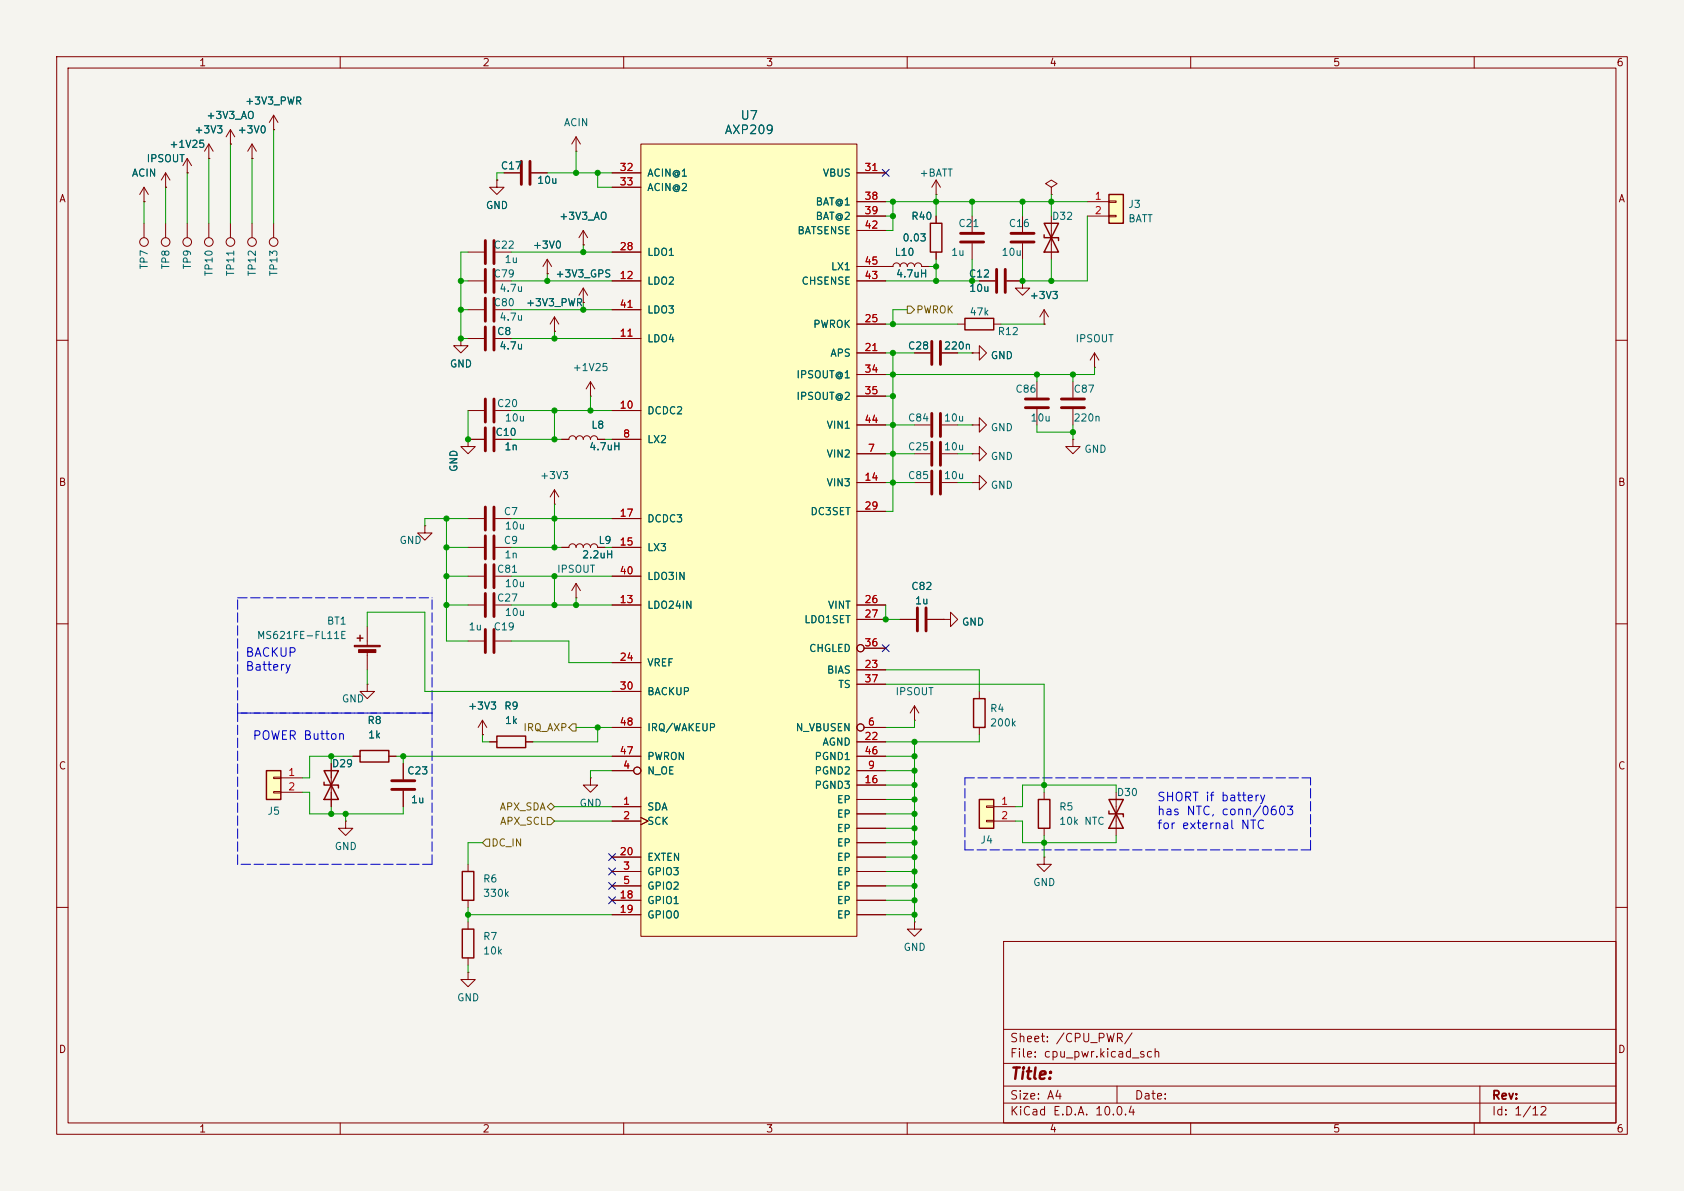
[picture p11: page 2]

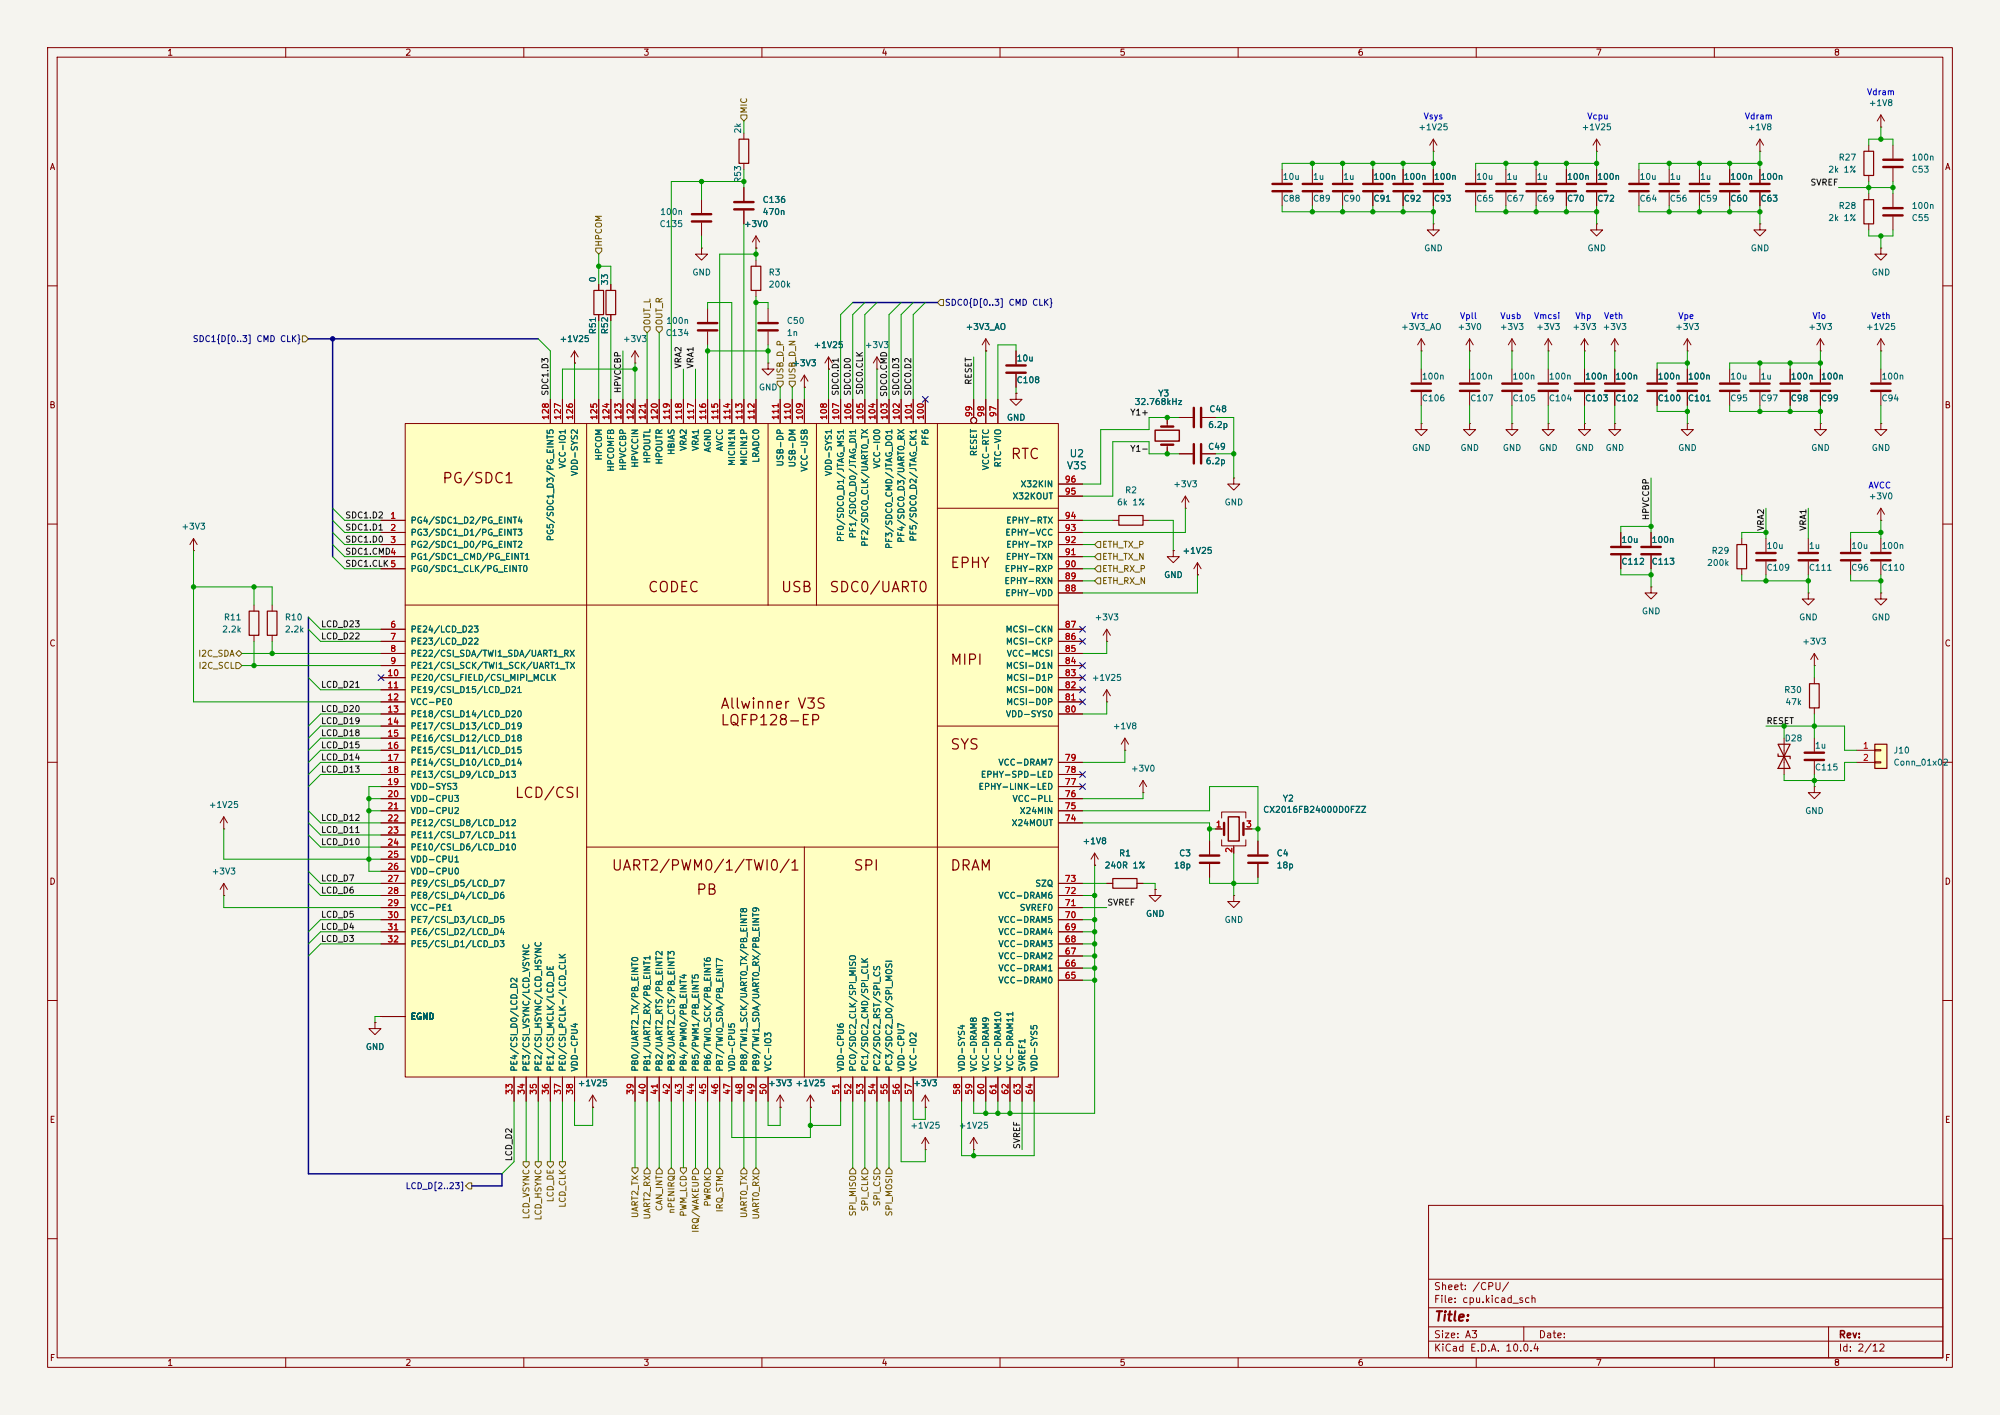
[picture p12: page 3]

Size: A3 | Rev:

F Date:

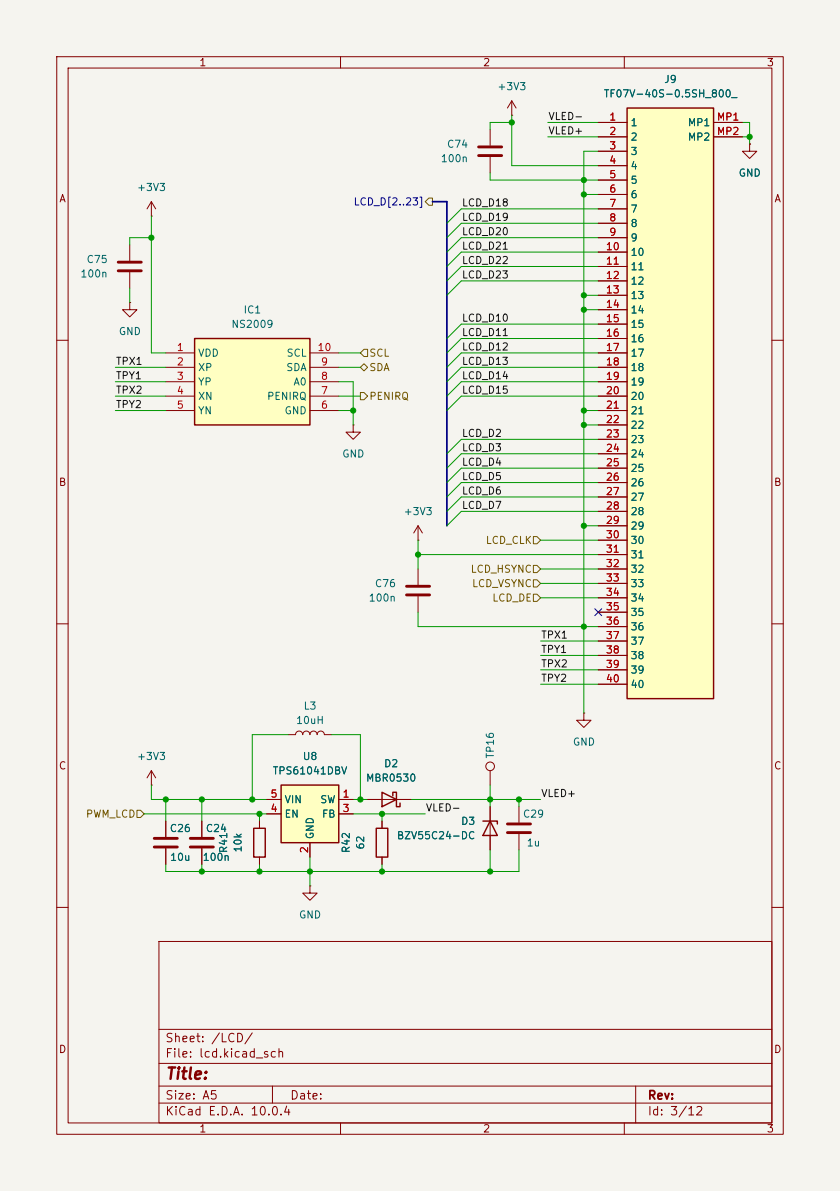
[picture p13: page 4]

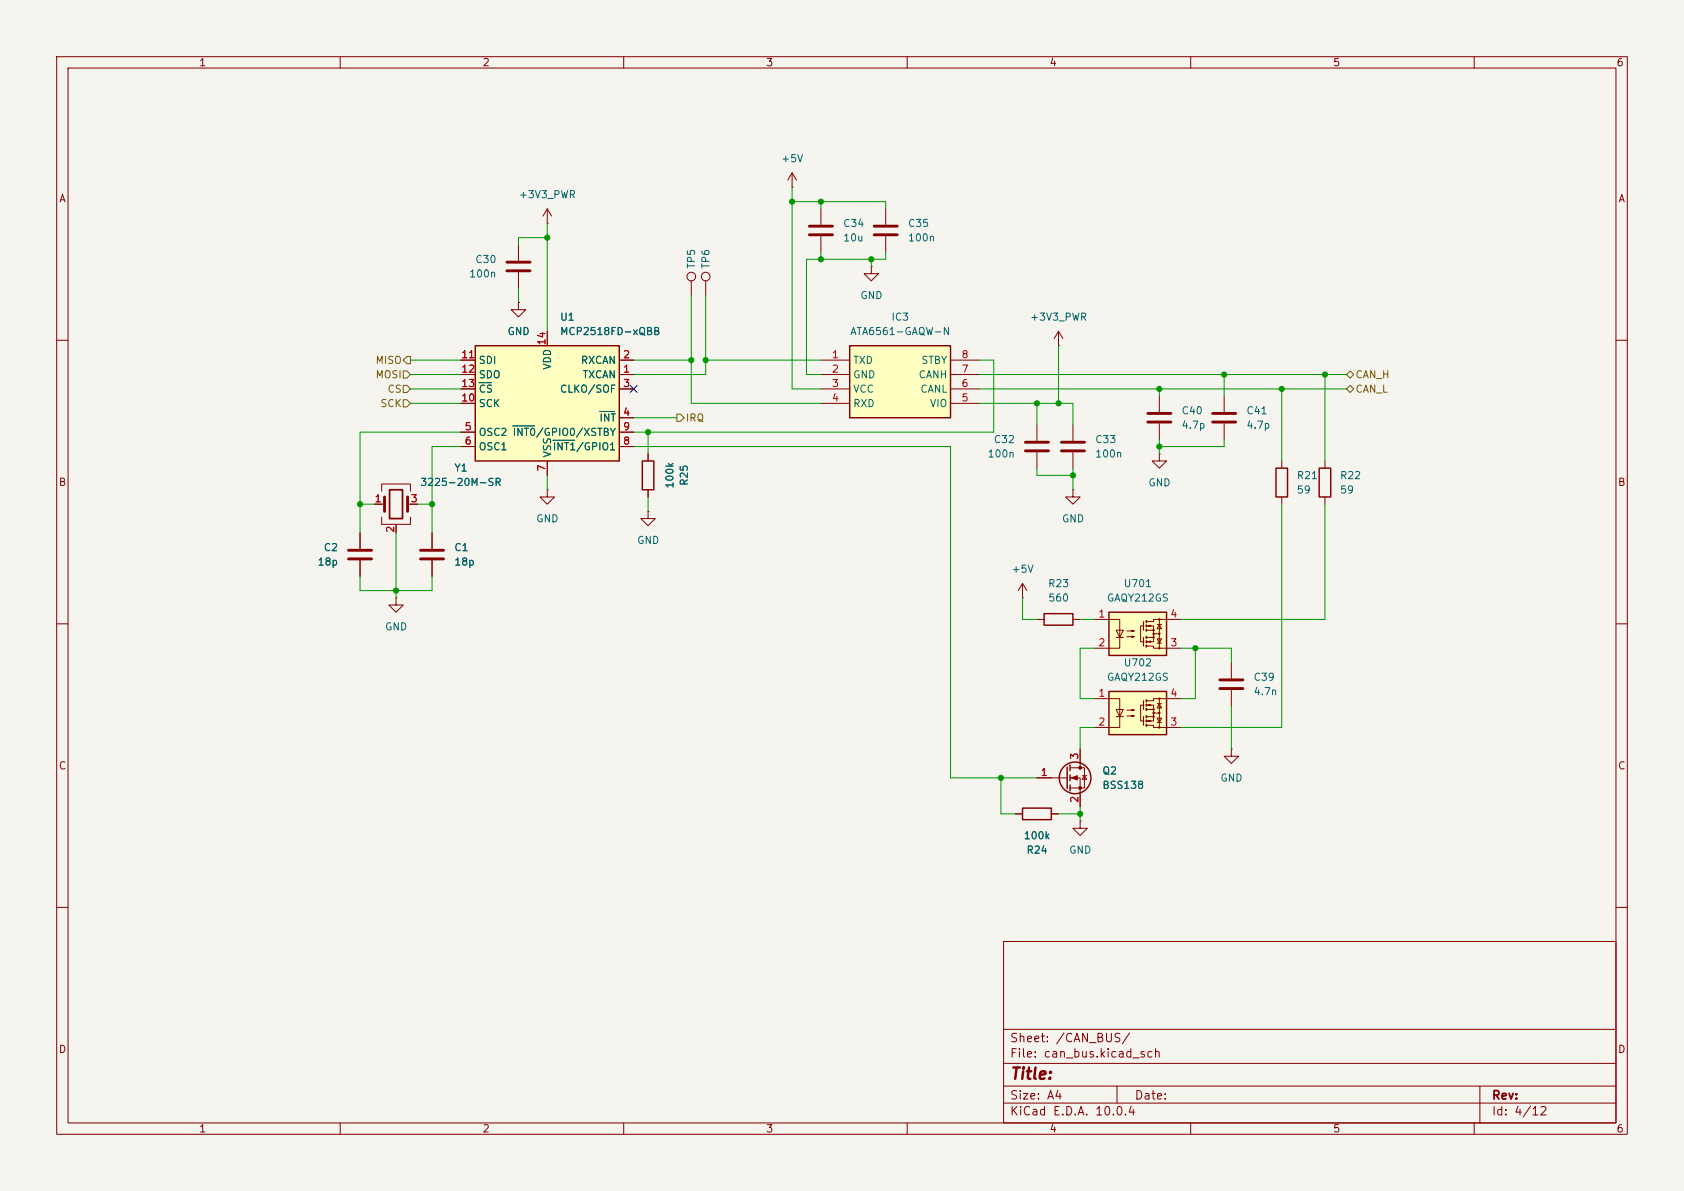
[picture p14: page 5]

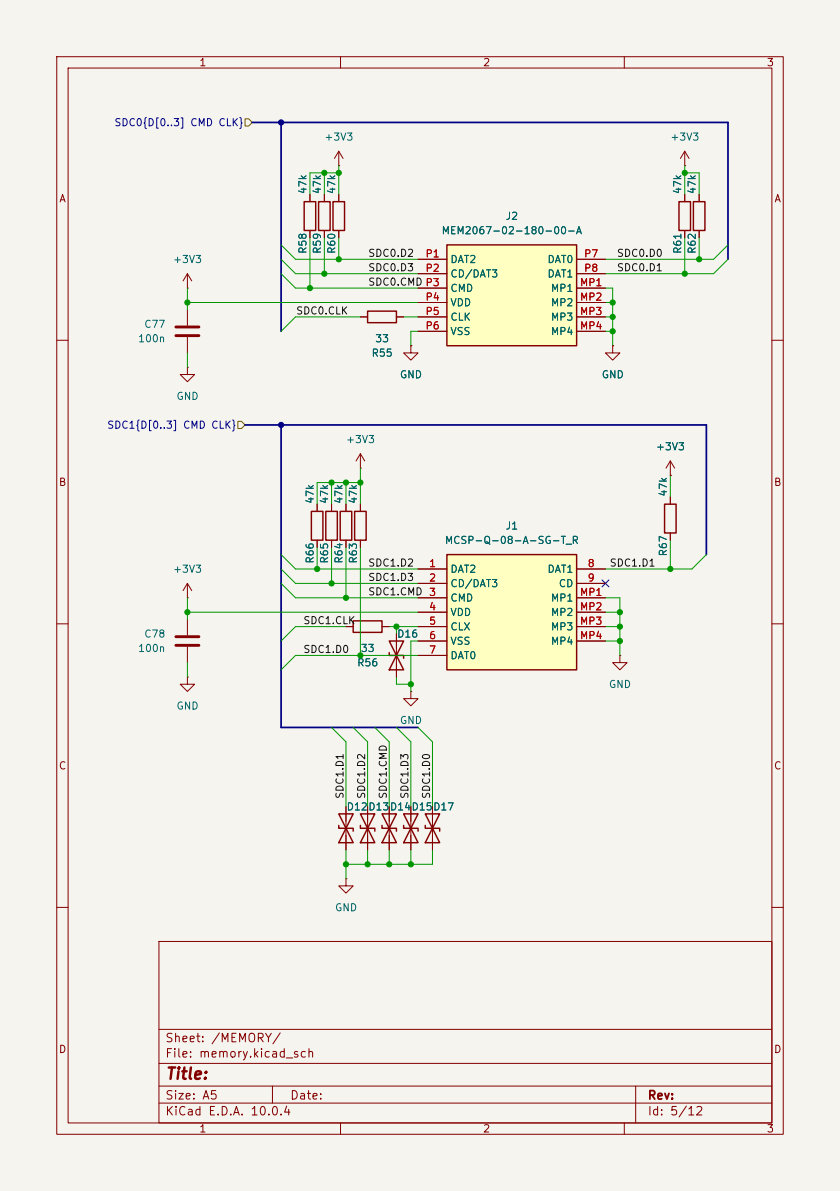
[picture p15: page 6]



Size: A5 | Rev: | C Date:
KiCad E.D.A. 10.0.4 | Id: 7/12


1 PC14 2 PC15 3 NRST 4 VDDA 5 PA0 6 PA1 7 PA2 8 PA3 9 PA4 10 PA5 11 PA6 12 PA7 13 PB0 14 PB1 15 VSS 16 VDD 17 PA8 18 PA9 19 PA10 20 PA11 21 PA12 22 PA13 23 PA14 24 PA15 25 PB3 26 PB4 27 PB5 28 PB6 29 PB7 30 PH3 31 U5

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




8 CPN 9 PGND 10 CPP 11 HPVDD 12

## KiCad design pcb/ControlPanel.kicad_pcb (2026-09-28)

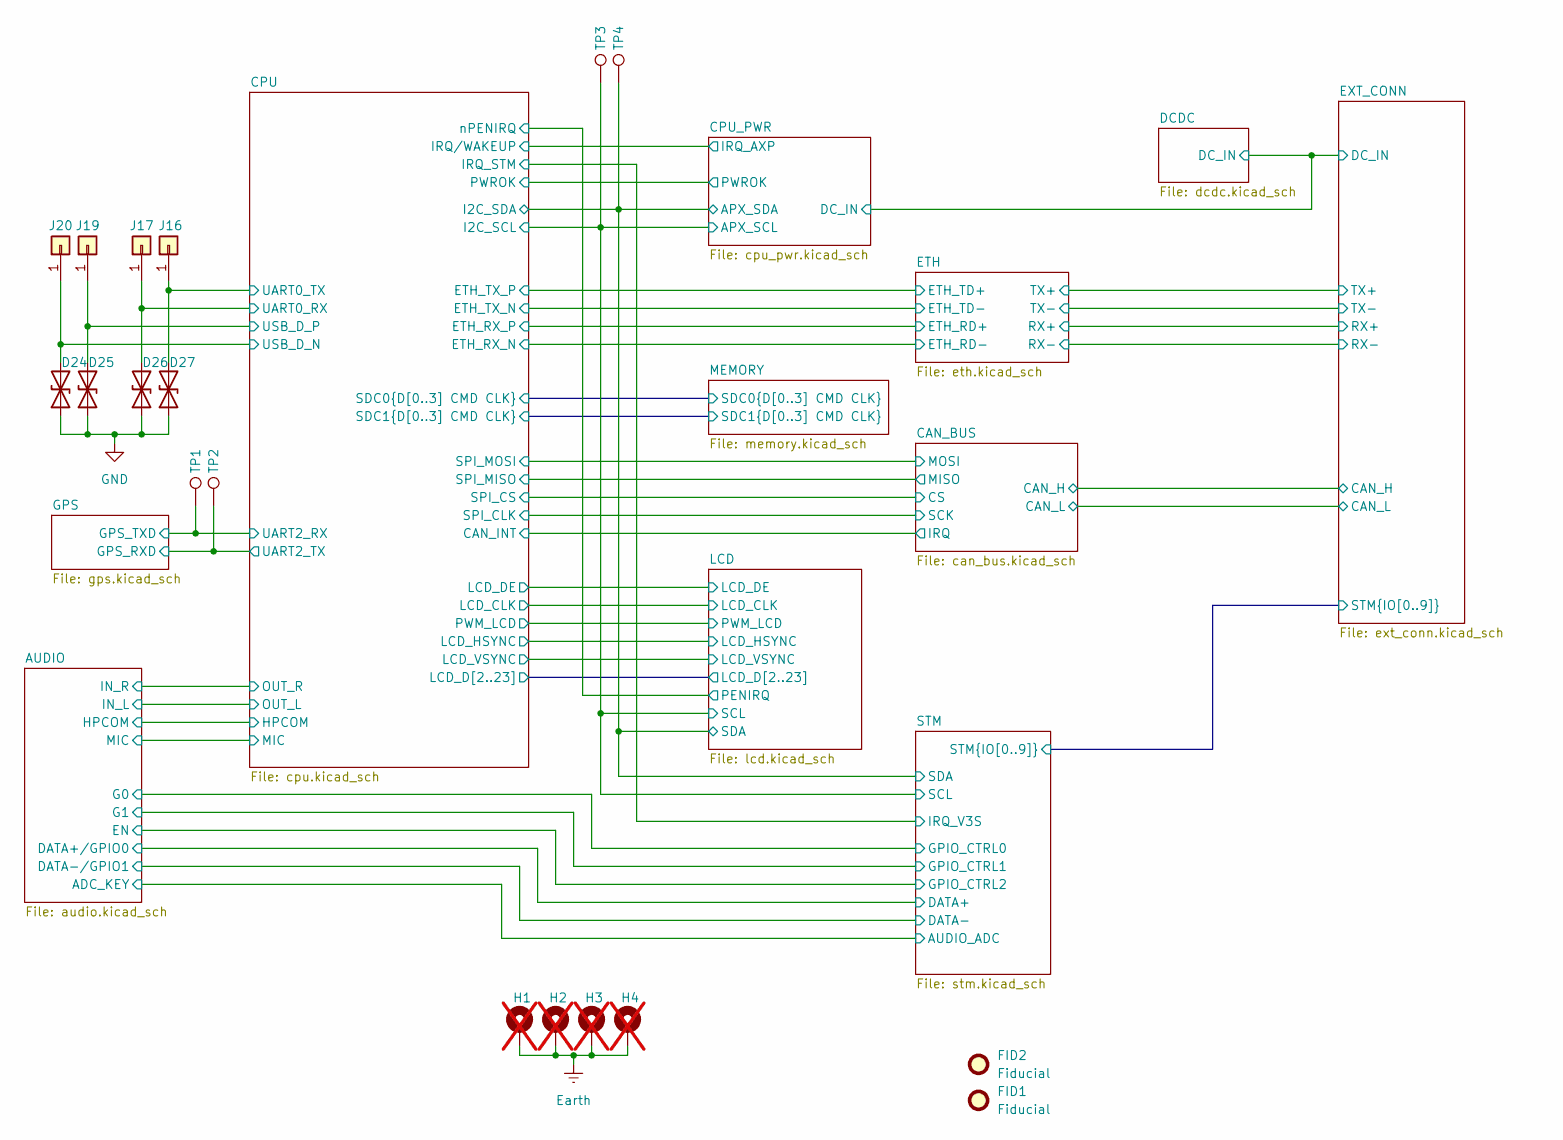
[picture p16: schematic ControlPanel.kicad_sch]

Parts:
D24, D25, D26, D27: STN061050BL40; D_0603_1608Metric
FID1, FID2: Fiducial; Fiducial_0.5mm_Mask1mm
H1, H2, H3, H4: MountingHole_Pad; MountingHole_3.2mm_M3_ISO14580_Pad_TopBottom; not fitted
J16, J17, J19, J20: Conn_01x01; TestPoint_Pad_1.0x1.0mm
TP1, TP2, TP3, TP4: TestPoint; TestPoint_Pad_D1.0mm

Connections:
/CPU/I2C_SCL: TP3.1 (1_1); also elsewhere on the board
/CPU/I2C_SDA: TP4.1 (1_1); also elsewhere on the board
/CPU/UART0_RX: D26.2 (A2), J17.1 (Pin_1_1); also elsewhere on the board
/CPU/UART0_TX: D27.2 (A2), J16.1 (Pin_1_1); also elsewhere on the board
/CPU/UART2_RX: TP1.1 (1_1); also elsewhere on the board
/CPU/UART2_TX: TP2.1 (1_1); also elsewhere on the board
/CPU/USB_D_N: D24.2 (A2), J20.1 (Pin_1_1); also elsewhere on the board
/CPU/USB_D_P: D25.2 (A2), J19.1 (Pin_1_1); also elsewhere on the board
Earth: H1.1 (1_1), H2.1 (1_1), H3.1 (1_1), H4.1 (1_1); also elsewhere on the board
GND: D24.1 (A1), D25.1 (A1), D26.1 (A1), D27.1 (A1); also elsewhere on the board

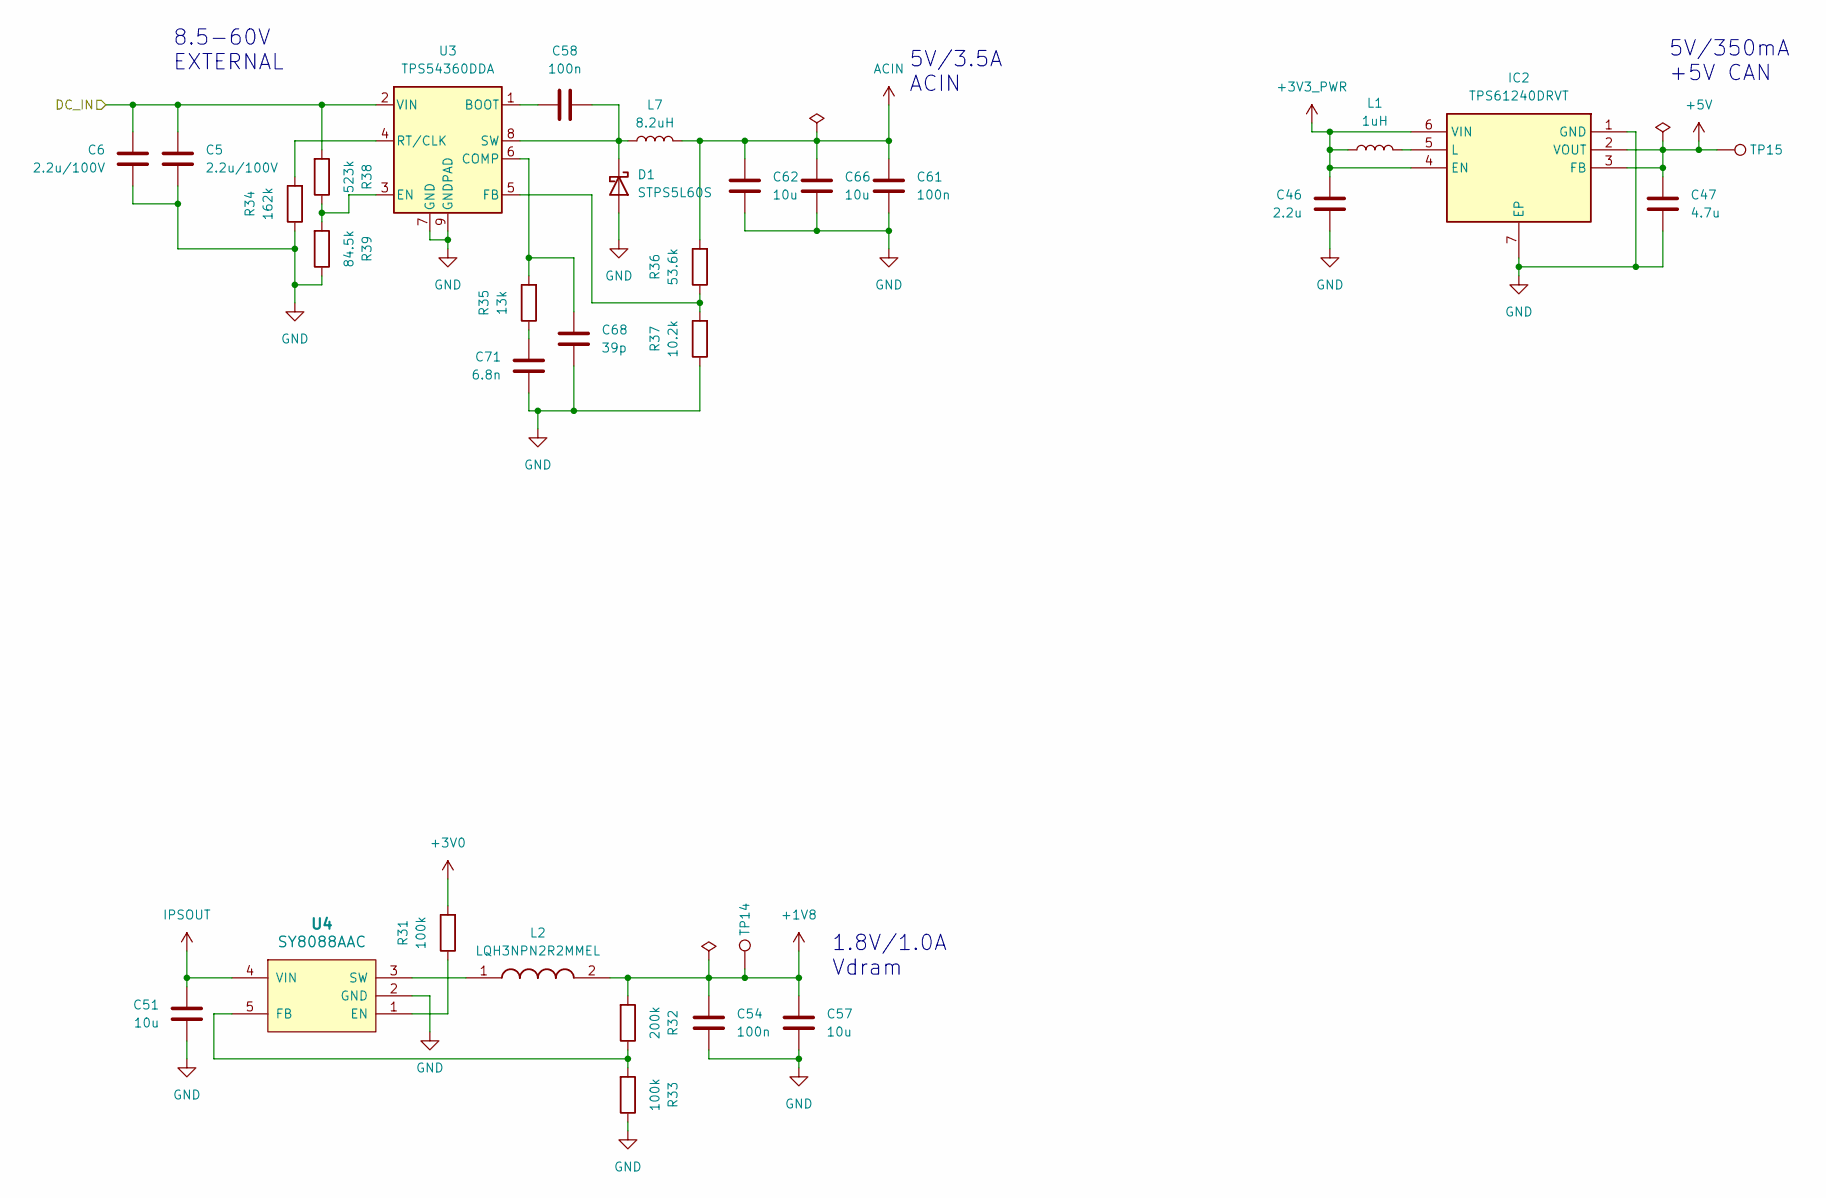
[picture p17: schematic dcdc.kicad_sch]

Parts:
C5, C6: 2.2u/100V; C_1206_3216Metric; Manufacturer_Part_Number KGM31HR72A225KU
C46: 2.2u; C_0603_1608Metric
C47: 4.7u; C_0603_1608Metric
C51, C57, C62, C66: 10u; C_0603_1608Metric
C54, C58, C61: 100n; C_0603_1608Metric; Manufacturer_Part_Number GRM188R71H104KA93D
C68: 39p; C_0603_1608Metric
C71: 6.8n; C_0603_1608Metric
D1: STPS5L60S; D_SMC; Manufacturer_Part_Number STPS5L60S
IC2: TPS61240DRVT; SON65P200X200X80-7N; Manufacturer_Part_Number TPS61240DRVT; Mouser Part Number 595-TPS61240DRVT
L1: 1uH; L_0603_1608Metric
L2: LQH3NPN2R2MMEL; LQH3NPN100MMEL; Manufacturer_Part_Number LQH3NPN2R2MMEL; Mouser Part Number 81-LQH3NPN2R2MMEL
L7: 8.2uH; HCM0703; Manufacturer_Part_Number HCM0703-8R2-R
R31, R33: 100k; R_0603_1608Metric
R32: 200k; R_0603_1608Metric
R34: 162k; R_0603_1608Metric; Manufacturer_Part_Number ERJ3EKF1623V
R35: 13k; R_0603_1608Metric
R36: 53.6k; R_0603_1608Metric
R37: 10.2k; R_0603_1608Metric
R38: 523k; R_0603_1608Metric
R39: 84.5k; R_0603_1608Metric
TP14, TP15: TestPoint; TestPoint_Pad_D1.0mm
U3: TPS54360DDA; TI_SO-PowerPAD-8_ThermalVias
U4: SY8088AAC; SOT-23-5

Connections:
+1V8: C54.1, C57.1, L2.2, R32.2, TP14.1 (1_1); also elsewhere on the board
+3V0: R31.2; also elsewhere on the board
+3V3_PWR: C46.2, IC2.4 (EN), IC2.6 (VIN), L1.2; also elsewhere on the board
+5V: C47.2, IC2.2 (VOUT), IC2.3 (FB), TP15.1 (1_1); also elsewhere on the board
/CPU_PWR/DC_IN: C5.1, C6.1, R38.2, U3.2 (VIN); also elsewhere on the board
ACIN: C61.1, C62.1, C66.1, L7.2, R36.2; also elsewhere on the board
GND: C5.2, C6.2, C46.1, C47.1, C51.2, C54.2, C57.2, C61.2, C62.2, C66.2, C68.2, C71.2, D1.2 (A), IC2.1 (GND), IC2.7 (EP), R33.1, R34.1, R37.1, R39.1, U3.7 (GND), U3.9 (GNDPAD), U4.2 (GND); also elsewhere on the board
IPSOUT: C51.1, U4.4 (VIN); also elsewhere on the board
unnamed: C71.1, R35.1
unnamed: C58.2, D1.1 (K), L7.1, U3.8 (SW)
unnamed: IC2.5 (L), L1.1
unnamed: C58.1, U3.1 (BOOT)
unnamed: C68.1, R35.2, U3.6 (COMP)
unnamed: R38.1, R39.2, U3.3 (EN)
unnamed: R36.1, R37.2, U3.5 (FB)
unnamed: R34.2, U3.4 (RT/CLK)
unnamed: R31.1, U4.1 (EN)
unnamed: R32.1, R33.2, U4.5 (FB)
unnamed: L2.1, U4.3 (SW)

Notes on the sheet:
8.5-60V EXTERNAL
5V/350mA +5V CAN
5V/3.5A ACIN
1.8V/1.0A Vdram

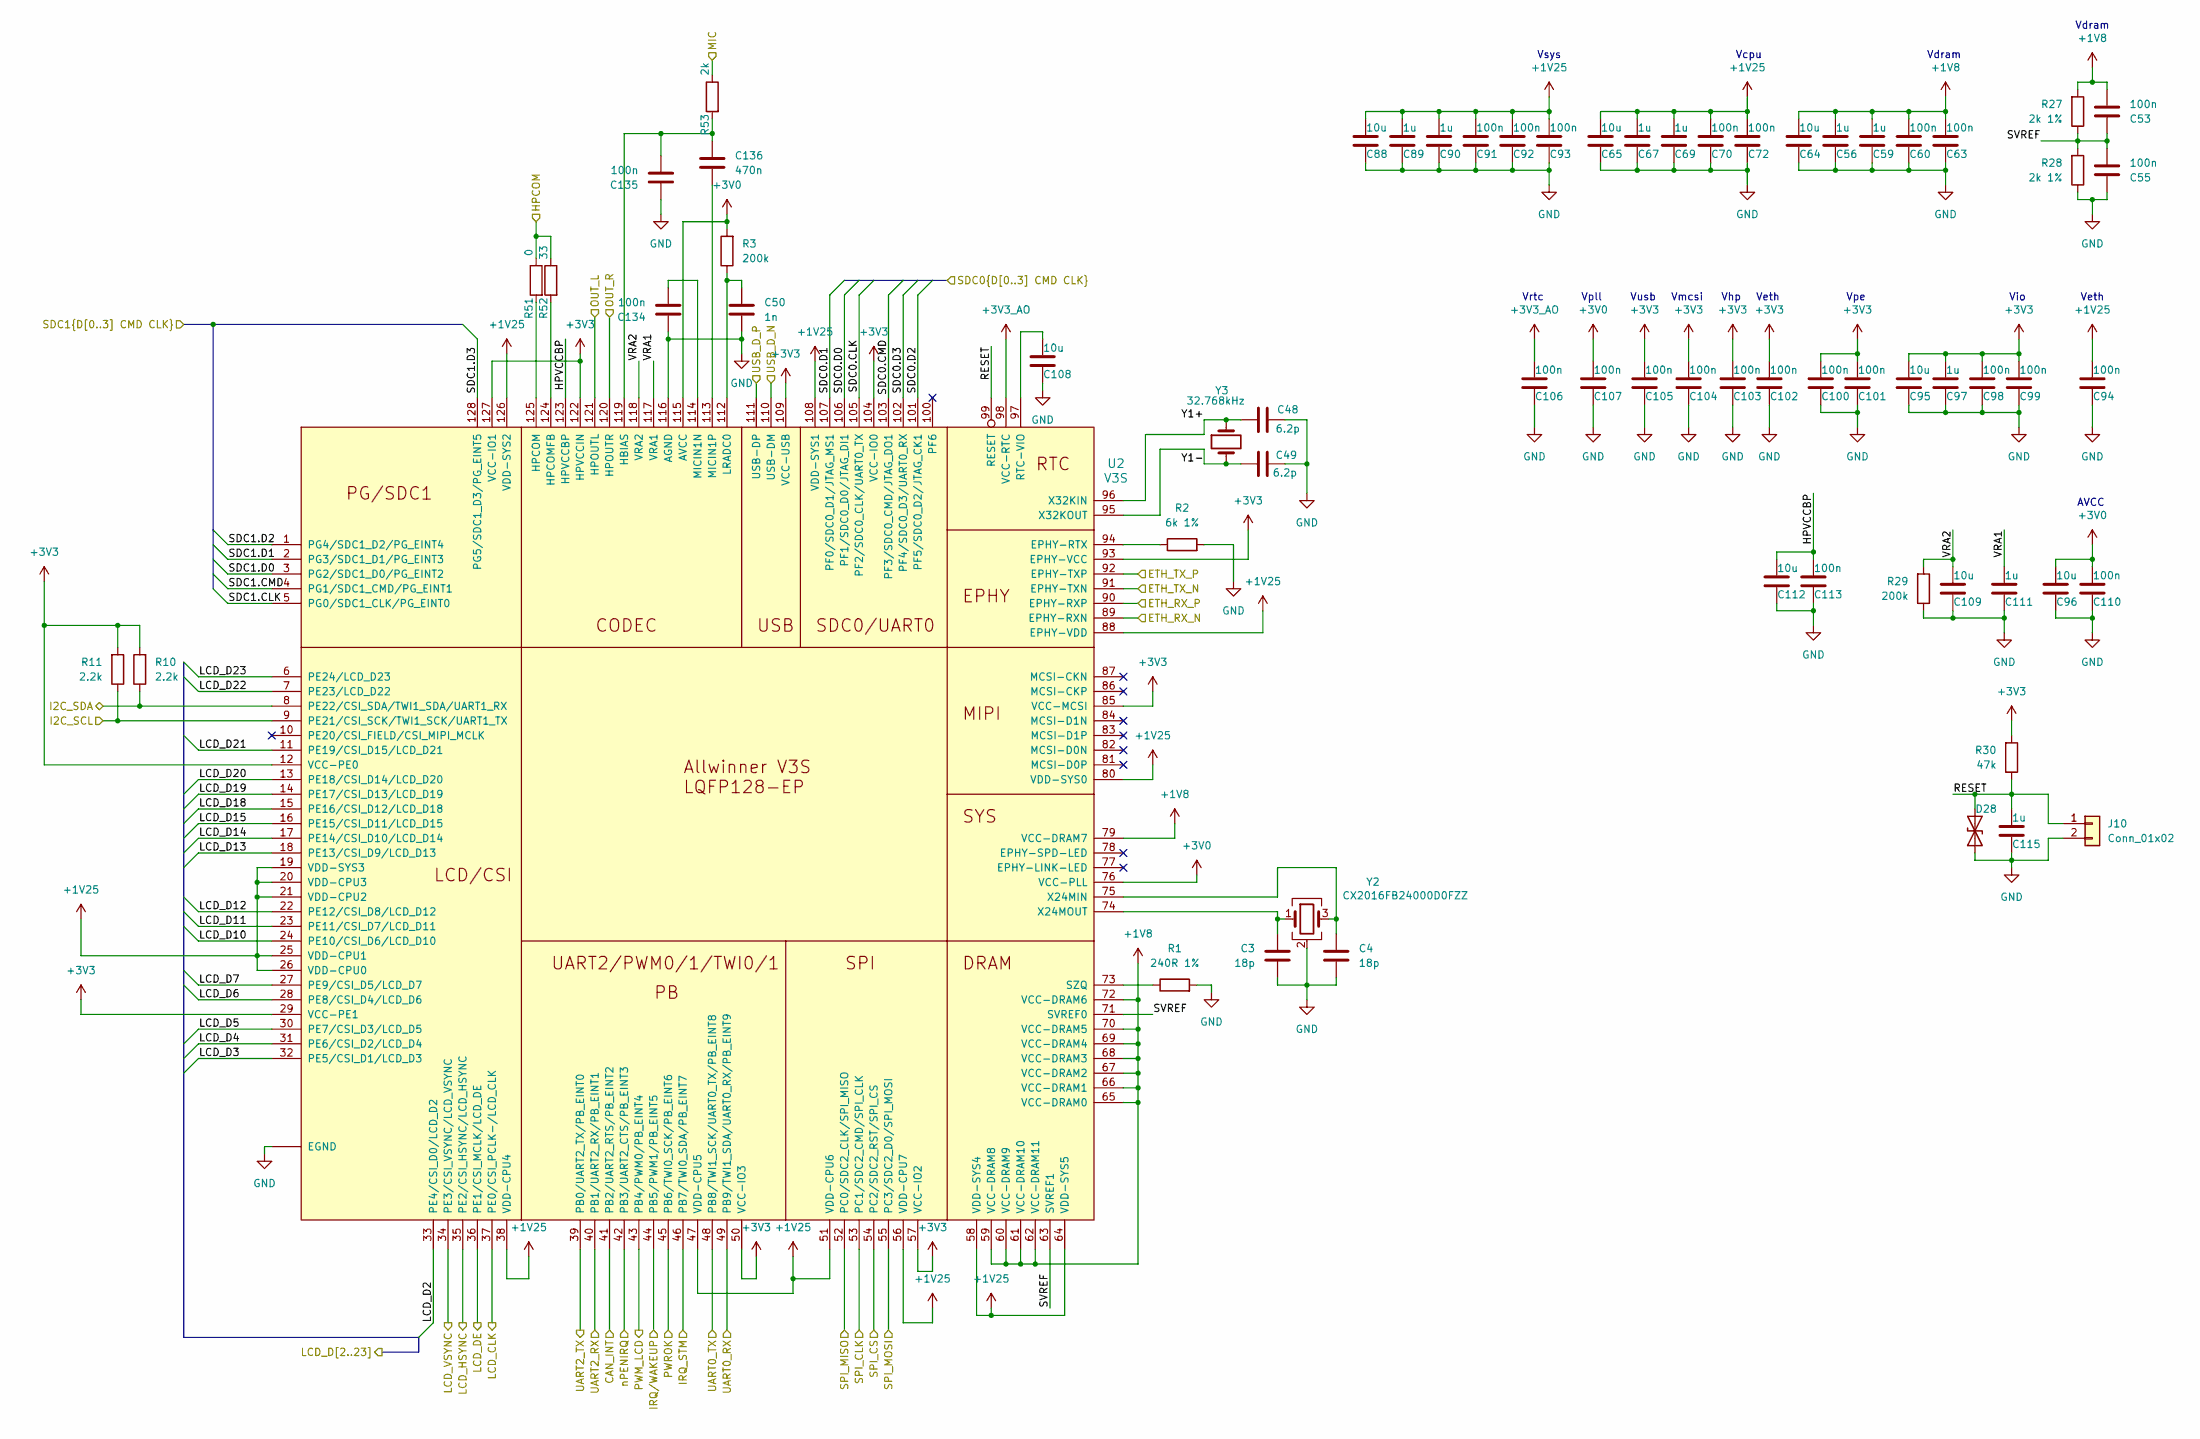
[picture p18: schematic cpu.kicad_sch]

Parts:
C3, C4: 18p; C_0402_1005Metric
C48, C49: 6.2p; C_0402_1005Metric
C50: 1n; C_0603_1608Metric
C53, C55, C60, C63, C70, C72, C91, C92, C93, C94, C98, C99, C100, C101, C102, C103, C104, C105, C106, C107, C110, C113, C134, C135: 100n; C_0603_1608Metric; Manufacturer_Part_Number GRM188R71H104KA93D
C56, C59, C67, C69, C89, C90, C97, C111, C115: 1u; C_0603_1608Metric
C64, C65, C88, C95, C96, C108, C109, C112: 10u; C_0603_1608Metric
C136: 470n; C_0603_1608Metric
D28: STN061050BL40; D_0603_1608Metric
J10: Conn_01x02; PinHeader_1x02_P1.00mm_Vertical
R1: 240R 1%; R_0402_1005Metric
R2: 6k 1%; R_0603_1608Metric
R3, R29: 200k; R_0603_1608Metric
R10, R11: 2.2k; R_0603_1608Metric
R27, R28: 2k 1%; R_0603_1608Metric
R30: 47k; R_0603_1608Metric
R51: 0; R_0603_1608Metric
R52: 33; R_0603_1608Metric; Manufacturer_Part_Number ERJ3EKF1623V
R53: 2k; R_0603_1608Metric
U2: V3S; ELQFP-128
Y2: CX2016FB24000D0FZZ; Crystal_SMD_2016-4Pin_2.0x1.6mm
Y3: 32.768kHz; Crystal_SMD_MicroCrystal_CC7V-T1A-2Pin_3.2x1.5mm; Manufacturer_Part_Number WTL1X80739BEL

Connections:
+1V8: C53.2, C56.2, C59.2, C60.2, C63.2, C64.2, R27.2, U2.59 (VCC-DRAM8), U2.60 (VCC-DRAM9), U2.61 (VCC-DRAM10), U2.62 (VCC-DRAM11), U2.65 (VCC-DRAM0), U2.66 (VCC-DRAM1), U2.67 (VCC-DRAM2), U2.68 (VCC-DRAM3), U2.69 (VCC-DRAM4), U2.70 (VCC-DRAM5), U2.72 (VCC-DRAM6), U2.79 (VCC-DRAM7); also elsewhere on the board
+1V25: C65.2, C67.2, C69.2, C70.2, C72.2, C88.2, C89.2, C90.2, C91.2, C92.2, C93.2, C94.2, U2.19 (VDD-SYS3), U2.20 (VDD-CPU3), U2.21 (VDD-CPU2), U2.25 (VDD-CPU1), U2.26 (VDD-CPU0), U2.38 (VDD-CPU4), U2.47 (VDD-CPU5), U2.51 (VDD-CPU6), U2.56 (VDD-CPU7), U2.58 (VDD-SYS4), U2.64 (VDD-SYS5), U2.80 (VDD-SYS0), U2.88 (EPHY-VDD), U2.108 (VDD-SYS1), U2.126 (VDD-SYS2); also elsewhere on the board
+3V0: C96.2, C107.2, C110.2, R3.2, U2.76 (VCC-PLL), U2.115 (AVCC); also elsewhere on the board
+3V3: C95.2, C97.2, C98.2, C99.2, C100.2, C101.2, C102.2, C103.2, C104.2, C105.2, R10.2, R11.2, R30.2, U2.12 (VCC-PE0), U2.29 (VCC-PE1), U2.50 (VCC-IO3), U2.57 (VCC-IO2), U2.85 (VCC-MCSI), U2.93 (EPHY-VCC), U2.104 (VCC-IO0), U2.109 (VCC-USB), U2.122 (HPVCCIN), U2.127 (VCC-IO1); also elsewhere on the board
+3V3_AO: C106.2, U2.98 (VCC-RTC); also elsewhere on the board
/AUDIO/HPCOM: R51.1, R52.1; also elsewhere on the board
/AUDIO/IN_L: U2.121 (HPOUTL); also elsewhere on the board
/AUDIO/IN_R: U2.120 (HPOUTR); also elsewhere on the board
/AUDIO/MIC: R53.1; also elsewhere on the board
/CAN_BUS/CS: U2.54 (PC2/SDC2_RST/SPI_CS); also elsewhere on the board
/CAN_BUS/IRQ: U2.41 (PB2/UART2_RTS/PB_EINT2); also elsewhere on the board
/CAN_BUS/MISO: U2.52 (PC0/SDC2_CLK/SPI_MISO); also elsewhere on the board
/CAN_BUS/MOSI: U2.55 (PC3/SDC2_D0/SPI_MOSI); also elsewhere on the board
/CAN_BUS/SCK: U2.53 (PC1/SDC2_CMD/SPI_CLK); also elsewhere on the board
/CPU/ETH_RX_N: U2.89 (EPHY-RXN); also elsewhere on the board
/CPU/ETH_RX_P: U2.90 (EPHY-RXP); also elsewhere on the board
/CPU/ETH_TX_N: U2.91 (EPHY-TXN); also elsewhere on the board
/CPU/ETH_TX_P: U2.92 (EPHY-TXP); also elsewhere on the board
/CPU/HPVCCBP: C112.2, C113.2, U2.123 (HPVCCBP)
/CPU/I2C_SCL: R11.1, U2.9 (PE21/CSI_SCK/TWI1_SCK/UART1_TX); also elsewhere on the board
/CPU/I2C_SDA: R10.1, U2.8 (PE22/CSI_SDA/TWI1_SDA/UART1_RX); also elsewhere on the board
/CPU/IRQ_STM: U2.46 (PB7/TWI0_SDA/PB_EINT7); also elsewhere on the board
/CPU/IRQ/WAKEUP: U2.44 (PB5/PWM1/PB_EINT5); also elsewhere on the board
/CPU/LCD_CLK: U2.37 (PE0/CSI_PCLK-/LCD_CLK); also elsewhere on the board
/CPU/LCD_D2: U2.33 (PE4/CSI_D0/LCD_D2); also elsewhere on the board
/CPU/LCD_D3: U2.32 (PE5/CSI_D1/LCD_D3); also elsewhere on the board
/CPU/LCD_D4: U2.31 (PE6/CSI_D2/LCD_D4); also elsewhere on the board
/CPU/LCD_D5: U2.30 (PE7/CSI_D3/LCD_D5); also elsewhere on the board
/CPU/LCD_D6: U2.28 (PE8/CSI_D4/LCD_D6); also elsewhere on the board
/CPU/LCD_D7: U2.27 (PE9/CSI_D5/LCD_D7); also elsewhere on the board
/CPU/LCD_D10: U2.24 (PE10/CSI_D6/LCD_D10); also elsewhere on the board
/CPU/LCD_D11: U2.23 (PE11/CSI_D7/LCD_D11); also elsewhere on the board
/CPU/LCD_D12: U2.22 (PE12/CSI_D8/LCD_D12); also elsewhere on the board
/CPU/LCD_D13: U2.18 (PE13/CSI_D9/LCD_D13); also elsewhere on the board
/CPU/LCD_D14: U2.17 (PE14/CSI_D10/LCD_D14); also elsewhere on the board
/CPU/LCD_D15: U2.16 (PE15/CSI_D11/LCD_D15); also elsewhere on the board
/CPU/LCD_D18: U2.15 (PE16/CSI_D12/LCD_D18); also elsewhere on the board
/CPU/LCD_D19: U2.14 (PE17/CSI_D13/LCD_D19); also elsewhere on the board
/CPU/LCD_D20: U2.13 (PE18/CSI_D14/LCD_D20); also elsewhere on the board
/CPU/LCD_D21: U2.11 (PE19/CSI_D15/LCD_D21); also elsewhere on the board
/CPU/LCD_D22: U2.7 (PE23/LCD_D22); also elsewhere on the board
/CPU/LCD_D23: U2.6 (PE24/LCD_D23); also elsewhere on the board
/CPU/LCD_DE: U2.36 (PE1/CSI_MCLK/LCD_DE); also elsewhere on the board
/CPU/LCD_HSYNC: U2.35 (PE2/CSI_HSYNC/LCD_HSYNC); also elsewhere on the board
/CPU/LCD_VSYNC: U2.34 (PE3/CSI_VSYNC/LCD_VSYNC); also elsewhere on the board
/CPU/PWM_LCD: U2.43 (PB4/PWM0/PB_EINT4); also elsewhere on the board
/CPU/PWROK: U2.45 (PB6/TWI0_SCK/PB_EINT6); also elsewhere on the board
/CPU/RESET: C115.2, D28.2 (A2), J10.1, R30.1, U2.99 (RESET)
/CPU/SDC0.CLK: U2.105 (PF2/SDC0_CLK/UART0_TX); also elsewhere on the board
/CPU/SDC0.CMD: U2.103 (PF3/SDC0_CMD/JTAG_DO1); also elsewhere on the board
/CPU/SDC0.D0: U2.106 (PF1/SDC0_D0/JTAG_DI1); also elsewhere on the board
/CPU/SDC0.D1: U2.107 (PF0/SDC0_D1/JTAG_MS1); also elsewhere on the board
/CPU/SDC0.D2: U2.101 (PF5/SDC0_D2/JTAG_CK1); also elsewhere on the board
/CPU/SDC0.D3: U2.102 (PF4/SDC0_D3/UART0_RX); also elsewhere on the board
/CPU/SDC1.CLK: U2.5 (PG0/SDC1_CLK/PG_EINT0); also elsewhere on the board
/CPU/SDC1.CMD: U2.4 (PG1/SDC1_CMD/PG_EINT1); also elsewhere on the board
/CPU/SDC1.D0: U2.3 (PG2/SDC1_D0/PG_EINT2); also elsewhere on the board
/CPU/SDC1.D1: U2.2 (PG3/SDC1_D1/PG_EINT3); also elsewhere on the board
/CPU/SDC1.D2: U2.1 (PG4/SDC1_D2/PG_EINT4); also elsewhere on the board
/CPU/SDC1.D3: U2.128 (PG5/SDC1_D3/PG_EINT5); also elsewhere on the board
/CPU/SVREF: C53.1, C55.2, R27.1, R28.2, U2.63 (SVREF1), U2.71 (SVREF0)
/CPU/UART0_RX: U2.49 (PB9/TWI1_SDA/UART0_RX/PB_EINT9); also elsewhere on the board
/CPU/UART0_TX: U2.48 (PB8/TWI1_SCK/UART0_TX/PB_EINT8); also elsewhere on the board
/CPU/UART2_RX: U2.40 (PB1/UART2_RX/PB_EINT1); also elsewhere on the board
/CPU/UART2_TX: U2.39 (PB0/UART2_TX/PB_EINT0); also elsewhere on the board
/CPU/USB_D_N: U2.110 (USB-DM); also elsewhere on the board
/CPU/USB_D_P: U2.111 (USB-DP); also elsewhere on the board
/CPU/VRA1: C111.2, U2.117 (VRA1)
/CPU/VRA2: C109.2, R29.2, U2.118 (VRA2)
/CPU/Y1+: C48.2, U2.96 (X32KIN), Y3.1
/CPU/Y1-: C49.2, U2.95 (X32KOUT), Y3.2
/CPU/nPENIRQ: U2.42 (PB3/UART2_CTS/PB_EINT3); also elsewhere on the board
GND: C3.2, C4.2, C48.1, C49.1, C50.2, C55.1, C56.1, C59.1, C60.1, C63.1, C64.1, C65.1, C67.1, C69.1, C70.1, C72.1, C88.1, C89.1, C90.1, C91.1, C92.1, C93.1, C94.1, C95.1, C96.1, C97.1, C98.1, C99.1, C100.1, C101.1, C102.1, C103.1, C104.1, C105.1, C106.1, C107.1, C108.1, C109.1, C110.1, C111.1, C112.1, C113.1, C115.1, C134.1, C135.1, D28.1 (A1), J10.2, R1.2, R2.2, R28.1, R29.1, U2.116 (AGND), U2.GND$1 (EGND), U2.GND$2 (EGND), U2.GND$3 (EGND), U2.GND$4 (EGND), U2.GND$5 (EGND), U2.GND$6 (EGND), U2.GND$7 (EGND), U2.GND$8 (EGND), U2.GND$9 (EGND), Y2.2 (G), Y2.4 (G); also elsewhere on the board
unnamed: R2.1, U2.94 (EPHY-RTX)
unnamed: C135.2, C136.2, R53.2, U2.119 (HBIAS)
unnamed: R51.2, U2.125 (HPCOM)
unnamed: R52.2, U2.124 (HPCOMFB)
unnamed: C50.1, R3.1, U2.112 (LRADC0)
unnamed: C134.2, U2.114 (MICIN1N)
unnamed: C136.1, U2.113 (MICIN1P)
unnamed: C108.2, U2.97 (RTC-VIO)
unnamed: R1.1, U2.73 (SZQ)
unnamed: C4.1, U2.75 (X24MIN), Y2.3
unnamed: C3.1, U2.74 (X24MOUT), Y2.1

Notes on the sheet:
AVCC
Vcpu
Vdram
Vusb
Vmcsi
Vrtc
Veth
Vpe
Vhp
Vio
Vpll
Vsys

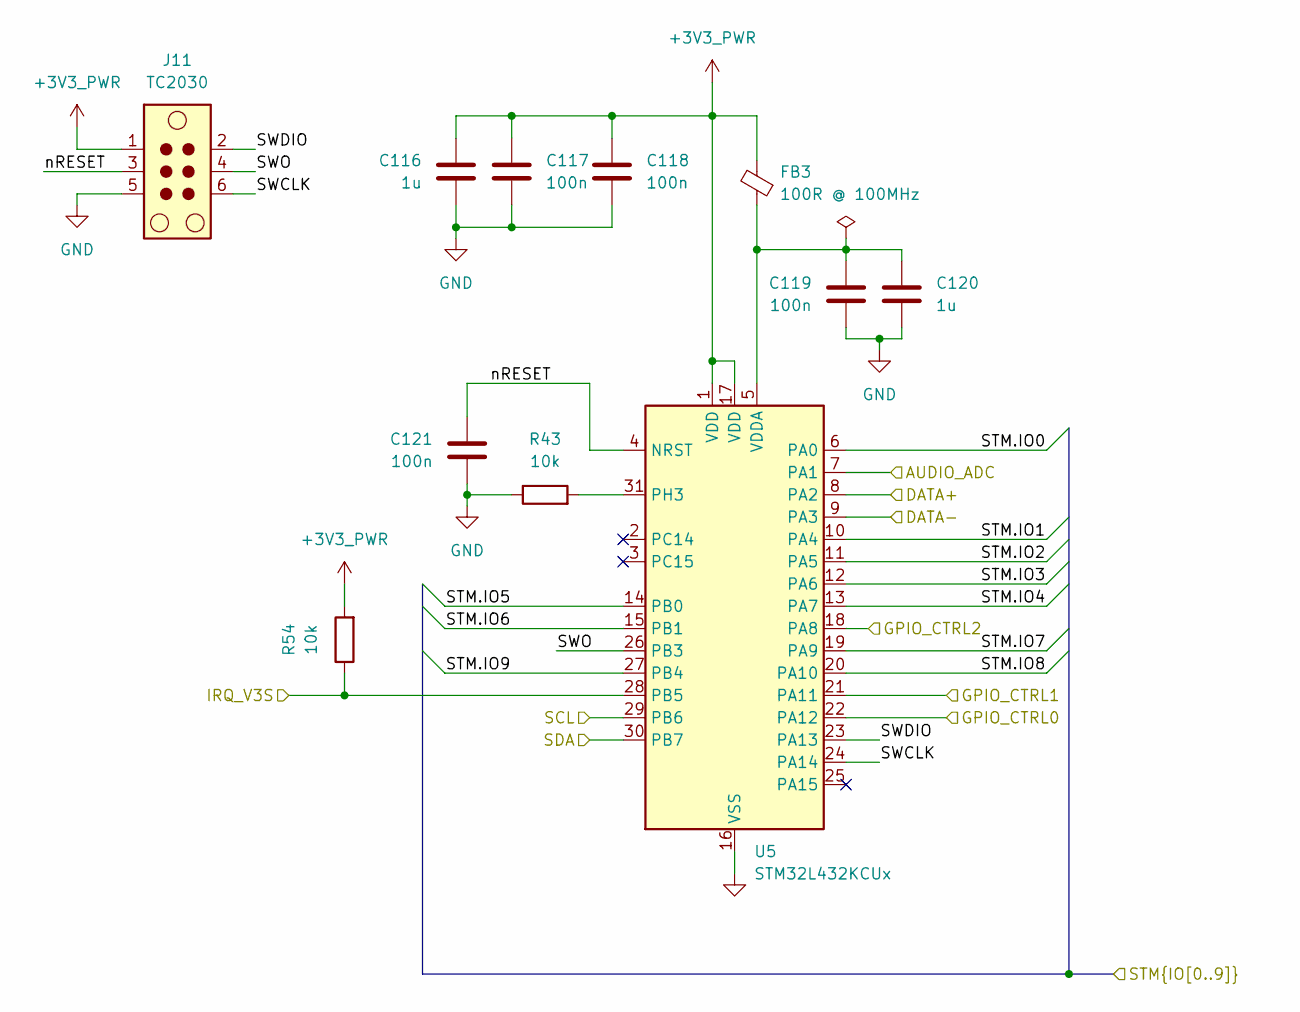
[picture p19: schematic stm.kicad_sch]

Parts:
C116, C120: 1u; C_0603_1608Metric
C117, C118, C119, C121: 100n; C_0603_1608Metric; Manufacturer_Part_Number GRM188R71H104KA93D
FB3: 100R @ 100MHz; L_0603_1608Metric; Manufacturer_Part_Number WLBD1608HCU101TL
J11: TC2030; Tag-Connect_TC2030-IDC-NL_2x03_P1.27mm_Vertical
R43, R54: 10k; R_0603_1608Metric
U5: STM32L432KCUx; QFN-32-1EP_5x5mm_P0.5mm_EP3.1x3.1mm

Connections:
+3V3_PWR: C116.1, C117.2, C118.2, FB3.2, J11.1, R54.2, U5.1 (VDD), U5.17 (VDD); also elsewhere on the board
/AUDIO/ADC_KEY: U5.7 (PA1); also elsewhere on the board
/AUDIO/DATA+/GPIO0: U5.8 (PA2); also elsewhere on the board
/AUDIO/DATA-/GPIO1: U5.9 (PA3); also elsewhere on the board
/AUDIO/EN: U5.18 (PA8); also elsewhere on the board
/AUDIO/G0: U5.22 (PA12); also elsewhere on the board
/AUDIO/G1: U5.21 (PA11); also elsewhere on the board
/CPU/I2C_SCL: U5.29 (PB6); also elsewhere on the board
/CPU/I2C_SDA: U5.30 (PB7); also elsewhere on the board
/CPU/IRQ_STM: R54.1, U5.28 (PB5); also elsewhere on the board
/EXT_CONN/STM.IO0: U5.6 (PA0); also elsewhere on the board
/EXT_CONN/STM.IO1: U5.10 (PA4); also elsewhere on the board
/EXT_CONN/STM.IO2: U5.11 (PA5); also elsewhere on the board
/EXT_CONN/STM.IO3: U5.12 (PA6); also elsewhere on the board
/EXT_CONN/STM.IO4: U5.13 (PA7); also elsewhere on the board
/EXT_CONN/STM.IO5: U5.14 (PB0); also elsewhere on the board
/EXT_CONN/STM.IO6: U5.15 (PB1); also elsewhere on the board
/EXT_CONN/STM.IO7: U5.19 (PA9); also elsewhere on the board
/EXT_CONN/STM.IO8: U5.20 (PA10); also elsewhere on the board
/EXT_CONN/STM.IO9: U5.27 (PB4); also elsewhere on the board
/STM/SWCLK: J11.6, U5.24 (PA14)
/STM/SWDIO: J11.2, U5.23 (PA13)
/STM/SWO: J11.4, U5.26 (PB3)
/STM/nRESET: C121.2, J11.3, U5.4 (NRST)
GND: C116.2, C117.1, C118.1, C119.1, C120.2, C121.1, J11.5, R43.1, U5.16 (VSS), U5.32 (VSS), U5.33 (VSS); also elsewhere on the board
unnamed: R43.2, U5.31 (PH3)
unnamed: C119.2, C120.1, FB3.1, U5.5 (VDDA)

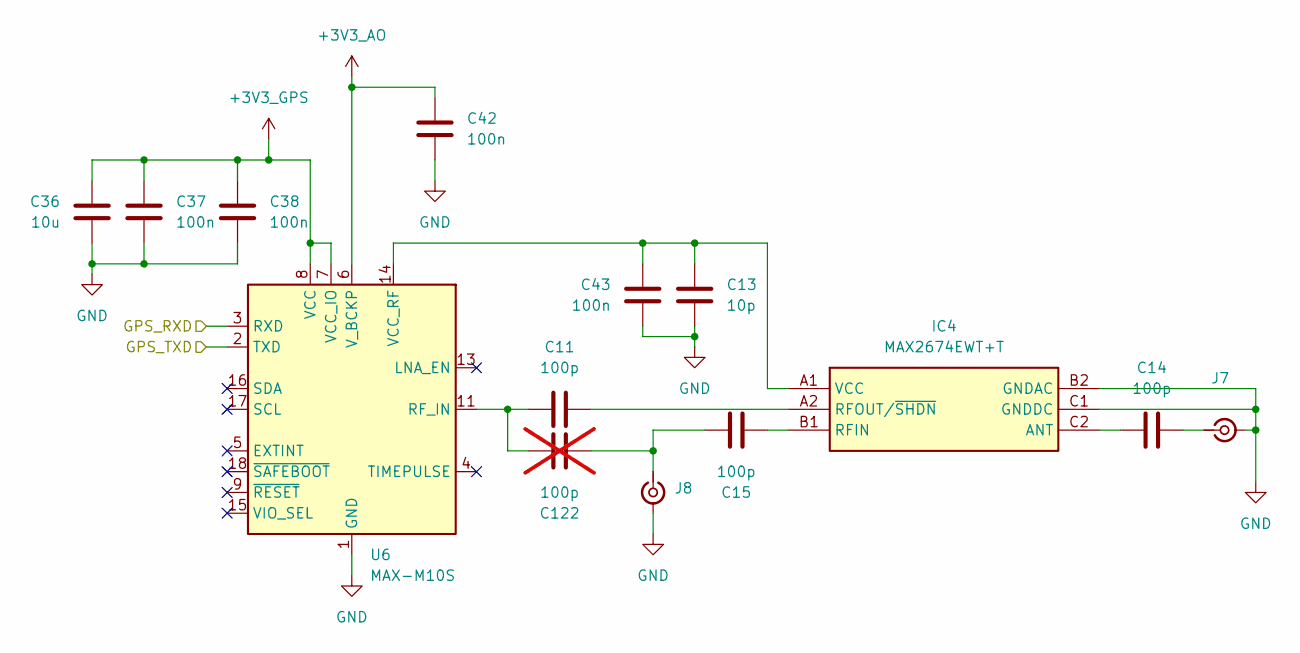
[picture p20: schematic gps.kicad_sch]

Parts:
C11, C14, C15: 100p; C_0402_1005Metric
C13: 10p; C_0402_1005Metric
C36: 10u; C_0603_1608Metric
C37, C38, C42, C43: 100n; C_0603_1608Metric; Manufacturer_Part_Number GRM188R71H104KA93D
C122: 100p; C_0402_1005Metric; not fitted
IC4: MAX2674EWT+T; BGA6C40P2X3_83X123X69; Manufacturer_Part_Number MAX2674EWT+T; Mouser Part Number 700-MAX2674EWT+T
J7, J8: Conn_Coaxial_Small; U.FL_Hirose_U.FL-R-SMT-1_Vertical
U6: MAX-M10S; ublox_MAX

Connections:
+3V3_AO: C42.1, U6.6 (V_BCKP); also elsewhere on the board
+3V3_GPS: C36.1, C37.1, C38.1, U6.7 (VCC_IO), U6.8 (VCC); also elsewhere on the board
/CPU/UART2_RX: U6.2 (TXD); also elsewhere on the board
/CPU/UART2_TX: U6.3 (RXD); also elsewhere on the board
GND: C13.1, C36.2, C37.2, C38.2, C42.2, C43.2, IC4.B2 (GNDAC), IC4.C1 (GNDDC), J7.2 (Ext), J8.2 (Ext), U6.1 (GND), U6.10 (GND), U6.12 (GND); also elsewhere on the board
unnamed: C14.1, IC4.C2 (ANT)
unnamed: C15.2, IC4.B1 (RFIN)
unnamed: C11.2, IC4.A2 (RFOUT/~SHDN)
unnamed: C13.2, C43.1, IC4.A1 (VCC), U6.14 (VCC_RF)
unnamed: C14.2, J7.1 (In)
unnamed: C15.1, C122.2, J8.1 (In)
unnamed: C11.1, C122.1, U6.11 (RF_IN)

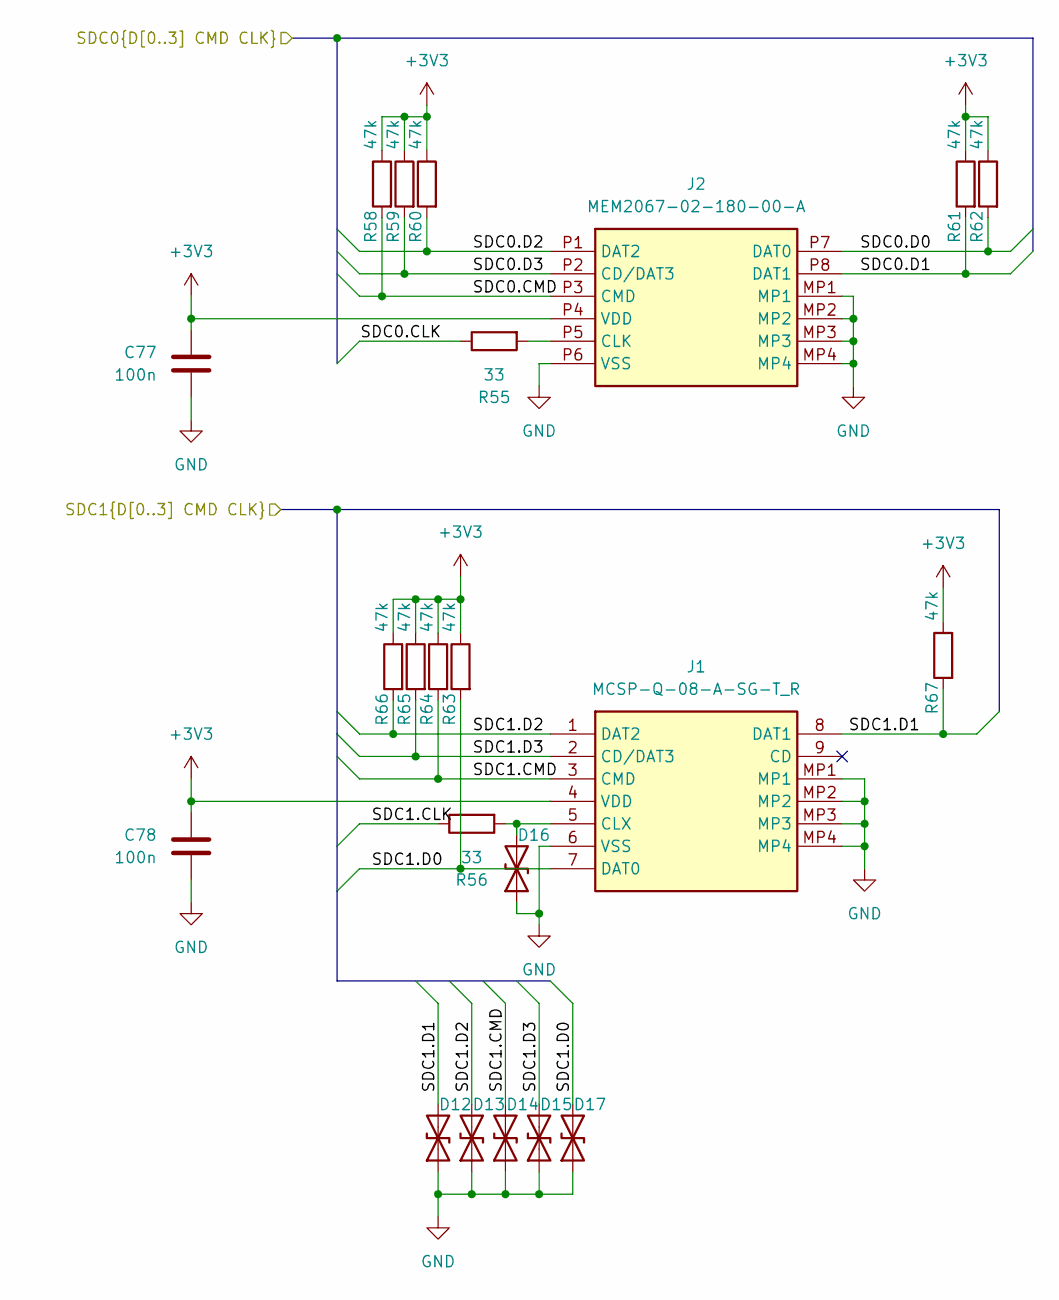
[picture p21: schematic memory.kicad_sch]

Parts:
C77, C78: 100n; C_0603_1608Metric; Manufacturer_Part_Number GRM188R71H104KA93D
D12, D13, D14, D15, D16, D17: STN061050BL40; D_0603_1608Metric
J1: MCSP-Q-08-A-SG-T_R; MCSPQ08ASGTR; Manufacturer_Part_Number MCSP-Q-08-A-SG-T/R
J2: MEM2067-02-180-00-A; MEM20670218000A; Manufacturer_Part_Number MEM2067-02-180-00-A; Mouser Part Number 640-MEM20670218000A
R55, R56: 33; R_0603_1608Metric; Manufacturer_Part_Number ERJ3EKF1623V
R58, R59, R60, R61, R62, R63, R64, R65, R66, R67: 47k; R_0603_1608Metric

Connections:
+3V3: C77.2, C78.2, J1.4 (VDD), J2.P4 (VDD), R58.1, R59.1, R60.1, R61.1, R62.1, R63.1, R64.1, R65.1, R66.1, R67.1; also elsewhere on the board
/CPU/SDC0.CLK: R55.1; also elsewhere on the board
/CPU/SDC0.CMD: J2.P3 (CMD), R58.2; also elsewhere on the board
/CPU/SDC0.D0: J2.P7 (DAT0), R62.2; also elsewhere on the board
/CPU/SDC0.D1: J2.P8 (DAT1), R61.2; also elsewhere on the board
/CPU/SDC0.D2: J2.P1 (DAT2), R60.2; also elsewhere on the board
/CPU/SDC0.D3: J2.P2 (CD/DAT3), R59.2; also elsewhere on the board
/CPU/SDC1.CLK: R56.1; also elsewhere on the board
/CPU/SDC1.CMD: D14.2 (A2), J1.3 (CMD), R64.2; also elsewhere on the board
/CPU/SDC1.D0: D17.2 (A2), J1.7 (DAT0), R63.2; also elsewhere on the board
/CPU/SDC1.D1: D12.2 (A2), J1.8 (DAT1), R67.2; also elsewhere on the board
/CPU/SDC1.D2: D13.2 (A2), J1.1 (DAT2), R66.2; also elsewhere on the board
/CPU/SDC1.D3: D15.2 (A2), J1.2 (CD/DAT3), R65.2; also elsewhere on the board
GND: C77.1, C78.1, D12.1 (A1), D13.1 (A1), D14.1 (A1), D15.1 (A1), D16.1 (A1), D17.1 (A1), J1.6 (VSS), J1.MP1, J1.MP2, J1.MP3, J1.MP4, J2.MP1, J2.MP2, J2.MP3, J2.MP4, J2.P6 (VSS); also elsewhere on the board
unnamed: D16.2 (A2), J1.5 (CLX), R56.2
unnamed: J2.P5 (CLK), R55.2

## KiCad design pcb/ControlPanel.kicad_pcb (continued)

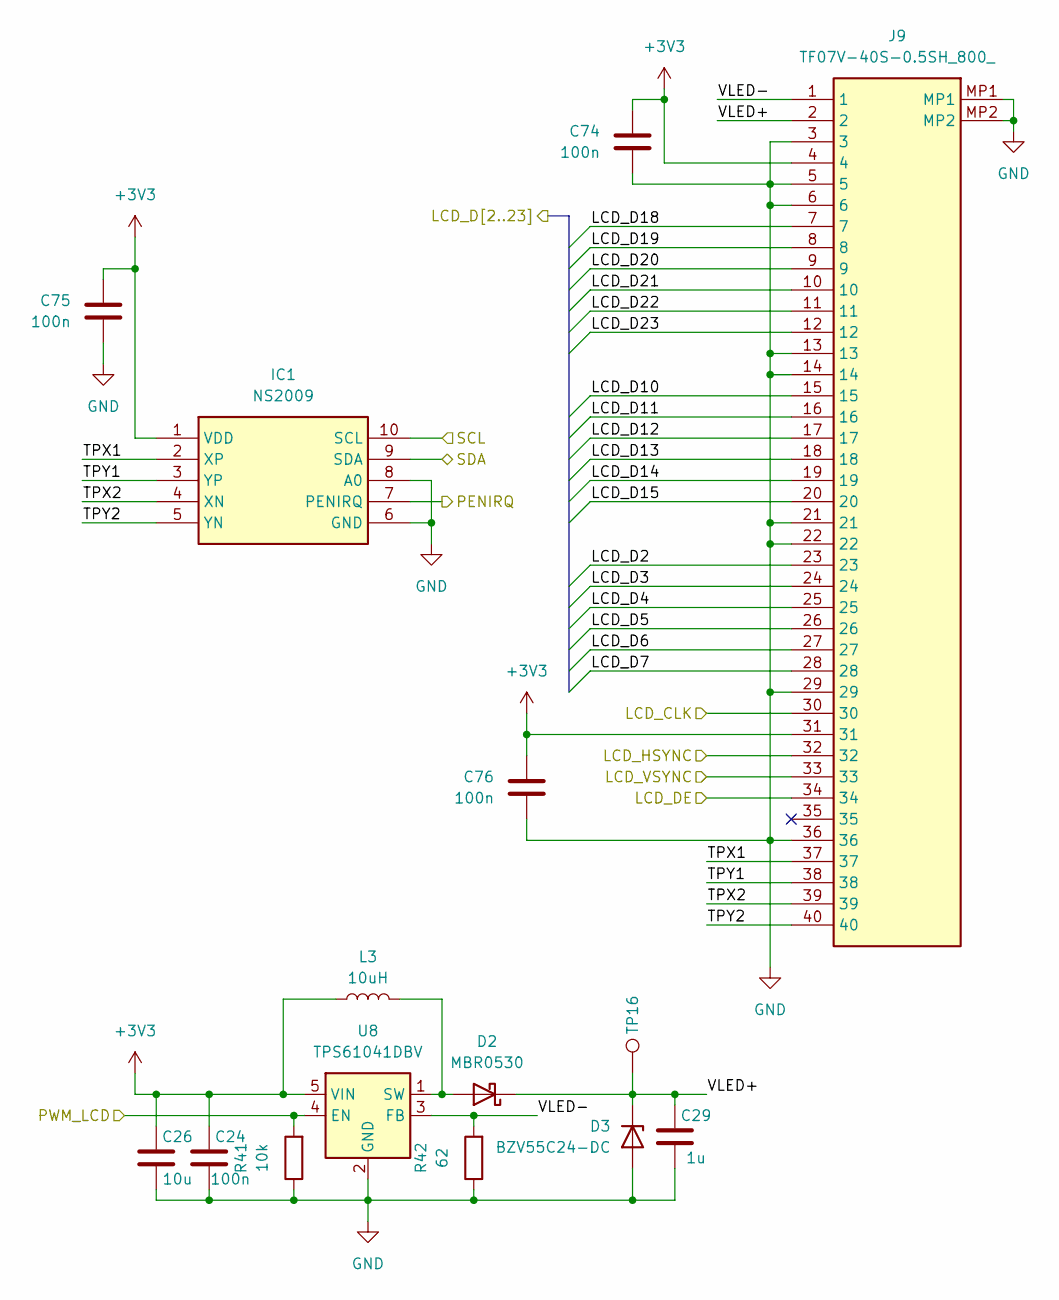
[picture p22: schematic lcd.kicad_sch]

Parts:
C24, C74, C75, C76: 100n; C_0603_1608Metric; Manufacturer_Part_Number GRM188R71H104KA93D
C26: 10u; C_0603_1608Metric
C29: 1u; C_0603_1608Metric
D2: MBR0530; D_SOD-123
D3: BZV55C24-DC; D_MiniMELF
IC1: NS2009; SOP50P490X112-10N; Manufacturer_Part_Number NS2009
J9: TF07V-40S-0.5SH_800_; TF07V40S05SH800; Manufacturer_Part_Number TF07V-40S-0.5SH(800); Mouser Part Number 798-TF07V40S0.5SH800
L3: 10uH; L_1210_3225Metric
R41: 10k; R_0603_1608Metric
R42: 62; R_0603_1608Metric
TP16: TestPoint; TestPoint_Pad_D1.0mm
U8: TPS61041DBV; SOT-23-5

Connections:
+3V3: C24.2, C26.2, C74.2, C75.2, C76.2, IC1.1 (VDD), J9.4, J9.31, L3.1, U8.5 (VIN); also elsewhere on the board
/CPU/I2C_SCL: IC1.10 (SCL); also elsewhere on the board
/CPU/I2C_SDA: IC1.9 (SDA); also elsewhere on the board
/CPU/LCD_CLK: J9.30; also elsewhere on the board
/CPU/LCD_D2: J9.23; also elsewhere on the board
/CPU/LCD_D3: J9.24; also elsewhere on the board
/CPU/LCD_D4: J9.25; also elsewhere on the board
/CPU/LCD_D5: J9.26; also elsewhere on the board
/CPU/LCD_D6: J9.27; also elsewhere on the board
/CPU/LCD_D7: J9.28; also elsewhere on the board
/CPU/LCD_D10: J9.15; also elsewhere on the board
/CPU/LCD_D11: J9.16; also elsewhere on the board
/CPU/LCD_D12: J9.17; also elsewhere on the board
/CPU/LCD_D13: J9.18; also elsewhere on the board
/CPU/LCD_D14: J9.19; also elsewhere on the board
/CPU/LCD_D15: J9.20; also elsewhere on the board
/CPU/LCD_D18: J9.7; also elsewhere on the board
/CPU/LCD_D19: J9.8; also elsewhere on the board
/CPU/LCD_D20: J9.9; also elsewhere on the board
/CPU/LCD_D21: J9.10; also elsewhere on the board
/CPU/LCD_D22: J9.11; also elsewhere on the board
/CPU/LCD_D23: J9.12; also elsewhere on the board
/CPU/LCD_DE: J9.34; also elsewhere on the board
/CPU/LCD_HSYNC: J9.32; also elsewhere on the board
/CPU/LCD_VSYNC: J9.33; also elsewhere on the board
/CPU/PWM_LCD: R41.2, U8.4 (EN); also elsewhere on the board
/CPU/nPENIRQ: IC1.7 (PENIRQ); also elsewhere on the board
/LCD/TPX1: IC1.2 (XP), J9.37
/LCD/TPX2: IC1.4 (XN), J9.39
/LCD/TPY1: IC1.3 (YP), J9.38
/LCD/TPY2: IC1.5 (YN), J9.40
/LCD/VLED+: C29.2, D2.1 (K), D3.1 (K), J9.2, TP16.1 (1_1)
/LCD/VLED-: J9.1, R42.2, U8.3 (FB)
GND: C24.1, C26.1, C29.1, C74.1, C75.1, C76.1, D3.2 (A), IC1.6 (GND), IC1.8 (A0), J9.3, J9.5, J9.6, J9.13, J9.14, J9.21, J9.22, J9.29, J9.36, J9.MP1, J9.MP2, R41.1, R42.1, U8.2 (GND); also elsewhere on the board
unnamed: D2.2 (A), L3.2, U8.1 (SW)

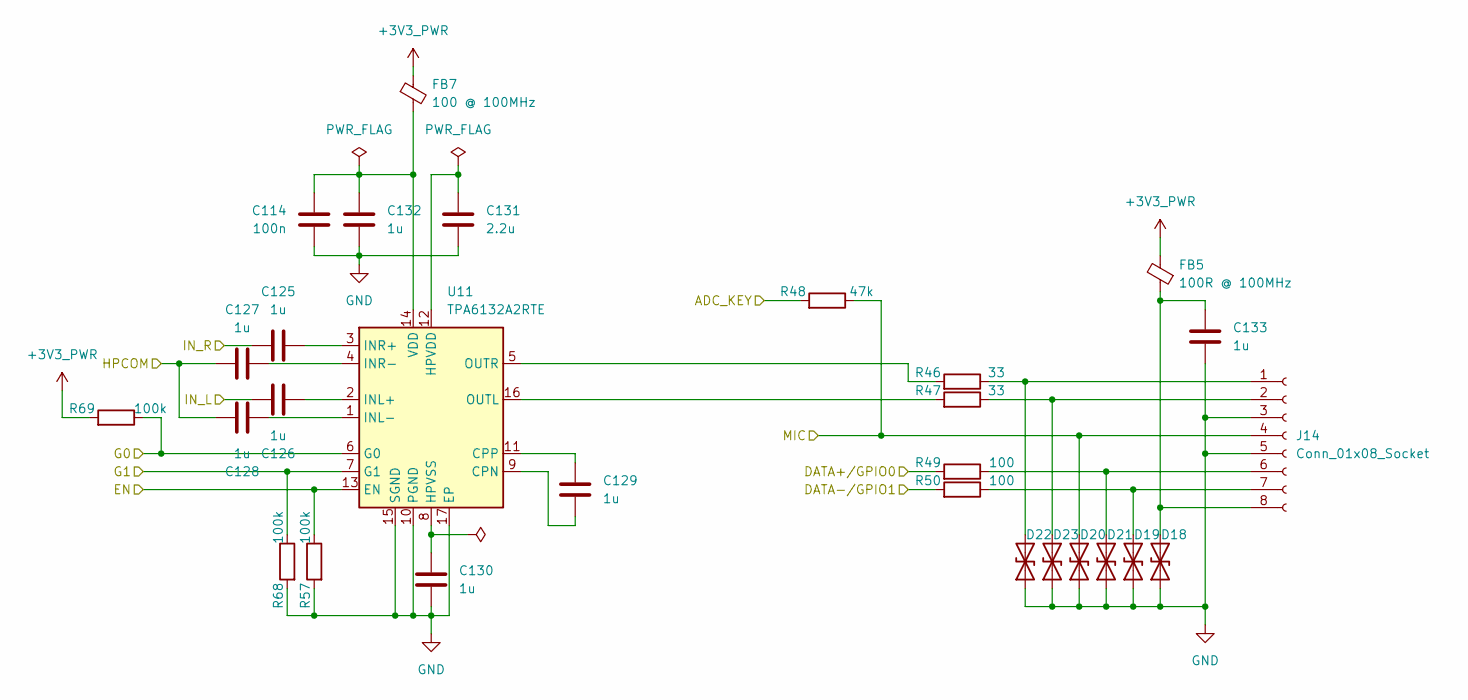
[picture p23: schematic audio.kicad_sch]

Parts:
C114: 100n; C_0603_1608Metric; Manufacturer_Part_Number GRM188R71H104KA93D
C125, C126, C127, C128, C129, C130, C132, C133: 1u; C_0603_1608Metric
C131: 2.2u; C_0603_1608Metric
D18, D19, D20, D21, D22, D23: STN061050BL40; D_0603_1608Metric
FB5: 100R @ 100MHz; L_0603_1608Metric; Manufacturer_Part_Number WLBD1608HCU101TL
FB7: 100 @ 100MHz; L_0603_1608Metric_Pad1.05x0.95mm_HandSolder; Manufacturer_Part_Number WLBD1608HCU101TL
J14: Conn_01x08_Socket; JST_PH_S8B-PH-K_1x08_P2.00mm_Horizontal
R46, R47: 33; R_0603_1608Metric; Manufacturer_Part_Number ERJ3EKF1623V
R48: 47k; R_0603_1608Metric
R49, R50: 100; R_0603_1608Metric
R57, R68, R69: 100k; R_0603_1608Metric
U11: TPA6132A2RTE; WQFN-16-1EP_3x3mm_P0.5mm_EP1.6x1.6mm_ThermalVias

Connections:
+3V3_PWR: FB5.2, FB7.1, R69.2; also elsewhere on the board
/AUDIO/ADC_KEY: R48.2; also elsewhere on the board
/AUDIO/DATA+/GPIO0: R49.2; also elsewhere on the board
/AUDIO/DATA-/GPIO1: R50.2; also elsewhere on the board
/AUDIO/EN: R57.1, U11.13 (EN); also elsewhere on the board
/AUDIO/G0: R69.1, U11.6 (G0); also elsewhere on the board
/AUDIO/G1: R68.1, U11.7 (G1); also elsewhere on the board
/AUDIO/HPCOM: C127.1, C128.1; also elsewhere on the board
/AUDIO/IN_L: C126.2; also elsewhere on the board
/AUDIO/IN_R: C125.1; also elsewhere on the board
/AUDIO/MIC: D20.2 (A2), J14.4, R48.1; also elsewhere on the board
GND: C114.1, C130.2, C131.2, C132.2, C133.2, D18.1 (A1), D19.1 (A1), D20.1 (A1), D21.1 (A1), D22.1 (A1), D23.1 (A1), J14.3, J14.5, R57.2, R68.2, U11.10 (PGND), U11.15 (SGND), U11.17 (EP); also elsewhere on the board
unnamed: C133.1, D18.2 (A2), FB5.1, J14.8
unnamed: D19.2 (A2), J14.7, R50.1
unnamed: D21.2 (A2), J14.6, R49.1
unnamed: D22.2 (A2), J14.1, R46.1
unnamed: D23.2 (A2), J14.2, R47.1
unnamed: C129.2, U11.9 (CPN)
unnamed: C129.1, U11.11 (CPP)
unnamed: C131.1, U11.12 (HPVDD)
unnamed: C130.1, U11.8 (HPVSS)
unnamed: C126.1, U11.2 (INL+)
unnamed: C128.2, U11.1 (INL-)
unnamed: C125.2, U11.3 (INR+)
unnamed: C127.2, U11.4 (INR-)
unnamed: R47.2, U11.16 (OUTL)
unnamed: R46.2, U11.5 (OUTR)
unnamed: C114.2, C132.1, FB7.2, U11.14 (VDD)

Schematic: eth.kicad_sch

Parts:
C18, C31: 100n; C_0603_1608Metric; Manufacturer_Part_Number GRM188R71H104KA93D
C44, C45: 10n; C_0603_1608Metric; Manufacturer_Part_Number GRM1885C1H103JA01J
C52: 1nF/2kV; C_1206_3216Metric; Manufacturer_Part_Number 1206B102K202
C73, C83: 6.8n; C_0603_1608Metric
FB1: 100 @ 100MHz; L_0603_1608Metric_Pad1.05x0.95mm_HandSolder; Manufacturer_Part_Number WLBD1608HCU101TL
R13, R15: 82; R_0603_1608Metric; Manufacturer_Part_Number RC0603JR-0782RL
R14, R16: 49.9; R_0603_1608Metric; Manufacturer_Part_Number CRCW060349R9FKTABC
R17: 10; R_0603_1608Metric
R18, R19: 75; R_0603_1608Metric; Manufacturer_Part_Number 0603SAJ0750T5E
R20, R26: 150; R_0603_1608Metric; Manufacturer_Part_Number 1-2176339-5
T1: H1102NL; SOIC127P940X597-16N; Manufacturer_Part_Number H1102NL
U9, U10: USBLC6-2SC6; SOT-23-6_Handsoldering; Manufacturer_Part_Number USBLC6-2SC6

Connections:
+3V3: FB1.1; also elsewhere on the board
/CPU/ETH_RX_N: U10.3 (I/O2); also elsewhere on the board
/CPU/ETH_RX_P: U10.1 (I/O1); also elsewhere on the board
/CPU/ETH_TX_N: U9.1 (I/O1); also elsewhere on the board
/CPU/ETH_TX_P: U9.3 (I/O2); also elsewhere on the board
/ETH/RD+: C73.2, R13.1, U10.6 (I/O1)
/ETH/RD-: C83.2, R15.1, U10.4 (I/O2)
/ETH/RX+: R20.1, T1.11 (RX+); also elsewhere on the board
/ETH/RX-: R26.1, T1.9 (RX-); also elsewhere on the board
/ETH/TD+: R16.2, T1.1 (TD+), U9.6 (I/O1)
/ETH/TD-: R14.2, T1.3 (TD-), U9.4 (I/O2)
/ETH/TX+: T1.16 (TX+); also elsewhere on the board
/ETH/TX-: T1.14 (TX-); also elsewhere on the board
Earth: C52.2; also elsewhere on the board
GND: C18.2, C31.2, C44.1, C45.2, U9.2 (GND), U10.2 (GND); also elsewhere on the board
unnamed: C52.1, R18.2, R19.2, R20.2, R26.2
unnamed: C44.2, R17.2, T1.2 (CT_1)
unnamed: C45.1, R13.2, R15.2, T1.7 (CT_2)
unnamed: R18.1, T1.10 (NC_3)
unnamed: R19.1, T1.15 (NC_6)
unnamed: C73.1, T1.6 (RD+)
unnamed: C83.1, T1.8 (RD-)
unnamed: C18.1, C31.1, FB1.2, R14.1, R16.1, R17.1, U9.5 (VBUS), U10.5 (VBUS)

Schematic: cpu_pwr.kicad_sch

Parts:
BT1: MS621FE-FL11E; BAT_MS621FE-FL11E; Manufacturer_Part_Number MS621FE-FL11E
C7, C12, C16, C20, C25, C27, C81, C84, C85, C86: 10u; C_0603_1608Metric
C8, C79, C80: 4.7u; C_0603_1608Metric
C9, C10: 1n; C_0603_1608Metric
C17: 10u; C_1206_3216Metric; LCSC C15525
C19, C21, C22, C23, C82: 1u; C_0603_1608Metric
C28, C87: 220n; C_0603_1608Metric
D29, D30, D32: STN061050BL40; D_0603_1608Metric
J3: BATT; JST_PH_S2B-PH-SM4-TB_1x02-1MP_P2.00mm_Horizontal; LCSC C5251182
J4, J5: Conn_01x02; PinSocket_1x02_P2.00mm_Vertical
L8, L10: 4.7uH; L_APV_ANR5040; MPN NRS5040T4R7NMGK
L9: 2.2uH; L_APV_ANR4018; MPN NRS4018T2R2MDGJ
R4: 200k; R_0603_1608Metric
R5: 10k NTC; R_0603_1608Metric
R6: 330k; R_0603_1608Metric
R7: 10k; R_0603_1608Metric
R8, R9: 1k; R_0603_1608Metric
R12: 47k; R_0603_1608Metric
R40: 0.03; R_1206_3216Metric; LCSC C245439
TP7, TP8, TP9, TP10, TP11, TP12, TP13: TestPoint; TestPoint_Pad_D1.0mm
U7: AXP209; AXP209-QFN48

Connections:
+1V25: C10.1, C20.1, L8.1, TP9.1 (1_1), U7.10 (DCDC2); also elsewhere on the board
+3V0: C79.2, TP12.1 (1_1), U7.12 (LDO2); also elsewhere on the board
+3V3: C7.1, C9.1, L9.1, R9.1, R12.2, TP10.1 (1_1), U7.17 (DCDC3); also elsewhere on the board
+3V3_AO: C22.2, TP11.1 (1_1), U7.28 (LDO1); also elsewhere on the board
+3V3_GPS: C80.2, U7.41 (LDO3); also elsewhere on the board
+3V3_PWR: C8.1, TP13.1 (1_1), U7.11 (LDO4); also elsewhere on the board
+BATT: C16.1, C21.1, D32.2 (A2), J3.1, R40.2, U7.38 (BAT@1), U7.39 (BAT@2), U7.42 (BATSENSE)
/CPU/I2C_SCL: U7.2 (SCK); also elsewhere on the board
/CPU/I2C_SDA: U7.1 (SDA); also elsewhere on the board
/CPU/IRQ/WAKEUP: R9.2, U7.48 (IRQ/WAKEUP); also elsewhere on the board
/CPU/PWROK: R12.1, U7.25 (PWROK); also elsewhere on the board
/CPU_PWR/DC_IN: R6.2; also elsewhere on the board
ACIN: C17.2, TP7.1 (1_1), U7.32 (ACIN@1), U7.33 (ACIN@2); also elsewhere on the board
GND: BT1.2 (-), C7.2, C8.2, C9.2, C10.2, C12.2, C16.2, C17.1, C19.1, C20.2, C22.1, C23.1, C25.2, C27.2, C28.2, C79.1, C80.1, C81.2, C82.2, C84.2, C85.2, C86.2, C87.2, D29.1 (A1), D30.1 (A1), D32.1 (A1), J3.2, J4.2, J5.2, R4.1, R5.1, R7.1, U7.4 (N_OE), U7.9 (PGND2), U7.16 (PGND3), U7.22 (AGND), U7.46 (PGND1), U7.GND$1 (EP), U7.GND$2 (EP), U7.GND$3 (EP), U7.GND$4 (EP), U7.GND$5 (EP), U7.GND$6 (EP), U7.GND$7 (EP), U7.GND$8 (EP), U7.GND$9 (EP); also elsewhere on the board
IPSOUT: C25.1, C27.1, C28.1, C81.1, C84.1, C85.1, C86.1, C87.1, TP8.1 (1_1), U7.6 (N_VBUSEN), U7.7 (VIN2), U7.13 (LDO24IN), U7.14 (VIN3), U7.21 (APS), U7.29 (DC3SET), U7.34 (IPSOUT@1), U7.35 (IPSOUT@2), U7.40 (LDO3IN), U7.44 (VIN1); also elsewhere on the board
unnamed: BT1.1 (+), U7.30 (BACKUP)
unnamed: D29.2 (A2), J5.1, R8.2
unnamed: D30.2 (A2), J4.1, R5.2, U7.37 (TS)
unnamed: R4.2, U7.23 (BIAS)
unnamed: C12.1, C21.2, L10.2, R40.1, U7.43 (CHSENSE)
unnamed: R6.1, R7.2, U7.19 (GPIO0)
unnamed: C82.1, U7.26 (VINT), U7.27 (LDO1SET)
unnamed: L10.1, U7.45 (LX1)
unnamed: L8.2, U7.8 (LX2)
unnamed: L9.2, U7.15 (LX3)
unnamed: C23.2, R8.1, U7.47 (PWRON)
unnamed: C19.2, U7.24 (VREF)

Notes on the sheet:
POWER Button
BACKUP Battery
SHORT if battery has NTC, conn/0603 for external NTC

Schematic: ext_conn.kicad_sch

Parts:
C123: 10u / 50V; C_1206_3216Metric
C124: 1n / 50V; C_0603_1608Metric
C137: 1u; C_0603_1608Metric
D5: SMBJ33CA; D_SMB; Manufacturer_Part_Number SMBJ33CA
D7, D10: SMBJ36A-13-F; D_SMB; Manufacturer_Part_Number SMBJ36A-13-F
D8, D11: PMEG6030EP; D_SOD-128; Manufacturer_Part_Number PMEG6030EP
D9: CDSOT23-T24CAN; TSOT-23; Manufacturer_Part_Number CDSOT23-T24CAN
D33, D34, D35, D36, D37, D38, D39, D40, D41, D42, D43: STN061050BL40; D_0603_1608Metric
F1: PTC 2A; Fuse_1812_4532Metric_Pad1.30x3.40mm_HandSolder; Manufacturer_Part_Number SD200-08
FB2, FB4: MFBM1V2012-601-R; L_0805_2012Metric; Manufacturer_Part_Number MFBM1V2012-601-R
FB6: 100R @ 100MHz; L_0603_1608Metric; Manufacturer_Part_Number WLBD1608HCU101TL
FL1: ACT45B-510-2P-TL003; ACT45B1012PTL003; Manufacturer_Part_Number ACT45B-510-2P-TL003; Mouser Part Number 810-ACT45B5102PTL003
GD1, GD2: 3R090-5S; 3R090A5S; Manufacturer_Part_Number Leiditech 3R090-5S
J12: Conn_01x07_Socket; JST_PH_S7B-PH-K_1x07_P2.00mm_Horizontal
J13: Conn_01x05_Socket; JST_PH_S5B-PH-K_1x05_P2.00mm_Horizontal
J15: Conn_01x12_Socket; JST_PH_S12B-PH-K_1x12_P2.00mm_Horizontal
R44, R45: 10R Pulse-proof; R_1206_3216Metric

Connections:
+3V3_PWR: FB6.2; also elsewhere on the board
/CAN_BUS/CAN_H: R44.2; also elsewhere on the board
/CAN_BUS/CAN_L: R45.2; also elsewhere on the board
/CPU_PWR/DC_IN: C123.1, C124.2, D8.1 (K), D10.1 (K), D11.1 (K); also elsewhere on the board
/ETH/RX+: J13.2; also elsewhere on the board
/ETH/RX-: J13.1; also elsewhere on the board
/ETH/TX+: J13.5; also elsewhere on the board
/ETH/TX-: J13.4; also elsewhere on the board
/EXT_CONN/STM.IO0: D33.2 (A2), J15.2; also elsewhere on the board
/EXT_CONN/STM.IO1: D34.2 (A2), J15.3; also elsewhere on the board
/EXT_CONN/STM.IO2: D35.2 (A2), J15.4; also elsewhere on the board
/EXT_CONN/STM.IO3: D36.2 (A2), J15.5; also elsewhere on the board
/EXT_CONN/STM.IO4: D43.2 (A2), J15.6; also elsewhere on the board
/EXT_CONN/STM.IO5: D37.2 (A2), J15.7; also elsewhere on the board
/EXT_CONN/STM.IO6: D38.2 (A2), J15.8; also elsewhere on the board
/EXT_CONN/STM.IO7: D39.2 (A2), J15.9; also elsewhere on the board
/EXT_CONN/STM.IO8: D40.2 (A2), J15.10; also elsewhere on the board
/EXT_CONN/STM.IO9: D42.2 (A2), J15.11; also elsewhere on the board
Earth: GD1.2, GD2.2, J12.7, J13.3; also elsewhere on the board
GND: C123.2, C124.1, C137.2, D7.2 (A), D9.3 (common), D10.2 (A), D33.1 (A1), D34.1 (A1), D35.1 (A1), D36.1 (A1), D37.1 (A1), D38.1 (A1), D39.1 (A1), D40.1 (A1), D41.1 (A1), D42.1 (A1), D43.1 (A1), FB4.2, J15.12; also elsewhere on the board
unnamed: D5.1 (A1), FB4.1, GD1.3, J12.3, J12.4
unnamed: D5.2 (A2), F1.2, FB2.1
unnamed: D9.1 (A1), FL1.1, GD2.3, J12.6
unnamed: D9.2 (A2), FL1.2, GD2.1, J12.5
unnamed: D7.1 (K), D8.2 (A), D11.2 (A), FB2.2
unnamed: C137.1, D41.2 (A2), FB6.1, J15.1
unnamed: FL1.3, R44.1
unnamed: FL1.4, R45.1
unnamed: F1.1, GD1.1, J12.1, J12.2

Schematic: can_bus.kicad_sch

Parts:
C1, C2: 18p; C_0402_1005Metric
C30, C32, C33, C35: 100n; C_0603_1608Metric; Manufacturer_Part_Number GRM188R71H104KA93D
C34: 10u; C_1206_3216Metric; LCSC C15525
C39: 4.7n; C_0603_1608Metric
C40, C41: 4.7p; C_0603_1608Metric
IC3: ATA6561-GAQW-N; SOIC127P600X175-8N; Manufacturer_Part_Number ATA6561-GAQW-N; Mouser Part Number 579-ATA6561-GAQW-N
Q2: BSS138; SOT-23; Manufacturer_Part_Number BSS138
R21, R22: 59; R_0603_1608Metric
R23: 560; R_0603_1608Metric
R24, R25: 100k; R_0603_1608Metric
TP5, TP6: TestPoint; TestPoint_Pad_D1.0mm
U1: MCP2518FD-xQBB; DFN-14-1EP_3x4.5mm_P0.65mm_EP1.65x4.25mm
U701, U702: GAQY212GS; SOP-4_3.8x4.1mm_P2.54mm; Manufacturer_Part_Number GAQY212GS
Y1: 3225-20M-SR; Crystal_SMD_3225-4Pin_3.2x2.5mm

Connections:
+3V3_PWR: C30.2, C32.1, C33.1, IC3.5 (VIO), U1.14 (VDD); also elsewhere on the board
+5V: C34.1, C35.1, IC3.3 (VCC), R23.1; also elsewhere on the board
/CAN_BUS/CAN_H: C41.1, IC3.7 (CANH), R22.1; also elsewhere on the board
/CAN_BUS/CAN_L: C40.1, IC3.6 (CANL), R21.1; also elsewhere on the board
/CAN_BUS/CS: U1.13 (~CS); also elsewhere on the board
/CAN_BUS/IRQ: U1.4 (~INT); also elsewhere on the board
/CAN_BUS/MISO: U1.11 (SDI); also elsewhere on the board
/CAN_BUS/MOSI: U1.12 (SDO); also elsewhere on the board
/CAN_BUS/SCK: U1.10 (SCK); also elsewhere on the board
GND: C1.2, C2.2, C30.1, C32.2, C33.2, C34.2, C35.2, C39.2, C40.2, C41.2, IC3.2 (GND), Q2.2 (S), R24.2, R25.1, U1.7 (VSS), U1.15 (VSS), Y1.2 (G), Y1.4 (G); also elsewhere on the board
unnamed: C39.1, U701.3, U702.4
unnamed: IC3.4 (RXD), TP5.1 (1_1), U1.2 (RXCAN)
unnamed: IC3.8 (STBY), R25.2, U1.9 (~INT0/GPIO0/XSTBY)
unnamed: IC3.1 (TXD), TP6.1 (1_1), U1.1 (TXCAN)
unnamed: Q2.3 (D), U702.2
unnamed: Q2.1 (G), R24.1, U1.8 (~INT1/GPIO1)
unnamed: R21.2, U702.3
unnamed: R22.2, U701.4
unnamed: R23.2, U701.1
unnamed: C1.1, U1.6 (OSC1), Y1.3
unnamed: C2.1, U1.5 (OSC2), Y1.1
unnamed: U701.2, U702.1

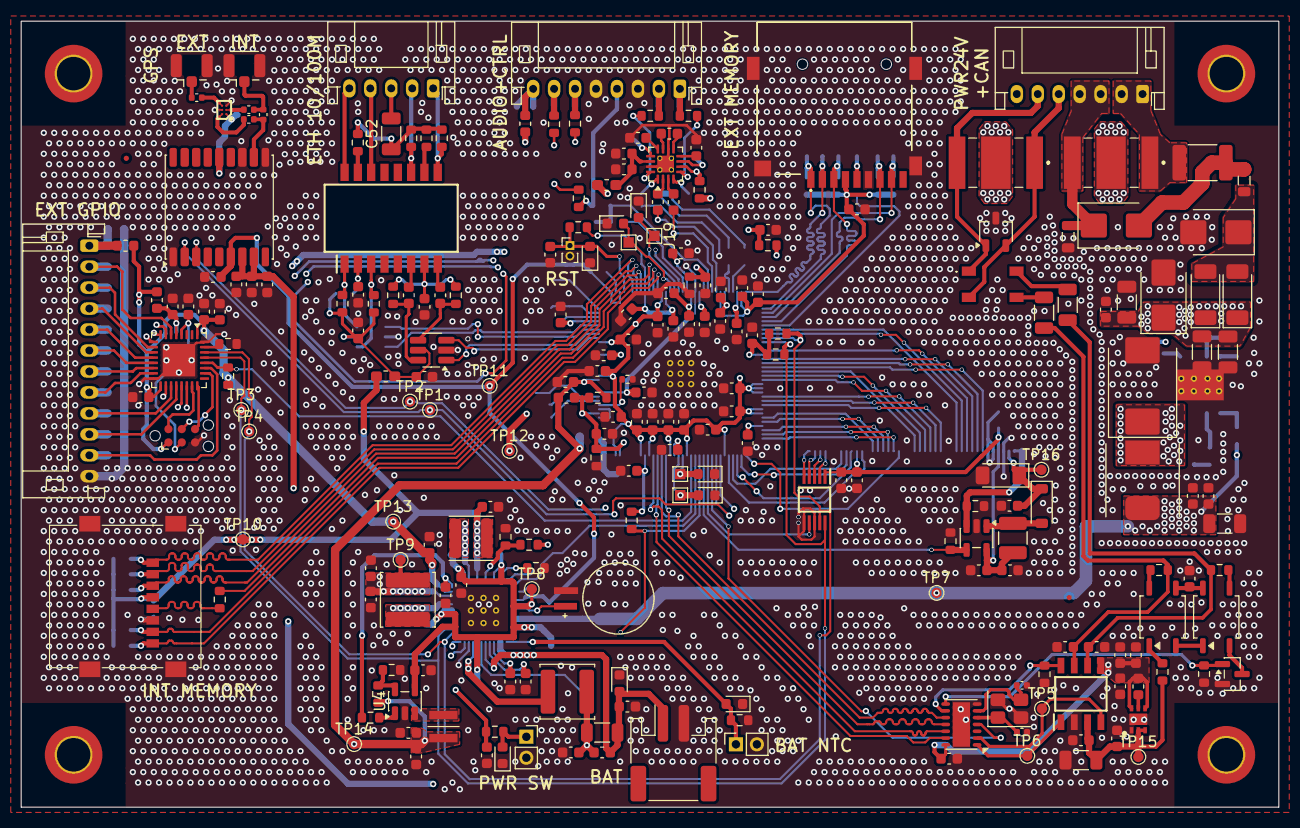
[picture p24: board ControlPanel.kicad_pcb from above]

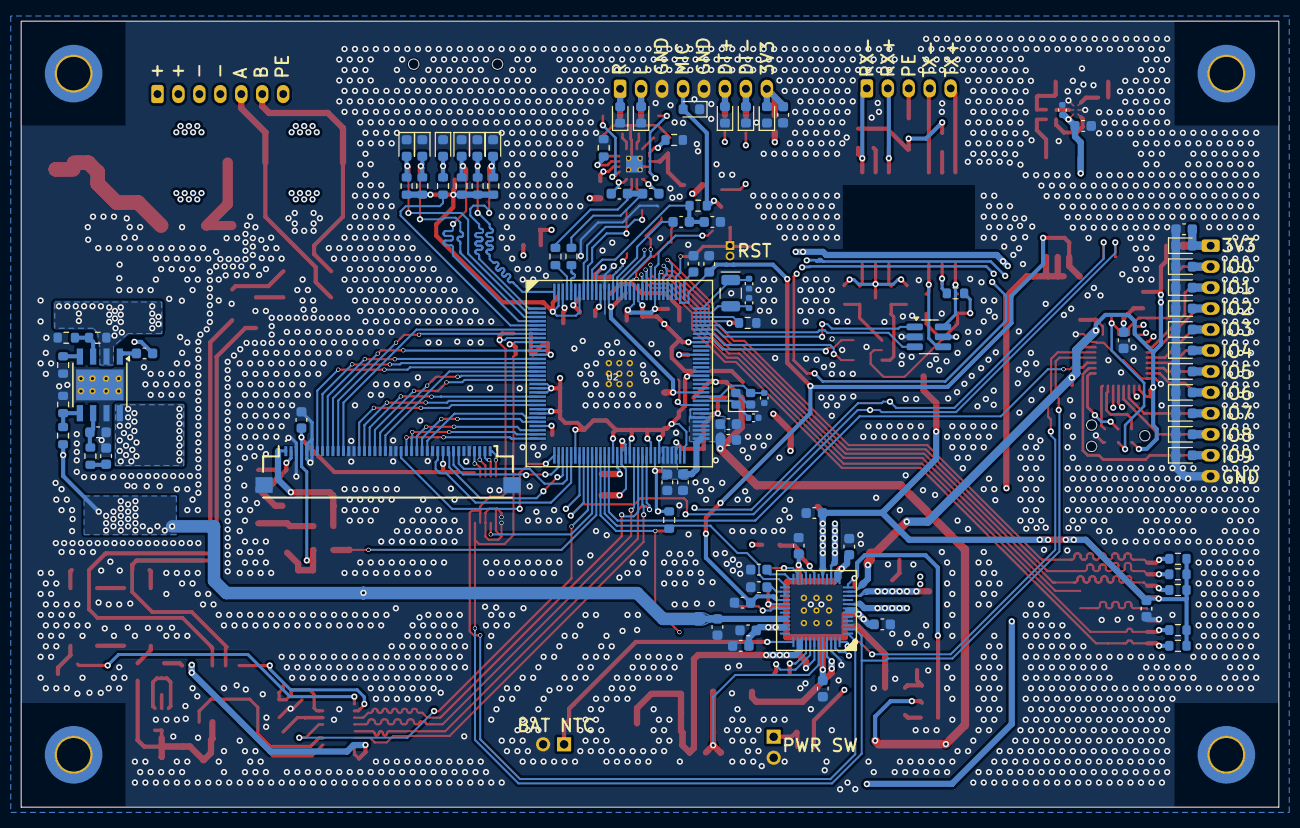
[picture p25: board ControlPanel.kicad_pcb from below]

Board: 4 copper layers, 120.0 x 75.0 mm, 327 parts (90 on the bottom side), 208 nets.

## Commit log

2026-08-09 Reorganizacja: podzial na hardware/ i firmware/ przed publikacja jako osobne repo
    pcb/, media/, prod/, analysis/, TODO.md oraz czesc doc/ -> hardware/
    tools/ oraz reszta doc/ -> firmware/ (firmware/CanSensorHub-v3s,
    LicheePi-support, StmCompanion juz tam byly)
    doc/TERMINAL_RECZNY_DECYZJE_PROJEKTOWE.md skopiowany do obu (dotyczy
    zarowno hardware jak i firmware terminala).
    Kazdy podfolder dostaje wlasny README.md, LICENSE i .gitignore - to one
    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
    [CG0402MLC.step, CRYSTAL-3225.step, CUI_CDM-10008.step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]
2026-08-10 More cleaning
    [CG0402MLC.step, CRYSTAL-3225.step, CUI_CDM-10008.step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]
2026-08-25 DRC fixes and exclusions
    [ControlPanel.kicad_pcb]
2026-08-26 Unify values/footprints per checklist, add via-in-pad DRC rule, regenerate outputs
    [ControlPanel.csv, ControlPanel.kicad_pcb, cpu.kicad_sch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]
2026-09-28 Final fixes
    [ControlPanel.kicad_pcb, ControlPanel.kicad_sch, cpu_pwr.kicad_sch]
2026-09-28 Regenerate interactive BOM, add ready-to-order status to README, remove stale gerber zip
2026-09-28 Fix BOM data: correct MPN for 33R resistors (R52/R55/R56), BOM export settings
    [ControlPanel.kicad_sch, audio.kicad_sch, can_bus.kicad_sch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]
2026-09-28 Regenerate production outputs and gerber zip after BOM field fixes
2026-11-08 Order prep: TerminalVoIP variants, unify FB value (100 @ 100MHz), test pads J4/J5/J10 excluded from BOM, zones, PCB update; regenerate gerber zip, BOM and PDFs
2026-11-08 BOM fields: MPN / Manufacturer / LCSC / TME / Mouser from Big_order_2026 rev.2 order (unified part numbers), old sourcing fields (Manufacturer_Part_Number, MF, MP, Mouser/Arrow/TME price fields, Snap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
2026-11-08 PCB updated from schematic (F8: MPN/LCSC/TME/Mouser fields); regenerate gerber zip, iBOM (MPN/LCSC/TME/Mouser columns), BOM and PDFs
